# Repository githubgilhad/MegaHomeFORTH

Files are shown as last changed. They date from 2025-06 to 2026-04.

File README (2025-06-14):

Mega Home Computer with FORTH - based on ATmega2560 - step to graphic card for HD6309 - VGA, RCA, PS/2

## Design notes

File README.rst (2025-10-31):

.. vim: set ft=rst noexpandtab fileencoding=utf-8 nomodified   wrap textwidth=0 foldmethod=marker foldmarker={{{,}}} foldcolumn=4 ruler showcmd lcs=tab\:|- list tabstop=8 noexpandtab nosmarttab softtabstop=0 shiftwidth=0 linebreak showbreak=»\

.. |Ohm| raw:: html

	Ω

.. |kOhm| raw:: html

	kΩ

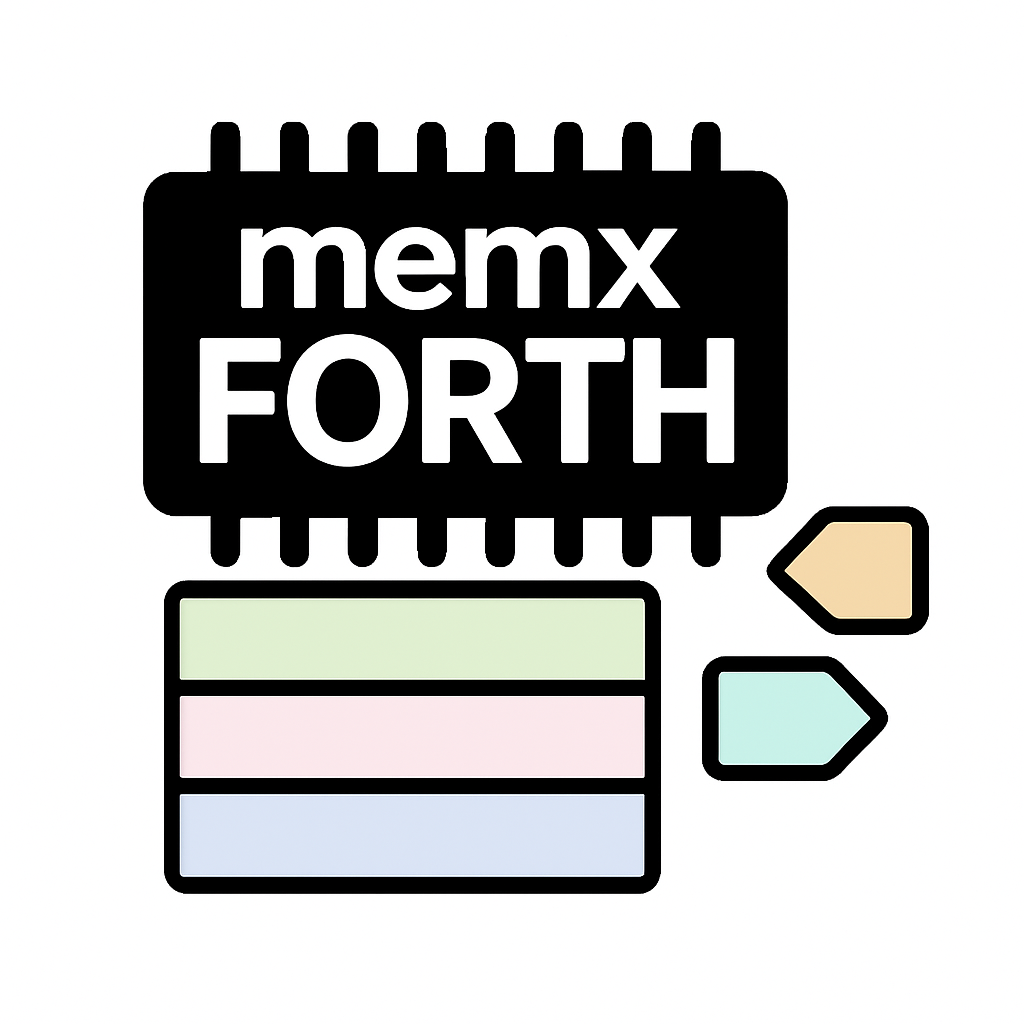
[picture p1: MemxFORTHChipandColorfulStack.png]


Many thanks to `PCBway <https://www.pcbway.com/>`__, which sponsored this project by manufacturing the PCB for free. The code for this PCB is **W828834AS5P3** and I created it as free project  here `<https://www.pcbway.com/project/shareproject/W828834AS5P3_MegaHomeFORTH_MHF_001_cheap_computer_with_VGA_PS_2_SD_card_ba_2abd40e2.html>`__

MHF-002
========

Actual version is `MHF-002 <HW/KiCad/MHF-002/>`__ with over 75 improvements (see `documentation <docs/MHF-002/README.rst>`__)

**MHF-001** results:
====================

The **PCBway** PCB was excelent. Communications with PCBway was easy and straightforward, PCB was made exactly to my specification and it was delivered in good time too. Packaging was standart and the PCB was perfect. It was easy to solder, desolder, resolder parts as the testing went and the PCB was not damaged even with some parts (like USB connector) was resoldered many times.

The PCB was perfect, there is nothing what could be improved on the manufacturing. Bad design decisions are problem on my side, PCBway could not discover or prevent them :)

**I will fully recomend PCBway as PCB manufacturer.**

Also their sponsorship encouraged me to speed progress on this project and to write about it, which is really important part. I thank PCBway for their encouragement.

I did run into lot of problems in this project, many of them was on my part, some not (none on PCBway part)

- I found error in compiler (it is fixed now and was really obscure `<https://gcc.gnu.org/bugzilla/show_bug.cgi?id=119989>`__ )
- CH341G is not fully supported in kernel. There is an unofficial fix, but I may add another option too. And I need way to disable this chip alltogether, to be able use Serial + DTR + line flow over connector (and not fight signalling from chip)
- I underestimated how difficult is to reliably handsolder MCU and memories - I will make better footprints for it, and for USB too
- I had no testing program for the HW
- bad understanding of some technicalities (like that RTS/CTS are crossed between MCU and CH341G in similar way as RX/TX)
- bad planning for port usage 
	- VGA output must be on lower port, which allows **OUT** instruction - **STS** is one tick slower and it matter
	- CTS(in) should be on some Pin Change Interrupt pin
- **74HC165** is level driven so manipulating it "manually" leads to doubled first bit value, I will use **74KC166**, which is edge driven, to prevent this problem
- USB connector is better to be massive (like USB A) and easily repaired (as it is physically manipulated often) - and rather be on small module for repairability
- I need even better testability - more pinheaders, add GND (and maybe +5V) to each connector etc...
- see `<https://github.com/githubgilhad/MegaHomeFORTH/tree/master/docs/MHF-001#errata-and-improvements>`__ for more details

All in all - I will make another PCB. This one is OK, but I have much better design ideas now.

MegaHomeFORTH
=============

Mega Home Computer with FORTH on ATmega2560 - step to graphic card for HD6309 - VGA, RCA, PS/2 - see `Larger Picture`_

This project is more about the HW part of solution (but with enought SW to be fully tested and expanded (will be build on the way)).

Look at `MHF-001 <docs/MHF-001/>`__ for actual progress just now

Index
-----

- `MegaHomeFORTH`_
	- `Project Goals`_
	- `Larger Picture`_
	- `Progress`_

Project Goals
==============

Depending on how much components will be soldered to the PCB, it could offer many things (at cost of using some pins):

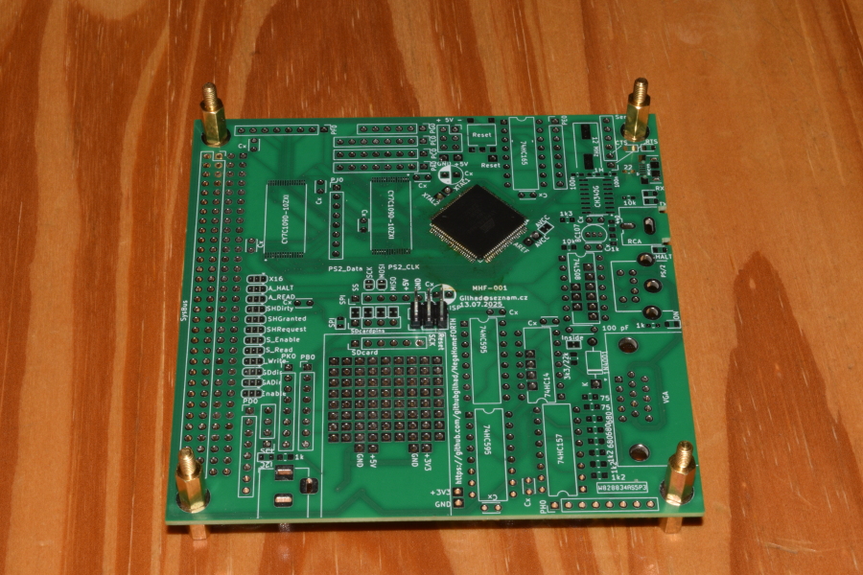
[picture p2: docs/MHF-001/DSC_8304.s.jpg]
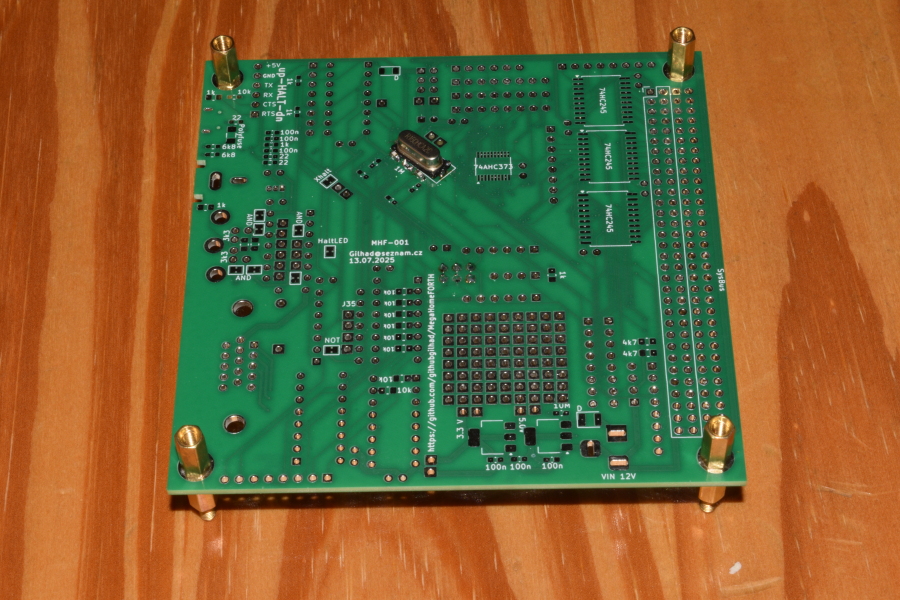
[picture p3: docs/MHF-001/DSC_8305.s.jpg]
- full breakout of ATmega2560 - like Arduino Mega, but **all** pins accessible - simply, plain, 86 I/O pins    `blink_all <https://github.com/githubgilhad/memxFORTH-asm/tree/master/SW/progs/demo/blink_all>`__ 
- USB serial connection - 2 pins
- memory extended to 64 kB RAM - at cost of 16+4 pins
- another 128 kB RAM (somehow) accessible - another 24+3 pins
	- and shared over bus with HD6309/6502/other 8 bit computer - +5pins?
- VGA output (~40x25 characters text screen or 320x200 B/W graphic) - 8+3 pins
	- 4+4 bits forefround+background colors for full text lines (or single graphic lines) - 8 pins
- RCA ("composite") B/W output ( can do this OR VGA, not both at the same time, but may switch it SW way ) - 3 pins
- PS/2 input - 2 or 8+1 pins (much smoother operation)
- SD card reader (may interfere with video interrupts?) - 4pins

In full power it can serve as SBC (Single Board Computer) - or as inteligent Video+Keyboard card for 8 bit computer.

Larger Picture
===============

This project is based on:

- `NanoHomeComputer <https://github.com/githubgilhad/NanoHomeComputer>`__ for HW part
	-  which is based on `Squeezing Water from Stone 3: Arduino Nano + 1(!) Logic IC = Computer with VGA and PS/2 <https://github.com/slu4coder/YouTube>`__ and `Composite video from Arduino UNO <https://www.youtube.com/watch?v=Th18tLP86WQ>`__
- `memxFORTH-core <https://github.com/githubgilhad/memxFORTH-core>`__ for using 24bit pointers on ATmega2560
- `pcFORTH-core <https://github.com/githubgilhad/pcFORTH-core.git>`__ for bigger FORTH implementation
- many different internet sources, discussions and hints

It is another step to retrocomputer based on HD6309 - see `some <http://comp24.gilhad.cz/Comp24-specification.html>`__ `pages <http://comp24.gilhad.cz/documentation/Comp24.html>`__ for basic idea.

Video part was successfully tested on `NanoHomeComputer <https://github.com/githubgilhad/NanoHomeComputer>`__, but ATmega328P with only 2kB RAM and 32kB Flash was too limiting for larger project

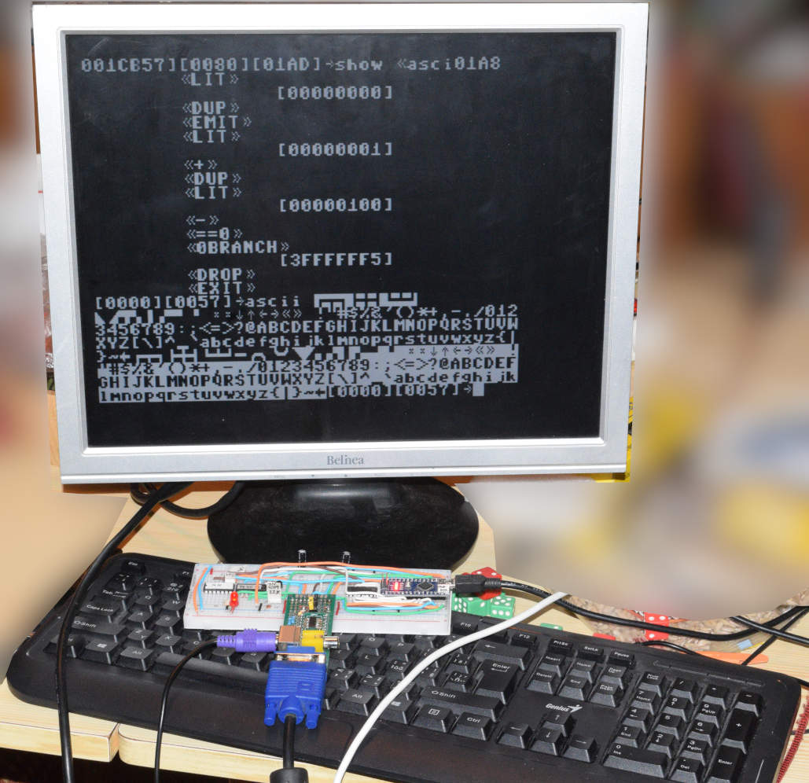
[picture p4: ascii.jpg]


Progress
========

`MHF-001 <docs/MHF-001/>`__

Soldering parts and testing.

Done:

* get Arduino Mega Pro
* get 16MHz to output
* map pins in NanoHomeComputer
* map pins on ATmega2560
* map timers in NanoHomeComputer
* assign VGA/RCA/PS2 pins to ATmega2560
* test VGA output
* test RCA output
* test PS/2 direct input
* test PS/2 8bit input
* assign rest pins on ATmega2560
* draw schema `<HW/KiCad/MHF-001/MHF-001.pdf>`_
* draw PCB
* order PCB
* get PCB manufactured `<HW/KiCad/MHF-001/output.zip>`_

Next steps:

* solder component   ... see `MHF-001 <docs/MHF-001/>`__

* test each goal ... see `MHF-001 <docs/MHF-001/>`__
* physical tests
* programming
* enjoy :)

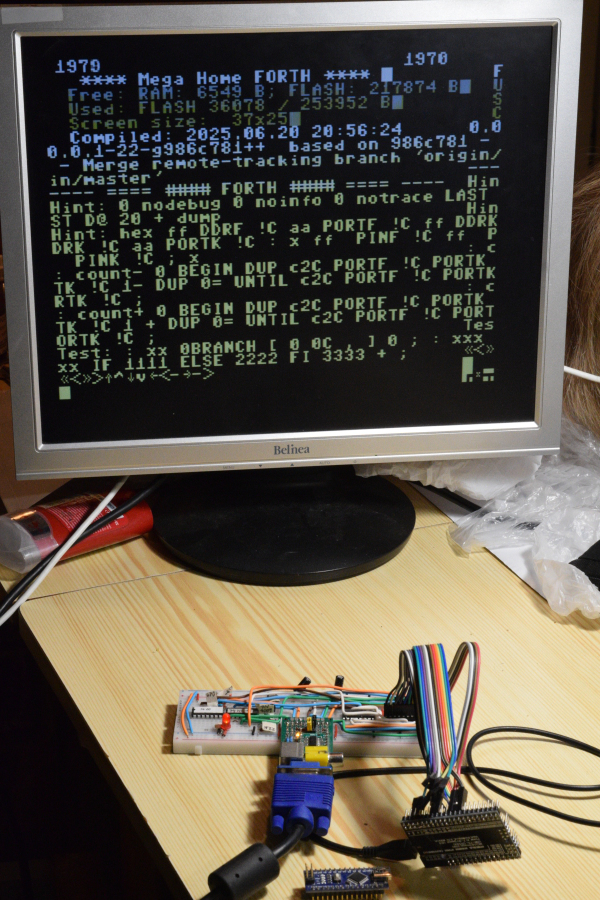
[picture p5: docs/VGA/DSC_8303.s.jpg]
Something works now: 

see `Progress <docs/Progress.rst>`__ and `Journal <docs/Journal.rst>`__

I have some ideas, but it would need lot of work to bring it into life

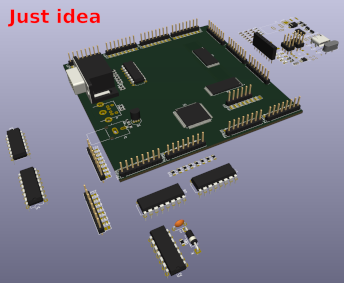
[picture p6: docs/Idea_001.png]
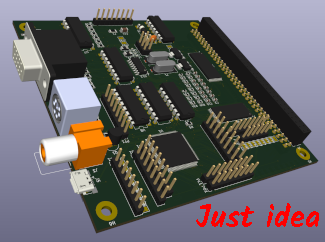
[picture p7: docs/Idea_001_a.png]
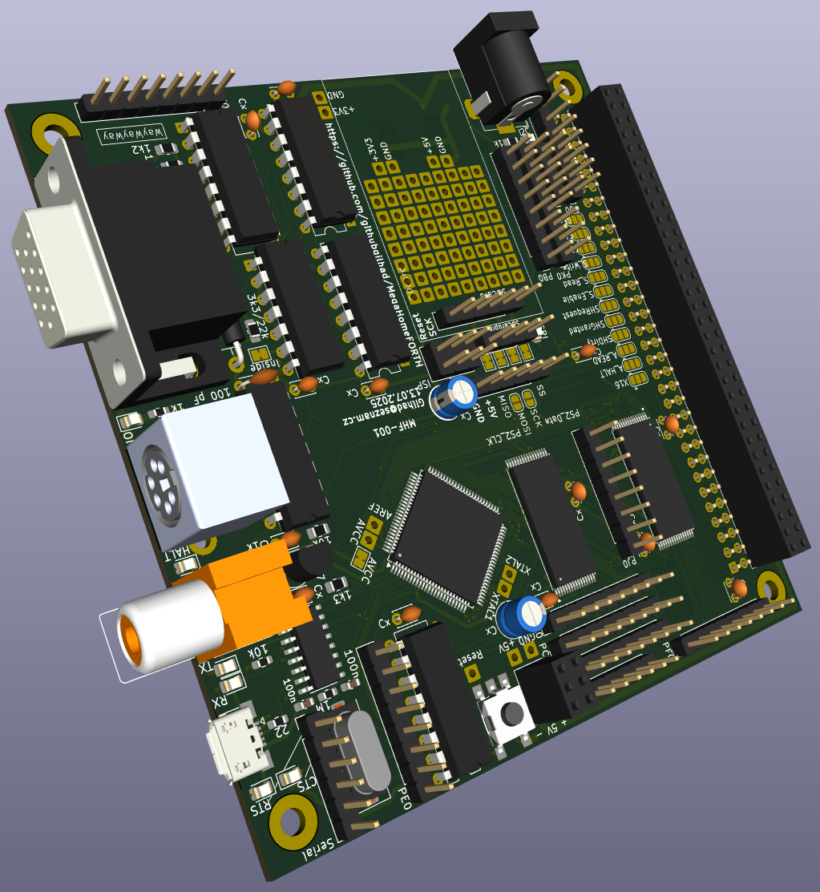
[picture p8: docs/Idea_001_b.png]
  

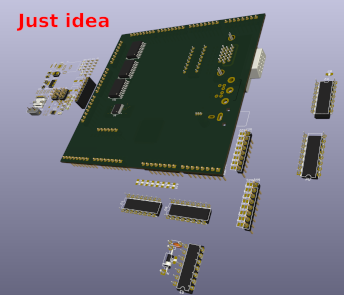
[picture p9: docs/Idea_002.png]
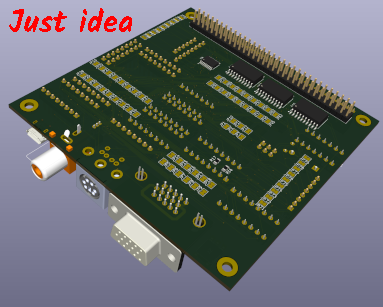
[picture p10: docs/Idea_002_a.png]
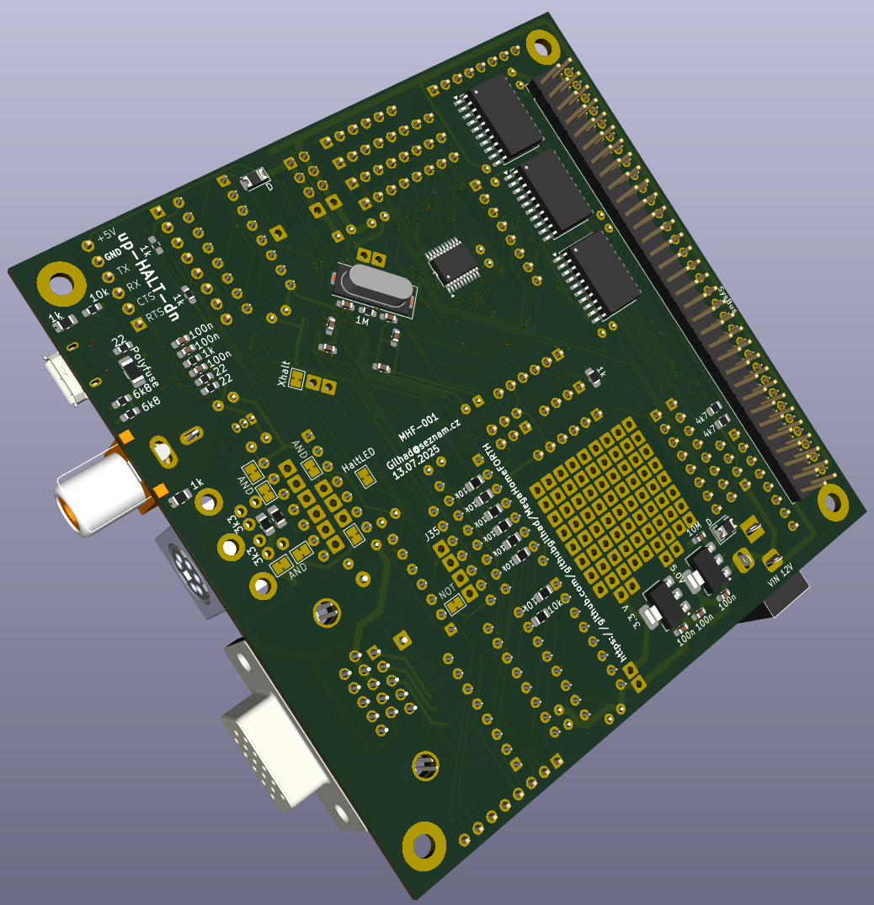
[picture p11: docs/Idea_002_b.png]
  

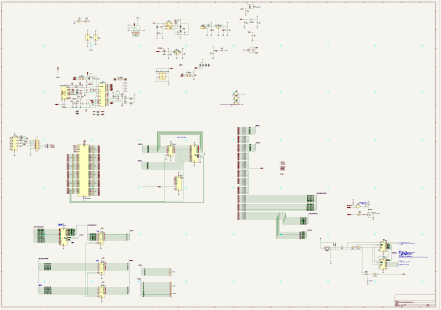
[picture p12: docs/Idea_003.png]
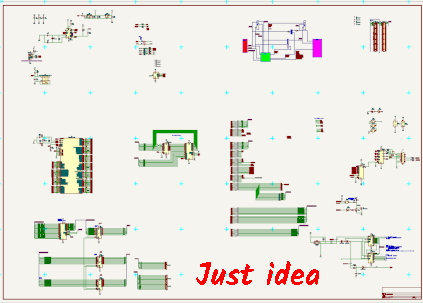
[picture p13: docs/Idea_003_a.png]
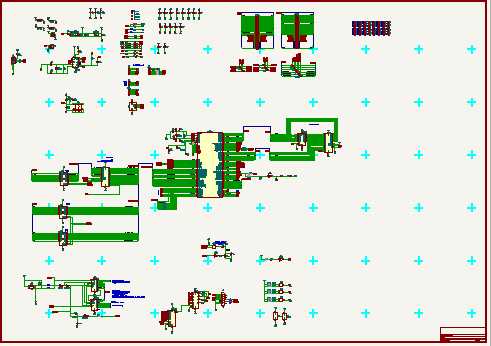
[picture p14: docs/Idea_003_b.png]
  



























License
-------
GPL 2 or GPL 3 - choose the one that suits your needs.

Author
------
Gilhad - 2025

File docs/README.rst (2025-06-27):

See `Progress <Progress.rst>`__ and `Journal <Journal.rst>`__ ( `top <../README.rst>`__ )

I have some ideas, but it would need lot of work to bring it into life

Two sided PCB with VGA, RCA and PS/2 connectors on front edge, system connector on back edge and I/O connectors along sides



I need two sides to fit everything I want to have



The schema is evolving just now



Some documentation:
===================

`<Pins.rst>`__

Some temporary notes:
=====================

* The CPU needs 4 cycles to prepare itself for servicing the interrupt (save the program counter, load the interrupt vector and clear the I bit in SREG). The interrupt vector itself is a jmp instruction that takes 2 cycles. When the ISR is done, it executes the reti instruction (return from interrupt) that takes 4 cycles. 
* `74AHC373 <https://cz.farnell.com/nexperia/74ahc373pw-118/latch-d-type-transp-3-state-tssop/dp/2445110>`__ NEXPERIA  74AHC373PW,118  Latch, AHC Family, 74AHC373, D Type Transparent, Tri State Inverted, 25 mA, TSSOP
* `RAM <https://cz.farnell.com/infineon/cy7c109d-10zxi/sram-asynchronous-1mbit-tsop-i/dp/2115420>`__ INFINEON  CY7C109D-10ZXI  IC, SRAM, 1 Mbit, 128K x 8bit, 10 ns Access Time, Parallel Interface, 4.5 V to 5.5 V supply, TSOP-32

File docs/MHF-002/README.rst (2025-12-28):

.. vim: set ft=rst noexpandtab fileencoding=utf-8 nomodified   wrap textwidth=0 foldmethod=marker foldmarker={{{,}}} foldcolumn=4 ruler showcmd lcs=tab\:|- list tabstop=8 noexpandtab nosmarttab softtabstop=0 shiftwidth=0 linebreak showbreak=»\

.. |Ohm| raw:: html

	Ω

.. |kOhm| raw:: html

	kΩ



MegaHomeFORTH - MHF-001
========================

Mega Home Computer with FORTH on ATmega2560 - step to graphic card for HD6309 - VGA, RCA, PS/2 - see `Larger Picture`_

This project is more about the HW part of solution (but with enought SW to be fully tested and expanded (will be build on the way)).

See `<../../HW/KiCad/MHF-002/>`_

Errata:
================================================================================
* all 10 |kOhm| resistors in PS/2 (8+2) should be rather 1 |kOhm| (otherwise it take too long for reading values, like 10 clock cycles)

Changes from MHF-001
================================================================================

* switched to SMD logical gates for more space avaiable
* switched from 2 to 4 layers (internal are POWER exclusively) for better distribution of power and reducing noise
* added more **Cx** capacitors, but cannont fit them exactly at each power pin for place restrictions - at least they are near and many
* swaped **PORTL -- PORTF** ( VGA Data - Shared Data) for OUT instruction
* moved **SYNC_RCA** to **PE4** (SYNC_VGA) for OC3B
* moved **SUPPRESS** to **PF3** (with VGA Data) just follow suit
* swaped **RTS/CTS -- X16/PS2_OE** (PE2,3 -- PPB4,5) for PCINT4,5
* **74HC165 -> 74HC166** for synchronous load
* added resistors to PS2_Clock and PS2_Data path to prevent conflict
* CP2102 board interface + rewire pins
* isolate USB by solder-jumpers
* SDCard added
* **74AHC373 -> 74AHC573** for better routing
* The transistor is `S8050`, not BC107
* the Inside capacitor is `10 nF`, not 100pF
* the resistor is 20 |kOhm|, no 3k3/22k
* breakout VGA, PS/2 and RCA conectors to pinheader
* LED on `PB7` aka `SYSTEM_LED` for bootloader may be usefull (even when it is `VGA_latch` so it will shine with VGA attached - like 10 |kOhm| green LED?)
* LED on `Reset` may help to debug serial communication (`DTR` pin via capacitor)
* Reset button changed to cheap common Arduino switch
* breakout all USB pins to its own pinheader (and USB A can be attached with just piece of stripboard)
* included CP2102 module
* switched `X16` and `RTS` lines, so `RTS` could use interrupt on low. (RTS can be also ignored, or checked on regular schedule, like 50/sec in SW)
	* `CTS` and `RTS` on atmega and on CH340G should be crossed the same way as RX/TX - **RTS** on **CH340G** is **OUTPUT**
* RX0,TX0 RTS0,CTS0 are **Arduino** pins/points of view, should go to crossed ports on chips Arduino.RX0=CH340G.TX, Arduino.RTS0=CH340G.CTS
* enabled isolation of  **CH340G** via closed solderpads (to freely use Serial headers)
* breakout `DTR` to Serial headers
* for `ISCP` it is needed to set `hfuse` to 0xD9 (run program) instead of 0xD8 (run bootloader) as ICSP destroy bootloader (or what)
* make my own footprints with longer pads for SMD ICs to make soldering easier
* PROBLEM - 74HC165 doubles the first bit (as it is shifted out and latched again before level latch returns inactive) and so ONECHAR have to be 9 clocks long (or lose the last bit) - 74HC166 should be better (as it is edge latched) but now I cannot feed it each 8 clocks, so last bit will be errornerous
	* I should use some port A..F for VGA data **OUT** instead of **STS** too, to fit in 8 clocks
* SD card reader needed little edge filing to not collide with ISCP connector and 3V3 connector - make little more place for it next time and add mounting holes in corner. Sitting just on Koptan tape looks good. (Alternatively unsolder all components and move them on PCB directly. Qualify MISO and MOSI (and maybe clock too) by CS, let CS go inside all the time. Use another pin than ISCP)
* `blink_all <https://github.com/githubgilhad/memxFORTH-asm/tree/master/SW/progs/demo/blink_all>`__  from `memxFORTH-asm <https://github.com/githubgilhad/memxFORTH-asm>`__  may be usefull
* each port connector should have at least `GND`, and ideally `+5V` too - for LEDS and other use (just GND, the +5V are not so needed and there are some free standing around)
* possibly enable to enable SBC use Shared RAM via open solderpads for signals X-A-B interconnected
* the label **"+ 5V -"** was wrong rotated (probabelly some autocorrect on schema -> PCB), fixed and repeatadly checked to be right (no problems found)
* mark areas on SysBus, separate blocks as Data, Address, A, B, Power, MasterReset  with lines
* added MasterReset with diode from Reset to SysBus
* added emitor follower to I2C LED
* added 8 TestPointProbes pads between D-Latch and RAM
* reordered internal pin assignement for RAMs for better routing
* moved PS/2 PsDat to port with IN instructon
* moved RCA Sync and Suppress to share pins with VGA
* switch for using 74HC166 for RCA (marked **40** for old method and **80** for new one after max number of characters per line) - not tested, but Grant Searle uses something similar
* marked PS/2, VGA, RCA, USB areas of PCB on both sides
* better marking of parts and jumpers
* 6 **WS2812B** LEDs for status signalling as "debug diodes" on **X_SHARE_GRANTED** as leds use specific output signal, while X_SHARE_GRANTED is input, which will not pulse on the right frequency. Separated both by 1k resistors.
* **SBC** jumpers for easier (and more consistent) configuration as SBC
* **/VGA_Enabled** active **LOW** enables VGA output. If disabled, VGA gets only black color, regardless of **VGA_Data[0..7]** and **VGA Colors [0..7]** so **PORT F** and **PORT H** may be used for anything else

Some numbers
================================================================================

10x10cm, 4 layers, around 153 parts, 338 vias, 11.4m of tracks, 1174 pads, 378 nets, 4069 segments, 164 solder points, bridges, pinholes, probes and similar copper pieces :)
3x AND, 1x NOT gates was unused and are breaked out for user, 8x9 pinholes as universal expansion area (under SD Card)

Next time changes
================================================================================

* put PS/2 Clock before NOT-NOT, so MCU can also talk to keyboard (Caps,Num, Scrl LEDs)
* mark power +5V 3V3 and both GND from bottom, where it will be readable (universal solder board under SD card)
* pulldowns RTS, CTS for default communication enabled
* Debug LEDS should have pin at end of line to attach even more of them

License
-------
GPL 2 or GPL 3 - choose the one that suits your needs.

Author
------
Gilhad - 2025

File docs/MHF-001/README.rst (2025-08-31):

.. vim: set ft=rst noexpandtab fileencoding=utf-8 nomodified   wrap textwidth=0 foldmethod=marker foldmarker={{{,}}} foldcolumn=4 ruler showcmd lcs=tab\:|- list tabstop=8 noexpandtab nosmarttab softtabstop=0 shiftwidth=0 linebreak showbreak=»\

.. |Ohm| raw:: html

	Ω

.. |kOhm| raw:: html

	kΩ



Many thanks to `PCBway <https://www.pcbway.com/>`__, which sponsored this project by manufacturing the PCB for free. The code for this PCB is **W828834AS5P3** and I will create it as free project after I populate it with all parts and get it to work somehow (= I will write SW for demonstrating at least some functionality).

MegaHomeFORTH - MHF-001
========================

Mega Home Computer with FORTH on ATmega2560 - step to graphic card for HD6309 - VGA, RCA, PS/2 - see `Larger Picture`_

This project is more about the HW part of solution (but with enought SW to be fully tested and expanded (will be build on the way)).

This is first PCB manufactured.

See `<../../HW/KiCad/MHF-001/>`_

Index
-----

- `MegaHomeFORTH`_
	- `Project Goals`_
	- `Also discovered`_
	- `Errata and Improvements`_
	- `Larger Picture`_
	- `Progress`_

Project Goals
==============

Depending on how much components will be soldered to the PCB, it could offer many things (at cost of using some pins):

- full breakout of ATmega2560 - like Arduino Mega, but **all** pins accessible - simply, plain, 86 I/O pins 
	 
	`blink_all <https://github.com/githubgilhad/memxFORTH-asm/tree/master/SW/progs/demo/blink_all>`__ 
- USB serial connection - 2 pins
- memory extended to 64 kB RAM - at cost of 16+4 pins
- another 128 kB RAM (somehow) accessible - another 24+3 pins
	- and shared over bus with HD6309/6502/other 8 bit computer - +5pins?
- VGA output (~40x25 characters text screen or 320x200 B/W graphic) - 8+3 pins
	- 4+4 bits forefround+background colors for full text lines (or single graphic lines) - 8 pins
- RCA ("composite") B/W output ( can do this OR VGA, not both at the same time, but may switch it SW way ) - 3 pins
- PS/2 input - 2 or 8+1 pins (much smoother operation)
- SD card reader (may interfere with video interrupts?) - 4pins

In full power it can serve as SBC (Single Board Computer) - or as inteligent Video+Keyboard card for 8 bit computer.

Also discovered
================

* VGA timing `<../VGA/>`_
* SDA card `<../../HW/Foto/SD_card/>`_
* Arduino Mega Pro - ATmega2560 `<../../HW/KiCad/ATmega2560-MegaPro-001/>`_

Errata and Improvements
========================

* fix for **__memx** pointers usage `<https://gcc.gnu.org/bugzilla/show_bug.cgi?id=119989>`__ (already applied)
* fix for kernel driver **drivers/usb/serial/ch341.c** - `<ch341.patch>`__ (DIY) `<https://bugzilla.kernel.org/show_bug.cgi?id=197109>`__
* the label **"+ 5V -"** is wrong rotated (probabelly some autocorrect on schema -> PCB)
* The transistor is `S8050`, not BC107
* the Inside capacitor is `10 nF`, not 100pF
* the resistor is 20 |kOhm|, no 3k3/22k
* (and maybe it does not matter)
* I destroyed the reset button when unsoldering it, so I improvised and used clasical Arduino pushbutton, bend its legs and solder it there - it works
* I left blink program inside, while soldering all gates chips, which is bad, as there are outputs too. So I hold the reset, until I ISPloaded new program.
* I also destroyed USB connector while desoldering it, so I bought some replacements, should arrive after month or so ... I may improvise normal Serial connection or something else.
	* breakout all USB pins to its own pinheader
	* include USB A male connector for better durability somewhere (or at least module like SD card reader)
* breakout VGA, PS/2 and RCA conectors to pinheader
* possibly enable to enable SBC use Shared RAM via open solderpads for signals X-A-B interconnected
* It would be better to switch `X16` and `RTS` lines, so `RTS` could use interrupt on low. (RTS can be also ignored, or checked on regular schedule, like 50/sec in SW)
	* `CTS` and `RTS` on atmega and on CH340G should be crossed the same way as RX/TX - **RTS** on **CH340G** is **OUTPUT**
	* enable isolate  **CH340G** via closed solderpads (to freely use Serial headers)
	* breakout `DTR` to Serial headers
* LED on `PB7` aka `SYSTEM_LED` for bootloader may be usefull (even when it is `VGA_latch` so it will shine with VGA attached - like 10 |kOhm| green LED?)
* LED on `Reset` may help to debug serial communication (`DTR` pin via capacitor)
* for `ISCP` it is needed to set `hfuse` to 0xD9 (run program) instead of 0xD8 (run bootloader) as ICSP destroy bootloader (or what)
* `blink_all <https://github.com/githubgilhad/memxFORTH-asm/tree/master/SW/progs/demo/blink_all>`__  from `memxFORTH-asm <https://github.com/githubgilhad/memxFORTH-asm>`__  may be usefull
* make my own footprints with longer pads for SMD ICs to make soldering easier
* PROBLEM - 74HC165 doubles the first bit (as it is shifted out and latched again before level latch returns inactive) and so ONECHAR have to be 9 clocks long (or lose the last bit) - 74HC166 should be better (as it is edge latched) but now I cannot feed it each 8 clocks, so last bit will be errornerous
	* I should use some port A..F for VGA data **out** instead of **STS** too, to fit in 8 clocks
* each port connector should have at least `GND`, and ideally `+5V` too - for LEDS and other use
* SD card reader needed little edge filing to not collide with ISCP connector and 3V3 connector - make little more place for it next time and add mounting holes in corner. Sitting just on Koptan tape looks good. (Alternatively unsolder all components and move them on PCB directly. Qualify MISO and MOSI (and maybe clock too) by CS, let CS go inside all the time. Use another pin than ISCP)
* mark areas on SysBus, at least separate blocks as Data, Address, A, B, Other with lines
* WARNING: When manually manipulating external RAM, there MUST be NOP (or other pause) between enabling Read and actually reading the value, like this  **cbi PORTG,2; NOP; in r24,PINA** (it probably is **NOT** problem for automatic use. just be sure to initialise all.)

Larger Picture
===============

This project is based on:

- `NanoHomeComputer <https://github.com/githubgilhad/NanoHomeComputer>`__ for HW part
	-  which is based on `Squeezing Water from Stone 3: Arduino Nano + 1(!) Logic IC = Computer with VGA and PS/2 <https://github.com/slu4coder/YouTube>`__ and `Composite video from Arduino UNO <https://www.youtube.com/watch?v=Th18tLP86WQ>`__
- `memxFORTH-core <https://github.com/githubgilhad/memxFORTH-core>`__ for using 24bit pointers on ATmega2560
- `pcFORTH-core <https://github.com/githubgilhad/pcFORTH-core.git>`__ for bigger FORTH implementation
- many different internet sources, discussions and hints

It is another step to retrocomputer based on HD6309 - see `some <http://comp24.gilhad.cz/Comp24-specification.html>`__ `pages <http://comp24.gilhad.cz/documentation/Comp24.html>`__ for basic idea.

Video part was successfully tested on `NanoHomeComputer <https://github.com/githubgilhad/NanoHomeComputer>`__, but ATmega328P with only 2kB RAM and 32kB Flash was too limiting for larger project



Progress
========

Soldering parts and testing.

Done:

* get Arduino Mega Pro
* get 16MHz to output
* map pins in NanoHomeComputer
* map pins on ATmega2560
* map timers in NanoHomeComputer
* assign VGA/RCA/PS2 pins to ATmega2560
* test VGA output
* test RCA output
* test PS/2 direct input
* test PS/2 8bit input
* assign rest pins on ATmega2560
* draw schema `<HW/KiCad/MHF-001/MHF-001.pdf>`_
* draw PCB
* order PCB
* get PCB manufactured `<HW/KiCad/MHF-001/output.zip>`_

* solder component - first we re-use what we have on Arduino Mega Pro (I will use some spacer screws to keep it from contact with table while testing):
	* Minimal setup - just ISCP conector, ATmega2560, crystal and its capacitors - but it works and we have working breakout of all pins -  
		 
	* add LEDs and resistors, and we can also see something :) -
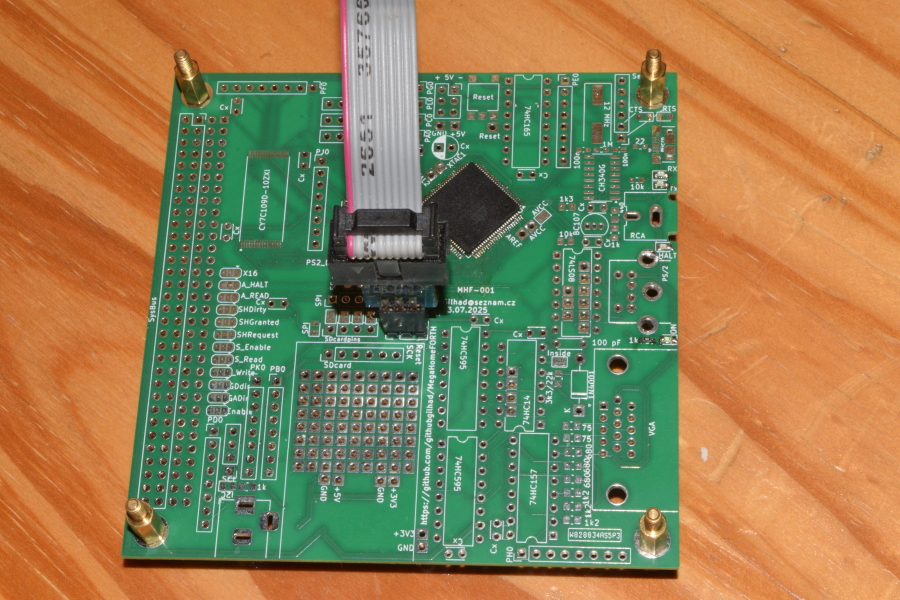
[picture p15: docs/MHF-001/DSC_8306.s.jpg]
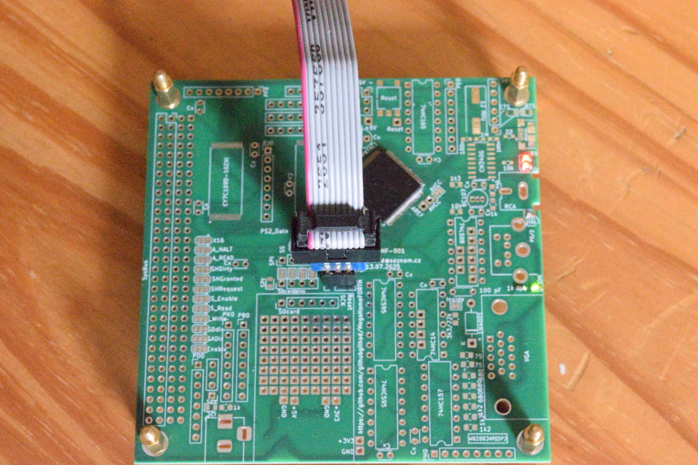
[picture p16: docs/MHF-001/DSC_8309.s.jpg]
		 
	* add USB block - oops, I destroyed the USB connector and Reset button while desoldering, I must find/buy some other -
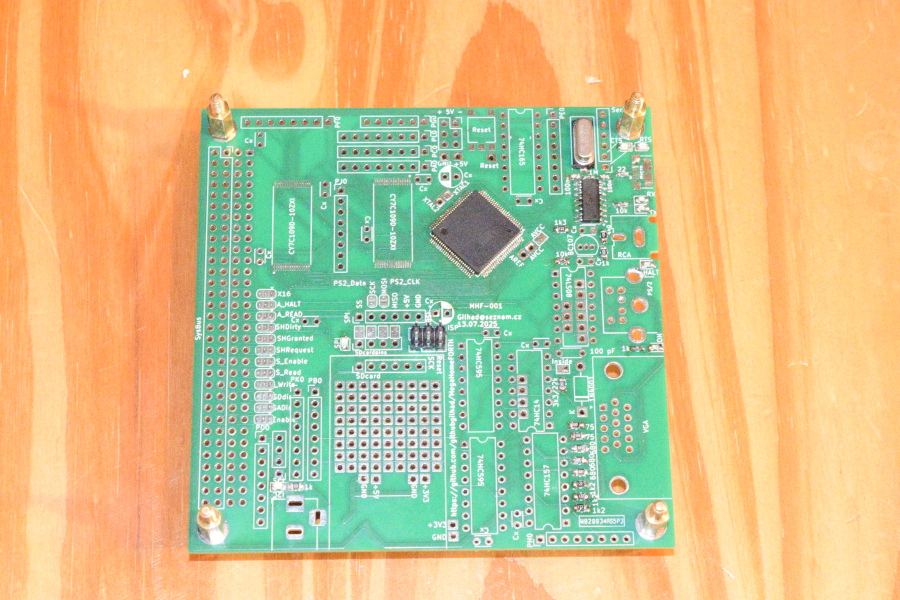
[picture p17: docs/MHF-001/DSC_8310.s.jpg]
		 
	* add voltage stabilisers (and add all other resistors too) - no more parts from Mega Pro left - 
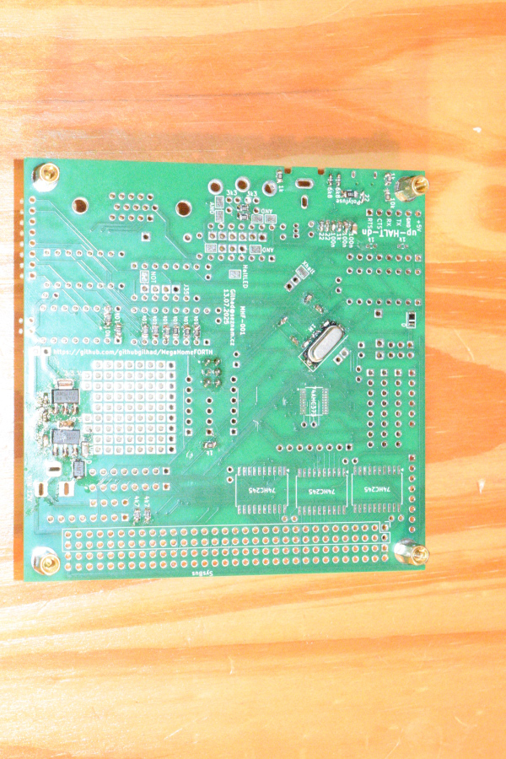
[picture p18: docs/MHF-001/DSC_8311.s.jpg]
		
	* add connectors and ICs for VGA and PS/2 (I am out of 74HC08 for RCA, need to buy it too) - and add some LEDs to unused ports for testing  
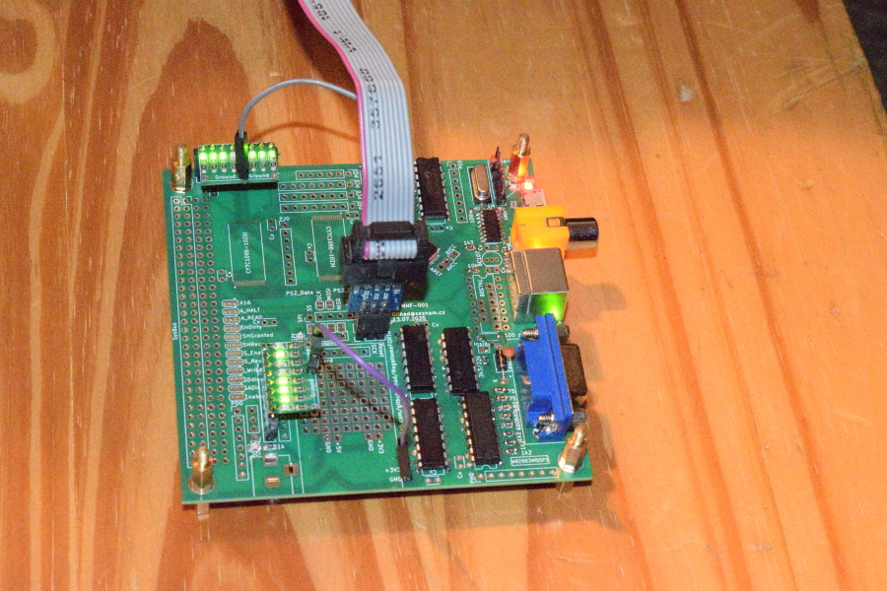
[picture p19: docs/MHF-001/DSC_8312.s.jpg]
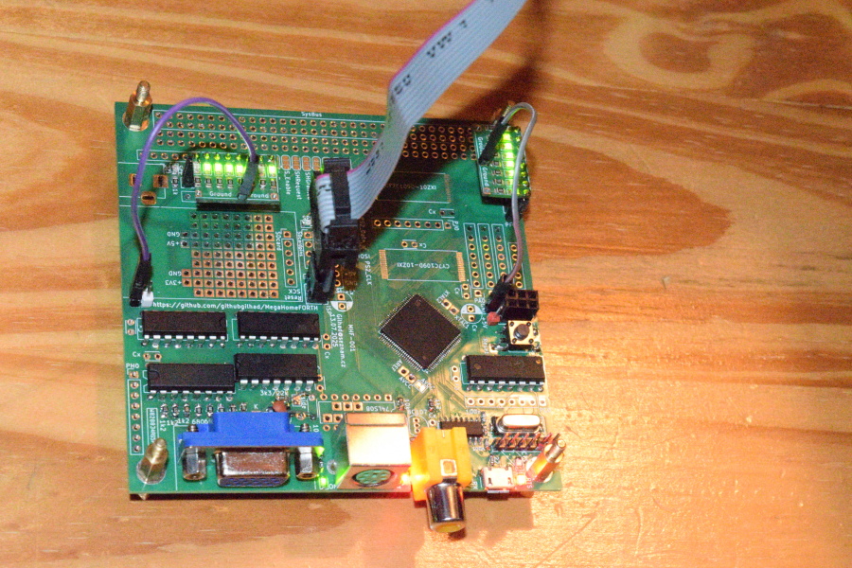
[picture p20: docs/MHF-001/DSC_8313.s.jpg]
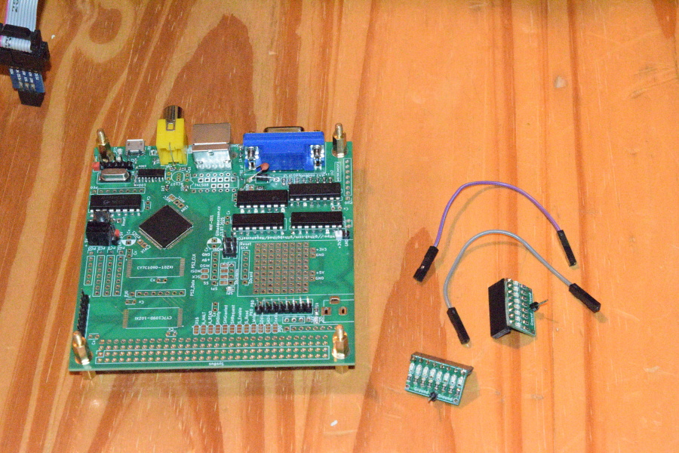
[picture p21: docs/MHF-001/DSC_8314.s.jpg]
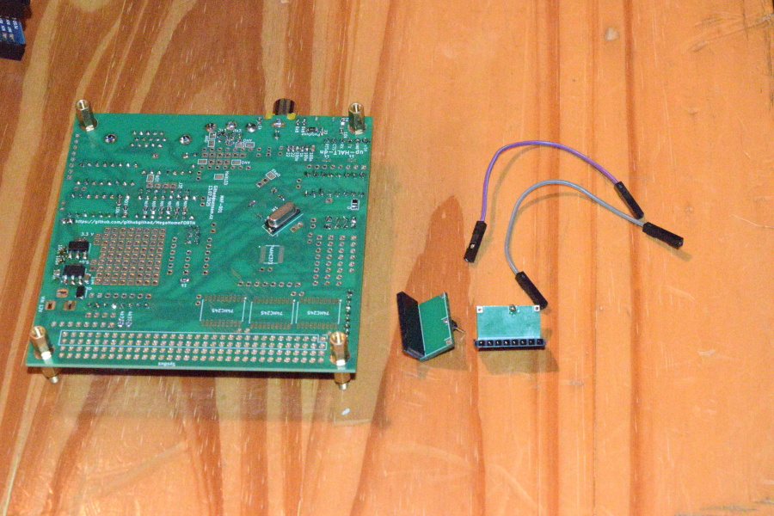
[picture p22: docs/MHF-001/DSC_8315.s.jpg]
		   
		
		* I improvised Reset button - I bend legs of Arduino push button and solder it there - look stable and usable
		* I use lot of LEDs for testing, I made small PCBs usually for 8xLED + 8x 1 |kOhm| resistors, here I used sockets instead of pins, as I want pin headers for this SBC/card
		* VGA, PS/2 - now works
		* I also improved the VGA.S routine, so there are no color artefacts and the size is full 40x25 characters
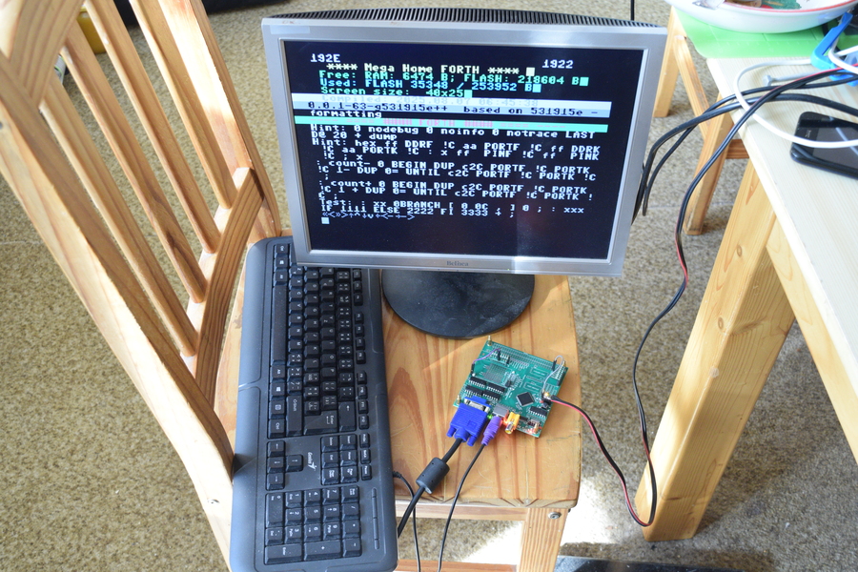
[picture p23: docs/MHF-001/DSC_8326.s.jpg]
			
	* I connected CD card reader and it works (when tested without VGA running), but there are conflict with interrupts and it uses millis() for timeouts (witch do not run without interrupts) - so some SW solution is needed (maybe emulate millis and run SD only in vertical blanks? - TODO)

Next steps:

* Test Reset over DTR
* test each goal -
	* Minimal setup works - I can program it and with some LEDs I can blink them on my will
	* Arduino Mega equivalent - not works yet, some problems with USB Serial - so I desoldered the 22 |Ohm| resistors on M8TXD/M8RXD and will try normal Serial instead (after I find some convertor and write programs for that)
	* RCA - waiting for IC

* physical tests
* programming
* enjoy :)

Something works now: 

see `Progress <../Progress.rst>`__ and `Journal <docs/Journal.rst>`__

I have some ideas, but it would need lot of work to bring it into life

  

  

  













































License
-------
GPL 2 or GPL 3 - choose the one that suits your needs.

Author
------
Gilhad - 2025

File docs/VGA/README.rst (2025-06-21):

VGA theory and pratice
======================

* Timer 1 generates HSYNC via fast PWM, prescaler x1, period 512 ticks - 32 µs per line, should be OK for VGA (cca `31.25 kHz`).
* Timer 1 generates TIMER1_OVF interrupt for VGA.S to draw lines
* Timer 3 generates VSYNC via fast PWM, prescaler x256, period 260 ticks - 16.64ms per screen, 2 line long sync (64 µs)
* Timer 3 generates TIMER3_OVF interrupt for setting vline=0 and frames++

* HSYNC: low 3.8 µs, high ~28.2 µs - total period `~32 µs` (close to VGA standard for 640×480 @60Hz).
* VSYNC: low 64 µs, high 16.4 ms - total period `~16.464 ms` (`~60.8 Hz`), so timing is fine.
* What standard VGA expects:
* Vertical front porch (~10 lines), then VSYNC low for 2 or 3 full HSYNC periods, then vertical back porch (~33 lines), then visible lines.
* It’s normal for VSYNC to go low during HSYNCs and return high aligned to the HSYNC period
* We have VSYNC (set vline to 0), HSYNC (increase vline. If vline/2 - 30 < 200 draw line (every line is drawn twice). Back porch is around 60 lines (not sure exactly as managed from different interrupts), front porch should be around 60 lines (520-460), so it should fit.
* We use 320x200, but each line is doubled, so effectively we send 320x400 pixels signal.
* Problems:
	* interrupt waits for current instruction finish (and it may be 1-3 clocks), so it starts little randomly
		* read prescaler x1 timer count, AND with 3 and use branches to synchronise (VGA.S part with n1-n3 labels - branch not taken is 1 clock, taken is 2 clocks so we can compensate for 0-3 clocks)
		* but it depends on all instructions before, so there is few `nop` in front so the allignment is moved to right phase (bad phase makes some lines misalligned by half of character )
	* sync pulses are generated in HW independently, but pixels cannot go immediately out, so few `nop` are also after this part to move pixel output safely after end of Hsync (starting soon make unstable picture)
	* too long interrupt also make picture unstable, so the number of ouput characters may be 40, or less, if there is also other work to do. (comment out few `ONECHAR` to see, if it is the problem)

* This is my test setting - breadboard from `NanoHomeFORTH <https://github.com/githubgilhad/NanoHomeComputer>`__ and Arduino Mega Pro temporally used as ATmega2560 breakout with some wires everywhere 
	
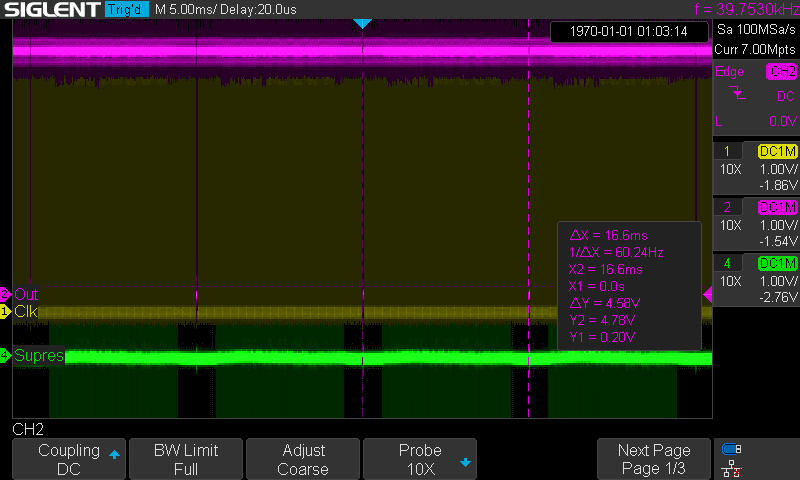
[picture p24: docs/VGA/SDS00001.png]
* Pink VSYNC with 16.4 ms period 
* Width of Vsync pulse is 64 µs 
* Yellow HSYNC have 3.8 µs pulse 
* and Hsync period is 32 µs 
* Green pixels are 60 lines from VSYNC pulse 
* Some lines have lot of data, some not so much 
* 40 characters, 8 pixels each (and 8 clocks each) take 20 µs 
* start about 2.8 µs after end of HSYNC 
* finish about 3 µs before start of HSYNC 





















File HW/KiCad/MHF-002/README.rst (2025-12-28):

.. vim: ft=rst noexpandtab fileencoding=utf-8 nomodified   wrap textwidth=0 foldmethod=marker foldmarker={{{,}}} foldcolumn=4 ruler showcmd lcs=tab\:|- list tabstop=8 noexpandtab nosmarttab softtabstop=0 shiftwidth=0 linebreak showbreak=--»\ 

.. |Ohm| raw:: html

	Ω

.. |kOhm| raw:: html

	kΩ



MegaHomeFORTH MHF-002
=====================

This is next iteration of `MegaHomeFORTH MHF-001 <https://github.com/githubgilhad/MegaHomeFORTH/tree/MHF-001>`__

MHF-001 was sponsored by PCBway.com, which generously manufactured the PCB for it as sponsorship. The PCB was perfectly done and allowed for testings and rewiring problematic parts to reveal hidden problems in the first iteration design.

MHF-002 have more than 75 improvements over MHF-001 and should be even more testable and more convenient for hand soldering, while using more modern parts.

Global Goals
============







MHF was created as an implementation of a graphical and I/O card design for an 8-bit computer based on the HD6309 processor (hereafter referred to as CPU). The actual design is built around the ATmega2560 microcontroller (used, for example, in the Arduino Mega), which I will refer to as the MCU. The MCU is supplemented with RAM and several simple circuits for input and output. Another RAM chip is used for data transfer in both directions, shared alternately between the CPU and MCU. The advantage of this design is high throughput (at the cost of latency) and easy access from both systems.

During the debugging of the preliminary prototypes, it proved to be a significant advantage to have interactive access to the hardware, which led to the implementation of FORTH. It also became clear that, in addition to VGA/RCA, the PS/2 keyboard and SD card could be read concurrently. With enough memory, the graphics card can even function as a standalone single-board computer (SBC), which is a more convenient mode for debugging.

Since access to the shared RAM requires cooperation with the GLUE, the board also includes jumpers for easy configuration of the SBC mode, where some signals intended for the SysBus are redirected directly to the shared memory.

Detailed configuration and usage options will be described on a separate page, but for a quick start, it is sufficient to solder either the left or right side of the A/B jumpers for the graphics card mode. For SBC mode, it is enough to solder the SBC jumpers. These options are mutually exclusive (either graphics card mode or SBC).

Next, there are previews of MHF-002 and links to the schematic and PCB (only the top and bottom layers, as both middle layers are reserved for power), which were generated from KiCad files.

























`Schema <schema.pdf>`__

`PCB <pcb.pdf>`__

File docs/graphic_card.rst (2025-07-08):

.. vim: set ft=rst showbreak=»\  noexpandtab fileencoding=utf-8 nomodified   wrap textwidth=0 foldmethod=marker foldmarker={{{,}}} foldcolumn=4 ruler showcmd lcs=tab\:|- list tabstop=8 noexpandtab nosmarttab softtabstop=0 shiftwidth=0 linebreak  

Základní myšlenka
==================

* HW:
	* retropočítač/CPU - HD6309 4MHz
	* Arduino - atmega2560
	* gates - 74HC245 Octal bus tranceiver 3 state - 2 pro adresu, 1 pro data
	* GLUE - ATF1504 - 64 I/O pinů
		* GLUE obecně je v tom počítači to, co převádí jedny signály na druhé (adresu na OE příslušných obvodů a podobně) - vlastně všechno, co není CPU, RAM nebo Arduino, ale zde je to CPLD, které dělá všechno a gates, které zajišťují oddělení sběrnic. Možná časem přibudou podpůrné obvody, ale spíš ne.
	* paměť - CY7C109D-128kx8-SRAM 
		* jedna pro retropočítač se základním mapováním 0..64kB
			* oblast 8000-BFFF je překrývána podle potřeby
			* oblast C000-C??? je použita pro I/O účely
			* zbytek (C???-FFFF) je považován za ROM (a je otázka, zda do něj půjde normálně zapisovat)
		* druhá pro sdílení s CPU a s Arduinem
			* vždy do ní může v danou chvíli přistupovat maximálně jede z nich
			* gates jsou použity pro oddělení této paměti od sběrnice CPU
			* Arduino si nastaví porty do HiZ podle potřeby

* Retropočítač/CPU vidí paměť jako 32kB RAM, 16kB cosi jako EMS s benefity, několik bytů pro I/O mapování a zbytek do 64kB ROM.
* Arduino vidí 128kB externě dostupné RAM a nějaké signály
* Glue logic dělá registry a (některé) příslušné signály

* Arduino dokáže s tou externí RAM komunikovat asi tak na 1-2 MB/s ( nastavit adresu 2, nastavit OE+R/W 1, vlastní přenost 1B 1, shodit OE 1, zvýšit adresu 2, uložit ten byte 1, zvýšit interní adresu 2 ~ 9 instrukcí?)
* Arduino nedokáže dost rychle komunikovat s CPU přímo
* CPU komunikuje s tou RAM nativní rychlostí 4MHz asi tak až 1.3 MB/s ( TFM 6+3n )

Signály
=======

* A_* komunikace s Arduino (A/B)
	* `A_HALT` pulldown, **LOW**, Arduino ho nastaví nahoru když už nepotřebuje haltovat CPU
	* XXX `A_BUS` nastaví Arduino, když chce přístup na systémový bus - což je vždy při `A_HALT` ... taky se bez toho obejdu
	* `A_READ` používá Arduino pro RAM a Shared RAM (a `A_HALT` určuje, pro kterou to GLUE přeloží)
	* XXX `A_WRITE` používá Arduino pro RAM a Shared RAM - jde natvrdo zakódovat, že `A_WRITE` je negace `A_READ` a díky dobrému časování vše bude fungovat (a odpory to pokryjou při chybě - odpory nejdou vzhledem k RAM výstupu, ale nejspou potřeba, maximálně tam bude chvilku zápis bez hodnot, nasledovany nastavenim hodnot = není problém)
	* XXX `A_SHARE_WANTED` nastaví GLUE  **HIGH** = CPU chce Shared RAM - můžu zrušit, nikdo si nebude nechávat RAM do foroty dlouho a `A_SHARE_DIRTY` mi řekne, zda data ještě platí/jsou nová
	* `A_SHARE_REQUEST` Arduino nastaví na **HIGH** když chce Shared RAM
	* `A_SHARE_GRANTED` GLUE nastaví na **HIGH**, když Shared RAM patří Arduinu ( XXX `A_SHARE_BUSY` nastaví GLUE  **HIGH** = Shared RAM patří CPU je jeho negace)
		* Arduino nastaví `A_SHARE_REQUEST`, GLUE nastaví `A_SHARE_GRANTED`, Arduino může psát pokud jsou oba nahoře. Navíc je zajištěno, že `A_SHARE_GRANTED` nespadne, dokud `A_SHARE_REQUEST` trvá
		* když Arduino dopíše/dočte, shodí `A_SHARE_REQUEST` a nestará se o `A_SHARE_GRANTED`
	* `A_SHARE_DIRTY` nastaví GLUE  **HIGH** = Shared RAM byla naposled modifikována CPU 
* C_* komunikace s CPU
	* `C_HALT` pullup
	* `C_READ` CPU chce číst nebo psát
	* `C_CLOCK` hodiny
	*  `C_A[13..15]` - rámec 8kB, který nepouštím přímo, ale přepočítávám na posuny v XMS (systémová RAM)
* R_* signály pro systémovou RAM
	* `R_READ` read signal - OE, active low
	* `R_WRITE` write signal
	* `R_ENABLE` enable signal
	* `R_D[0..7]` data = `C_D[0..7]`
	* `R_A[0..16]` address = `C_A[0..11]` plus GLUE
* G_* GLUE logic (A/B)
	* `G_A_DIR` address gate dir 
	* `G_D_DIR` a `G_D_OE` data gate dir 
	* `G_ENABLE`, nepotřebuju rozlišovat
* S_* signály pro Shared RAM (A/B) (EMS)
	* `S_READ` read signal - OE, active low
	* `S_WRITE` write signal
	* `S_ENABLE` enable signal
	* `S_A[16]` address (+R_A[0..15])

Boot sekvence
==============

* (Reset má kondenzátor a "vyšší práh citlivosti", spíná jako poslední)
* naběhne napájecí napětí
	* `A_HALT` je pulldownem držený dole
		* GLUE logic tudíž podrží dole `C_HALT`
		* (CPU je v haltu a začne nabíhat jeho reset, všechny signály v HiZ)
		* (Arduino staruje a má všechny piny HiZ)
		* (GLUE po resetu odpojilo brány k Arduinu)
	* `A_BUS`  je pulldownem držený dole 
		* GLUE pro `A_HALT`  **LOW** a `A_BUS`  **LOW** drží brány rozpojené
			* GLUE kopíruje `C_READ` do  `R_READ`
	* Clock se rozbíhá na nějakých 4 MHz
* po delší době nastartuje Arduino (věci v setup a tak)
	* `A_HALT` nastaví na **LOW** a aktivně ho tam drží (žádná změna)
	* Arduino načte z SD karty, nebo FLASH, nebo nějak obsah ROM
* Arduino začne plnit ROM
	* Arduino nastaví `A_BUS`  na **HIGH**
		* GLUE pro  `A_HALT`  **LOW** a `A_BUS`  **HIGH**
			* GLUE nastaví brány pro adresy na Arduino->SYS a otevře je
				* `G_A_DIR` a `G_ENABLE`
			* GLUE kopíruje `A_READ` do směru brány `G_D_DIR` pro data a otevře ji
				* `G_D_DIR` a `G_ENABLE`
			* GLUE kopíruje `A_READ` do  `R_READ` (AND `C_CLOCK` ?)
			* GLUE kopíruje `A_WRITE` do  `R_WRITE` (AND `C_CLOCK` ?)
			* strike - GLUE udržuje  `R_ENABLE` (podle hodin) - /strike `R_ENABLE` je zapojený pořád
			* GLUE nepřekládá adresy, samo je má na HiZ (a data taky) (zápisy do registrů a tak jdou do podložené RAM)
				* `R_D[0..7]` `R_A[0..16]`
	* LOOP:
		* Arduino nastaví adresu (a data, pokud je `A_READ` = true, dochází ke konfliktu = odpory mezi gate a arduino, budeme držet `A_READ` = false)
		* Arduino nastaví `A_READ` = false (zápis do sys), `A_WRITE` = true 
			* GLUE nastaví `R_READ` a `R_WRITE` a otevře brány pro data -> SYS (může dojít ke konfliktu = odpory mezi gate a SYS)
		* strike - Arduino počká dva cykly SYS (takže aspoň jeden kompletní projde s write) - /strike 
		* Arduino udělá samo cyklus, protože RAM není závislá na hodinách
		* Arduino nastaví `R_WRITE` = false (čtení ze SYS) (není konflikt, čte se co se zapisovalo)
		* Arduino vymyslí další data a jede znovu (klidně v nulovém čase)
	* ROM je zapsána, Arduino odpojí svoje piny pro data a adresy a nastaví `A_BUS` =**LOW**
		* GLUE pro `A_HALT`  **LOW** a `A_BUS`  **LOW** drží brány rozpojené a kopíruje `C_READ` do  `R_READ`
* Arduino předá řízení CPU
	* Arduino nastaví `A_HALT`  = **HIGH**
		* GLUE odpojí/ignoruje `A_BUS` 
		* GLUE nastaví `C_HALT` na HiZ (a vnější pullup ho vytáhne nahoru a CPU se rozběhne)
		* GLUE kopíruje `C_READ` do  `R_READ` a  `C_WRITE` do  `R_WRITE` 

.. {{{ Registry

Registry
=========

* GLUE poskytuje tyto registry:
	* Source0/1 R/W
		* Source0/1 W: **zapsání** hodnoty znamená vydání požadavku na namapování daného zdroje
			* Source R je okamžitě nastaven na tuto hodnotu (možná sanitizovanou)
			* Status R je nastaven jako busy
		* Source0/1 R: vrací právě namapovaný zdroj (ať už je, či není dostupný)
	* Status0/1 R
		* 0 OK - znamená vše v pořádku
		* 1 busy - zdroj není dosud k dispozici
		* 2 OK - ale protistrana má zájem
		* 4 - protistrana zapsala data (teda, vlastnila zdroj)
	* Pokud Status AND 0001 není OK nelze pracovat ani se starou ani s novou pamětí (lépe řečeno, není definované, co se stane)
		* Pokud se změní source, CPU nečte status, ale zdroj se připojí, je možné ho používat (= čtení Status není povinné, ale připojování může trvat libovolně dlouho, i celé sekundy třeba)
	* Je možno požadovat namapování zdroje (ať stejného či jiného) ještě před dokončením mapování předchozího.
	* Source0 / Source1 jsou pro dolních / horních 8kB mapovatelné oblasti, nezávislé
	* zdroje: rozdělení podle horních a dolních bitů
		* 00xx je systémová paměť
		* 01xx je Arduino 1 paměť
		* 10xx je Arduino 2 paměť
		* zbytek není zatím definován
		* dolní půlka bytu říká, který 8kB blok je namapován (0..15)
		* xx..xxxx bity 4..5 zatím nevyužity, zapisujte 0
	* CPU "vlastní" paměť, pokud ji má namapovanou aspoň v jednom slotu
	* CPU se "vzdá" paměti, jakmile ji namapovanou nemá
	* změna namapování paměti v rámci Arduina není zřeknutí se
	* systémovou paměť CPU vlastní pořád
	* "divná namapování" jako připojení oblasti RAM/ROM, nebo namapování stejného kusu paměti do obou slotů se chovají tak, jak to GLUE logice vyjde. Čili to nejspíš funguje správně a je jedno, kam se zapisuje a odkud čte, ROM není chráněná

`A_` něco, SYS_něco a Arduino_něco jsou signály mezi CPLD a příslušnými častmi počítače, kterým odpovídají stejně nazvané spoje. Jde o žádosti o něco, připojení někam.
Grafické nákresy dodělám časem.
Source-zdroj je to, co se namapuje do 8kB okna - blok paměti z některého z RAM chipů
v registrech je to také pojmenování registru v CPLD
Při novém zápisu CPLD přeruší (a zapomene) předchozí sekvenci a pokusí se namapovat požadovaný zdroj. 
Synchronizaci si musí zařídit CPU, opakovaným čtením Statusu (přičemž může mezitím dělat i cokoli jiného). Mapování musí čekat, dokud požadovanou RAM neuvolní Arduino, což v případě zápisu na SD kartu, nebo jiných operacích může trvat velmi dlouho. Situace je obdobná jako u sériové komunikace, kdy protistrana nevysílá a čekání na další znak může trvat, dokud se obsluha nevrátí z oběda.

.. }}}

.. {{{ Vložka s umělákem

Vložka s umělákem
===================

Potrebuju vymyslet (a popsat) rozhrani mezi 8bitovym pocitacem (CPU) a dvema Arduiny (A a B), ktere bude delat CPLD nazvane GLUE (jako lepidlo, ktere spojuje jednotlive casti).
Ze strany CPU pujde o dve dvojice registru - (status_L, addr_L) a (status_H, addr_H) 
A dvojici registru pro chipy - status_A a status_B
Ze strany Arduin půjde o signály privadene na jejich I/O piny

Z pohledu CPU jsou v jeho pameti dve okna o velikosti 8kB (dolni (Low) na adrese 0x8000 a horni(High) na adrese 0xA000) do kterych je neco namapovane

Jsou tri chipy RAM, kazdy ma 128kB (RAM_A sdilena s Arduinem A, RAM_B sdilena s Arduinem B, RAM_C pouze pro CPU)

Kdyz chce CPU pouzit v nejakem okne nejakou pamet, zapise do prislusneho registru (napr. addr_L) pozadovanou adresu jako byte ve tvaru aa00bbbb, kde bity aa udavaji o ktery chip jde (00 RAM_C, 01 RAM_A, 10 RAM_B) a bity bbbb udavaji o kterych 8kB v ramci chipu pujde (4 horni bity adresy). 

Nasledne CPU cte v cyklu odpovidajici stavovy registr (status_L), dokud tento neukaze, ze je mozno dotycne okno pouzivat. Stavovy registr ma nasledujici bity 000wm0b
bit B je busy - 1 znamena pamet neni jeste pridelena, 0 pamet pridelena je
M znamena modified, 1 znamena ze od minuleho prideleni byla pamet modifikovana Arduinem
W je Wanted - 1 znamena, ze Arduino by do te pameti chtelo psat (treba mezitim dosla nejaka nova data zvenku)

CPU take kdykoli muze cist stavovy registr chipu (status_A/status_B), s nasledujicimi bity 00dwmac
bit A je vlastneno Arduinem - 1 znamena ano
bit C je vlastneno CPU - 1 znamena ano
M znamena modified, 1 znamena ze od minuleho prideleni byla pamet modifikovana Arduinem
W je Wanted - 1 znamena, ze Arduino by do te pameti chtelo psat (treba mezitim dosla nejaka nova data zvenku)
D je dirty - CPU tam zapsalo, ale Arduino to jeste necetlo

Pokud CPU namapuje nejakou RAM (jakozto chip), pak mu patri az do chvile, kdy bude v obou oknech namapovano neco jineho (cimz se CPU toho chipu zase vzda)

Obdobne to bude fungovat pro Arduina, Arduino si nemuze pripojit RAM, pokud ji vlastni CPU. Pokud si Arduino pripoji nejakou RAM, tak ji vlastni (a CPU si ji nemuze namapovat), dokud se ji nevzda. Kdyz si Arduino pripoji RAM, tak se predpoklada, ze ji precetlo a zapsalo. Arduino potrebuje vedet, jestli CPU do te pameti zapsalo a jestli ji CPU chce.

A potrebuju pro kazde Arduino vymyslet signaly, aby to mohlo takhle fungovat (potrebuje vedet, jestli je jeho RAM volna, jestli ji CPU chce, jestli ji CPU zapsalo)

A cele to nejak rozumne popsat.

🔸 1. Adresace RAM z pohledu CPU

CPU má dvě 8kB okna:
Název okna	Adresa v paměti CPU	Řídicí registry
Low	0x8000–0x9FFF	addr_L, status_L
High	0xA000–0xBFFF	addr_H, status_H

CPU zapisuje do addr_L / addr_H 1 byte ve tvaru:

aa00bbbb
││   └── bbbb = 4 horní bity adresy v rámci RAM (který 8kB blok z 128kB)
└┴────── aa = výběr RAM čipu:
           00 = RAM_C (pouze pro CPU)
           01 = RAM_A (sdílí s Arduino A)
           10 = RAM_B (sdílí s Arduino B)

GLUE na základě tohoto bajtu:

    Přiřadí do okna odpovídající RAM blok

    Vyhodnotí přístupové právo (jestli CPU smí, nebo ne)

    Připraví status v status_L / status_H

Struktura stavových registrů status_L / status_H:

Bit:    7 6 5 4 3 2 1 0
        0 0 0 W M 0 0 B
                    │ │
                    │ └── B (Busy): 1 = RAM není připravená pro CPU
                    └──── M (Modified): 1 = Arduino ji změnilo od posledního použití
             W (Wanted): 1 = Arduino ji chce pro zápis

🔸 2. Stavové registry Arduin: status_A, status_B

Slouží k tomu, aby CPU mohl sledovat stav každého čipu RAM sdíleného s Arduiny.

Bit:    7 6 5 4 3 2 1 0
        0 0 D W M A 0 C
          │ │ │ │ │   └ CPU own (1 = CPU má RAM)
          │ │ │ │ └── Arduino own (1 = Arduino má RAM)
          │ │ │ └──── M = modified Arduino (od posledního CPU přístupu)
          │ │ └────── W = Arduino chce RAM
          │ └──────── D = Dirty (CPU zapsalo, Arduino ještě nečetlo)

🔸 3. Signály mezi Arduiny a GLUE

Každé Arduino potřebuje rozhraní k GLUE, které mu umožní:

    Požádat o RAM

    Být informováno, jestli je RAM volná

    Být informováno, že CPU zapsalo (Dirty)

    Informovat GLUE, že RAM modifikovalo

    Informovat, že chce RAM

📟 Navržené signály pro každé Arduino (A i B):
Název signálu	Směr	Význam
REQ_RAM	Arduino → GLUE	Požadavek na přístup k RAM (Arduino si ji chce připojit)
RAM_GRANTED	GLUE → Arduino	Arduino dostalo přístup k RAM
CPU_WANTS_RAM	GLUE → Arduino	CPU by rádo mělo RAM (bit W)
CPU_DIRTY	GLUE → Arduino	CPU zapsalo (bit D), Arduino by mělo číst
ARDUINO_MODIFIED	Arduino → GLUE	Arduino zapsalo (bit M)
ARDUINO_RELEASE	Arduino → GLUE	Arduino RAM opouští (vzdává se jí)

Volitelně:

    RAM_SELECT[3:0]: 4 bity určující, který 8kB blok Arduino žádá

    CHIP_SELECT[1:0]: 2 bity pro výběr RAM_A / RAM_B

🔸 4. Pravidla vlastnictví RAM

CPU může používat RAM blok, pokud:

    Není vlastněn Arduinem (bit A = 0)

    GLUE ho připojila a nastavila status_L/H s B = 0

Arduino může používat RAM blok, pokud:

    CPU ho nemá připojený (C = 0)

    Požádá pomocí REQ_RAM, GLUE vrátí RAM_GRANTED

Vlastnictví CPU zaniká, pokud:

    Není RAM připojená ani v Low ani v High okně

Vlastnictví Arduino zaniká, pokud:

    Pošle ARDUINO_RELEASE

🔸 5. Diagram komunikace

Zjednodušeně:

      CPU                           GLUE                        Arduino A / B
       │                              │                                │
       │-- addr_L = 01_00_1010 ------>│                                │
       │                              │                                │
       │<-- status_L = ...0... ------ │ (přiděleno)                   │
       │                              │                                │
       │==> Přístup k RAM_A: blok 0xA000–0xBFFF                        │

      Arduino požaduje RAM_A:
       │                              │<----- REQ_RAM ----------------│
       │                              │----- CPU_WANTS_RAM ------>    │
       │                              │----- CPU_DIRTY --------->     │
       │                              │<---- RAM_GRANTED -----------  │
       │                              │----- A=1, C=0 ----------------│

      Arduino hotovo s RAM_A:
       │                              │<--- ARDUINO_RELEASE ----------│
       │                              │----- A=0 -------------------->│

🔸 Shrnutí komponent rozhraní
🧠 CPU:

    Řídicí registry: addr_L, status_L, addr_H, status_H, status_A, status_B

    Paměťová mapování: 8kB okna na 0x8000 a 0xA000

    Sleduje statusy, reaguje na signály M/W/D

🧱 GLUE (CPLD):

    Koordinuje přidělení RAM

    Sleduje přístupová práva a stavy (M/W/D/A/C)

    Generuje signály pro Arduina

🔧 Arduino A/B:

    I/O signály:

        REQ_RAM, ARDUINO_MODIFIED, ARDUINO_RELEASE

        vstupní: RAM_GRANTED, CPU_WANTS_RAM, CPU_DIRTY

    Sleduje status čipu přes signály, případně může číst stav přes vlastní I/O

.. }}}

Normální stav
=============

* `A_HALT` = **HIGH**
* CPU komunikuje s GLUE přez registry, uvidíme jak. Podstatné stavy:
	* CPU má namapovanou systémovou RAM, GLUE převádí `C_READ` a `C_CLOCK` na `R_READ` `R_WRITE` `R_ENABLE` a `R_A[12..16]`
	* CPU chce Shared RAM (a ta je zrovna obsazená)
		* `A_SHARE_WANTED` nastaví GLUE  **HIGH** = CPU chce Shared RAM
	* CPU chce Shared RAM (a ta je zrovna volná)
		* `A_SHARE_BUSY` nastaví GLUE  **HIGH**
		* `A_SHARE_WANTED` nastaví GLUE  **LOW** 
		* `G_A_DIR` CPU -> Arduino
		* `G_D_DIR` podle `C_READ`
		* `G_ENABLE` true
		* `S_READ` read signal - OE, active low
		* `S_WRITE` write signal
		* `S_ENABLE` enable signal
		* `S_A[12..16]` address 
	* Arduino chce Shared RAM
		* `A_SHARE_REQUEST` Arduino nastavi na **HIGH** když chce Shared RAM
	* CPU se vzda Shared RAM
		* `A_SHARE_BUSY` nastaví GLUE  **LOW**
		* `A_SHARE_DIRTY` nastaví GLUE  **HIGH** = Shared RAM byla naposled modifikována CPU 
		* a odpojí co se zapojilo (gates ...)
	* Arduino dostane Shared RAM
		* `A_SHARE_GRANTED` GLUE nastaví na **HIGH**, když Shared RAM patří Arduinu
		* `S_ENABLE` = true
		* `S_READ` `S_WRITE` podle `A_READ` `A_WRITE`
	* Arduino vrací Shared RAM
		* `A_SHARE_REQUEST` Arduino nastavi na **LOW** když vrací Shared RAM
		* GLUE `A_SHARE_GRANTED` low
		* GLUE uvolní zdroje

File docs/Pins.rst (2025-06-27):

.. vim: set ft=rst showbreak=»\  noexpandtab fileencoding=utf-8 nomodified   wrap textwidth=0 foldmethod=marker foldmarker={{{,}}} foldcolumn=4 ruler showcmd lcs=tab\:|- list tabstop=8 noexpandtab nosmarttab softtabstop=0 shiftwidth=0 linebreak  

Pin assingments:
==================

By group:
==========

External Memory
---------------

External memory is hardcoded in ATmega2560 this way:

* PA[0..7] is AD0-7 and A0-7 for external memory
* PC[0..7] is A8-15 for external memory
* PG0 is WR (write active low)
* PG1 is RD (read active low)
* PG2 is ALE (address latch enabled)

This enables aditional 54kB of RAM, but each access to this RAM takes one cycle longer than the same access for normal RAM.

Also 6kB from 64kB is hidden by the normal RAM and so unused. While it could be also utilised by more advanced mapping, it would need more ICs and more complicated memory mapping. I decided to NOOT support this.

The RAM chip contains 128kB of RAM, so we can select which half we will use - I did choose PG3 as it is the next pin to WR/RD/ALE (and the PG port is already broken). Maybe add pulldown here too, so if the pin is not output, then the default half is used. (Floating values would mean, that reads and writes may go to different parts and whole memory would be unusable.)

* PG3 is A16 (memory bank select)

Input / output
--------------

I/O (Serial/UART, I2C, SPI, ISCP, ...) - I would like to have the basic interfaces available even in the fully populated variant - so let's preliminarily allocate them for now:

* PB[0..3] ISCP, SPI
* PD[0..1] I2C/TWI
* PE[0..1] RX/TX USART0
* PE[2..3] CTS/RTS for flow control (so copy-paste of text is reliable)

VGA
------

VGA system uses Timer 1 for Hsync signal and interrupt and for jitter, Timer 3 for Vsync signal and interrupt, data output needs full port. For colors is also used full port to enable foreground/background colors (selectable possibly for each horizontal line).

Ports F and J looks like free ports, let's use them for data and colors. PB7 looks like free pin in already used port, let's use it for Latch.

* PE[7] 16MHz ( **fixed** in HW)
* PB[6] Timer 1 B for Hsync (SW+HW)
* PE[4] Timer 3 B for Vsync (SW+HW)
* PB[7] Latch
* PF[0..7] for data out
* PJ[0..7] for colors out
* Timer 1 jitter (prescale x1, SW only part)

RCA
------

RCA needs timer with one pin for both Hsync and Vsync, USART for data out and one more pin for suppressing data, when there is no output at all. 

While there is not enough computing power to run VGA and RCA at the same time, it may be possible to have at least synchronisation pulses running, so VGA would just show black screen instead of losing sync (and then take 3 seconds to sync again). So let's use different Timer and pins.

* PD[2..3] USART1 RX/TX (even when RX is not needed, it is HW used while USART uses TX)
* PH[4] Timer 4 B for both Hsync and Vsync 

PS/2
------
* ?? PB[4..5] PS/2 pins
* ?? PE[3] PS/2 Envelope

* free so far:
	* PB[4..7] TC1
		* ? PB [4..5,7] --
		* ?? ---
	* PD[2..7] USART1
		* ? PD [4..7] --
	* PE[2..6] TC3
		* ?? PE[2-3,5-6]
	* PF full (JTAG, ADC)
		* ?? ---
	* PG[3..5] TC0
	* PH full USART2 TC2,4
	* PJ full USART3 PCINT
		* ?? --
	* PK full ADC, PCINT
	* PL full TC4,5
By port:
=========

* PA[0..7] is AD0-7 and A0-7 for external memory
* PB[0..3] ISCP, SPI
* PC[0..7] is A8-15 for external memory
* PD[0..1] I2C/TWI
* PE[0..1] RX/TX USART0
* PE[2..3] CTS/RTS for flow control (so copy-paste of text is reliable)

* PG0 is WR (write active low)
* PG1 is RD (read active low)
* PG2 is ALE (address latch enabled)
* PG3 is A16 (memory bank select)

		* I/O (Serial/UART, I2C, SPI, ISCP, ...) - I would like to have the basic interfaces available even in the fully populated variant - so let's preliminarily allocate them for now:
			* PB[0..3] ISCP, SPI
			* PE[0..1] RX/TX USART0
			* PD[0..1] I2C/TWI
		* VGA
			* (PE5)PE[7] 16MHz ( **fixed** in HW)
			* ? PB[6] Timer 1 B for Hsync
			* ?? PE[4] Timer 3 B for Vsync
			* ?? PF[0..7] for data out
			* ?? PJ[0..7] for colors out
			* ?? PB[7] Latch
			* ?? PB[4..5] PS/2 pins
			* ?? PE[3] PS/2 Envelope
			* ?? Timer 4 jitter
		* RCA
			* ? PD[2..3] USART1 RX/TX
		* free so far:
			* PB[4..7] TC1
				* ? PB [4..5,7] --
				* ?? ---
			* PD[2..7] USART1
				* ? PD [4..7] --
			* PE[2..6] TC3
				* ?? PE[2-3,5-6]
			* PF full (JTAG, ADC)
				* ?? ---
			* PG[3..5] TC0
			* PH full USART2 TC2,4
			* PJ full USART3 PCINT
				* ?? --
			* PK full ADC, PCINT
			* PL full TC4,5

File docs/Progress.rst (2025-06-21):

.. vim: set ft=rst showbreak=»\  noexpandtab fileencoding=utf-8 nomodified   wrap textwidth=0 foldmethod=marker foldmarker={{{,}}} foldcolumn=4 ruler showcmd lcs=tab\:|- list tabstop=8 noexpandtab nosmarttab softtabstop=0 shiftwidth=0 linebreak  

See also `Journal <Journal.rst>`__ and `index <README.rst>`__ ( `top <../README.rst>`__ )

Progress
========

Done:

* get Arduino Mega PRO with ATmega2560 for testing
	* ordered some from AliExpress
	* it will also serve as component source for the PCB
* get 16MHz output
	* there is no connection for this on Arduino boards
	* I connected it to some other pin for tests (NEVER use PE5, PE6 in testing)!!!
* map pins in NanoHomeComputer
	* I need to know (and have written to see it), what is used and for what functions
	* I also need to write all used timers and their connections, as conversion need reassing both pins and timers
* map pins on ATmega2560
	* I need to write down what I already used, what are HW limits and to be able to plan optimal use of the rest
* assign VGA/RCA/PS2 pins to ATmega2560
* test VGA output

Next steps:

* test RCA output
* test PS/2 direct input
* test PS/2 8bit input
* assign rest pins on ATmega2560
* draw schema
* draw PCB
* order PCB
* get PCB manufactured
* solder component
* test each goal
* physical tests
* programming
* enjoy :)

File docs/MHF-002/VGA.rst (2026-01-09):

.. vim: ft=rst showbreak=--»\  noexpandtab fileencoding=utf-8 nomodified   wrap textwidth=0 foldmethod=marker foldmarker={{{,}}} foldcolumn=4 ruler showcmd lcs=tab\:|- list tabstop=8 noexpandtab nosmarttab softtabstop=0 shiftwidth=0 linebreak  

:date: 2025.12.09 05:00:06
:_modified: 1970.01.01 00:00:00
:tags: HW,MHF-002
:authors: Gilhad
:summary: VGA
:title: VGA
:nice_title: |logo| %title% |logo|

%HEADER%

VGA
--------------------------------------------------------------------------------

VGA need Vertical Sync (at start of each screen), Horizontal Sync (at start of each line) and Signal (inside the line, it is the pixels).

Vertical Sync is generated by timer on pin PE4 (every 16.64 mS ~ 60 Hz)

Horizontal Sync is generated by timer on pin PB6 (every 32 uS)

VGA signal is generated in interrupt on timer overflow (every 32 uS = each 512  clock ticks)

It needs pin PE7, where 16MHz (system clock) can be configured. As Arduino Mega does not have this pin connected, this was the main reason for making this PCB.

Here are some osciloscope snaps, the magenta line is VSync, yellow line is HSync and green is Signal (sorry for wrong naming in picture)



(4 screens at 60Hz)



(1 line with pixels, 32uS)

The main idea came from Squeezing Water from Stone 3: Arduino Nano + 1(!) Logic IC = Computer with VGA and PS/2 from slu4coder - short macro in assembler take character from videoram, take its definition from Flash, puts it as byte to port (PF here) and let 74HC166 to clock it out as 8 pixels. The macro take 8 clock ticks and is repeated 40x to output full line.
Each line is shown 2x so the visible area is 320x400 pixels, but is managed as 320x200 points (25 text lines) for readability and data size (character set takes 256 chars x 8 lines per character = 2kB of Flash.)

The numbers are: 32uS x 16MHz = 512 ticks. 40 characters x 8 ticks = 320 ticks, 512 - 320 = 192 ticks for everything else. When interrupt happens and interrupts are allowed (SEI) the MCU will finish instruction first, then serve the interrupt. This waiting for instruction end may take 1-3 ticks itself, so the interrupt may happen not really regularry and is necesery to adjust for that (macro check in my code). Also it needs to save registers, compute all adresses and offsets and manage possible PS/2 during the line. That may take approx 150 ticks together, leaving like 42 ticks between lines for user code to run in (means 8% speed only).

Then there are the black borders above and below the displayed image (only lines 60 .. 460 are visible), where the user program is mainly executed (which give like 20% of MCU power). It is not much, but a lot of work can be done anyway.

I set not only the Vertical Sync, but also the Horizontal sync to timers, so it does not depend on code exuting, which solved problem where VGA monitor sometimes went blank for few seconds (because some other interrupt or CLI..SEI section moved HSync pulse out of place and monitor get "confused and blank"). Now long uniterruptable section just make small glitch on screen, where pixels are horizontally moved for a frame (1/60 sec).

I also added 74HC157 IC to select foreground/background colors according to 74HC166 output, so now it is possible set foreground/background color for each line separately (I set it for all 16 lines of character the same now). The colors are set on port PH now at the start of visible line.

I also added VGA_ENABLE signal to cut off all pixels output in blank areas, so the ports (PF and PH) can be used for something else (I use PF for PS/2 input, leaving PH for user programs).

I also plan to make hooks on end of each visual line for "mini interrupts" and on end of last visible line (for "run at frame pause" synchronisation of larger blocks, like SD card) to run in interrupt context.

On user level the change of variable frames can be used for synchronisation of larger blocks or for timing events.

Here is schema and placement of the chips on PCB:







Also note, that PB7 (VGA_Latch) is SYSTEM_LED on Arduino, so I placed LED between RCA and PS/2 connector near HALT LED and conected it here. When using VGA the LED will shine with approx 1/8 intensity.











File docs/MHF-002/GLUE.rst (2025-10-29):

GLUE
================================================================================

This is about using MHF(-002) as Graphic Card for 8 bit computer.
Glue are generally those parts, that are not CPU, memory, clock or devices, but orchestrates the Read/Write/Select/Clock signals. Here it is CPLD **ATF1504AS** with 64 macrocells, 64 I/O for use.

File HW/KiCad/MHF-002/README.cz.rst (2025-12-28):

..  vim: ft=rst noexpandtab fileencoding=utf-8 nomodified wrap foldmethod=marker foldmarker={{{,}}} foldcolumn=4 ruler showcmd lcs=tab\:|- list tabstop=8 nosmarttab textwidth=270 linebreak showbreak=--»\ 

.. |Ohm| raw:: html

	Ω

.. |kOhm| raw:: html

	kΩ



MegaHomeFORTH MHF-002
=====================

This is next iteration of `MegaHomeFORTH MHF-001 <https://github.com/githubgilhad/MegaHomeFORTH/tree/MHF-001>`__

MHF-001 was sponsored by PCBway.com, which generously manufactured the PCB for it as sponsorship. The PCB was perfectly done and allowed for testings and rewiring problematic parts to reveal hidden problems in the first iteration design.

MHF-002 have more than 75 improvements over MHF-001 and should be even more testable and more convenient for hand soldering, while using more modern parts.

Global Goals
============







MHF vzniknul jako realizace návrhu grafické a I/O karty pro 8-bitový počítač založený na procesoru HD6309 (dále značený CPU). Vlastní provedení je postaveno na mikrokontroleru ATmega2560 (použitém například v Arduino Mega Pro, dále ho budu označovat MCU) doplněném pamětí RAM a několika jednoduchými obvody pro vstup a výstup. Další chip RAM slouží pro přenášení dat oběma směry, střídavě ho sdílí CPU a MCU. Výhodou je velká propustnost (za cenu latence) a snadný přístup z obou systémů.

V průběhu ladění předběžných verzí se ukázalo jako velká výhoda mít interaktivní přístup k HW, proto byl implementován FORTH. Také se ukázalo, že kromě VGA/RCA se dá souběžně i číst PS/2 klávesnice a manipulovat s SD kartou, takže s dostatečnou pamětí je ta grafická karat schopna fungovat i jako samostatný jednodeskový počítač (SBC - Single Board Computer), což je pro ladění výhodnější režim.

Protože pro přístup ke sdílené RAM je nutná spolupráce GLUE, obsahuje deska i jumpery pro snadné nastavení SBC režimu, kde některé signály určené pro SysBus jsou přesměrovány přímo na sdílenou paměť.

Podrobná konfigurace a možnosti použití boudou rozepsány na samostatné stránce, pro rychlý start stačí v režimu grafické karty propájet buď levou, nebo pravou stranu jumperů A/B, zatímco pro režim SBC stačí propájet jumpery SBC - tyto volby se navzájem vylučují (buď grafická karta, nebo SBC).

Dále následují náhledy na MHF-002 a odkazy na schéma a PCB (jen horní a dolní vrstva, obě prostřední jsou vyhrazeny pro napájení), které byly vygenerovány ze souborů pro KiCad.

























`Schema <schema.pdf>`__

`PCB <pcb.pdf>`__

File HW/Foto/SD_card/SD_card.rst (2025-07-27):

.. vim: set ft=rst showbreak=»\  noexpandtab fileencoding=utf-8 nomodified   wrap textwidth=0 foldmethod=marker foldmarker={{{,}}} foldcolumn=4 ruler showcmd lcs=tab\:|- list tabstop=8 noexpandtab nosmarttab softtabstop=0 shiftwidth=0 linebreak  

SD_card
========

The same as in `Expanduino <http://8bit.gilhad.cz/6809/Expanduino/Expanduino_I.html#sd-karta>`_

I bought some cheap cards from china, with 74HC125 level convertor. basically it is `this type <https://www.hwkitchen.cz/modul-ctecka-micro-sd-sdhc-karet/>`_. 

This cards are known to have problem with `SPI`:

* It does not 3state `MISO` when not selected and so it conflicts with other projects on `SPI`. 
* May also ignore `CS` for `Data In`
* Also it require to have `CS` set to 0 when card is to be insert, and on powerup to set the card to `SPI` compatible mode.
* The solution is to modify this card as in `SOLVED. Nrf24 (Mirf lib) + Micro SD-card works OK together <https://forum.arduino.cc/t/solved-nrf24-mirf-lib-micro-sd-card-works-ok-together/347787/3>`_
* My card cannot be just cut as in the article, because the ground goes there also from the chip - see photos - so I will disconnect it at both places and connect it to `CS` - also it can be done by lifting that leg and soldering wire on it.
* Also it may be done from outside, with some other gates, as in  `Expanduino <http://8bit.gilhad.cz/6809/Expanduino/Expanduino_I.html#sd-karta>`_ Expanduino_I_fix_001_schema.png
* and on next iteration I may just strip the parts and incorporate it into PCB with all `enable` pins (except the for `CS`) connected to `CS` on the PCB









* SD_card.bottom.webp
	

* SD_card.top.connects.webp
	

* SD_card.top.layers.webp
	

* SD_card.top.webp


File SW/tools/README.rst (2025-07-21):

.. vim:   noexpandtab fileencoding=utf-8 nomodified   wrap textwidth=0 foldmethod=marker foldmarker={{{,}}} foldcolumn=4 ruler showcmd lcs=tab\:|- list tabstop=8 noexpandtab nosmarttab softtabstop=0 shiftwidth=0 linebreak showbreak=»\  ft=rst

How to use 24 bits addresses
===============================

* there are `lo8(symbol)`, `hi8(symbol)` and `hlo8(symbol)` for splitting address
* also `pm(symbol)` and `gs(symbol)` which should divide by 2 to get address in FLASH words
* see `<https://sourceware.org/binutils/docs/as/AVR_002dModifiers.html>`__

9.5.2.3 Relocatable Expression Modifiers
----------------------------------------

The assembler supports several modifiers when using relocatable addresses in AVR instruction operands. The general syntax is the following:

modifier(relocatable-expression)

lo8

	This modifier allows you to use bits 0 through 7 of an address expression as an 8 bit relocatable expression.
hi8

	This modifier allows you to use bits 7 through 15 of an address expression as an 8 bit relocatable expression. This is useful with, for example, the AVR ‘ldi’ instruction and ‘lo8’ modifier.

	For example

.. code::

	ldi r26, lo8(sym+10)
	ldi r27, hi8(sym+10)

hh8

	This modifier allows you to use bits 16 through 23 of an address expression as an 8 bit relocatable expression. Also, can be useful for loading 32 bit constants.
hlo8

	Synonym of ‘hh8’.
hhi8

	This modifier allows you to use bits 24 through 31 of an expression as an 8 bit expression. This is useful with, for example, the AVR ‘ldi’ instruction and ‘lo8’, ‘hi8’, ‘hlo8’, ‘hhi8’, modifier.

	For example

.. code::

	ldi r26, lo8(285774925)
	ldi r27, hi8(285774925)
	ldi r28, hlo8(285774925)
	ldi r29, hhi8(285774925)
	; r29,r28,r27,r26 = 285774925

pm_lo8

	This modifier allows you to use bits 0 through 7 of an address expression as an 8 bit relocatable expression. This modifier is useful for addressing data or code from Flash/Program memory by two-byte words. The use of ‘pm_lo8’ is similar to ‘lo8’.
pm_hi8

	This modifier allows you to use bits 8 through 15 of an address expression as an 8 bit relocatable expression. This modifier is useful for addressing data or code from Flash/Program memory by two-byte words.

	For example, when setting the AVR ‘Z’ register with the ‘ldi’ instruction for subsequent use by the ‘ijmp’ instruction:

.. code::

	ldi r30, pm_lo8(sym)
	ldi r31, pm_hi8(sym)
	ijmp

pm_hh8

	This modifier allows you to use bits 15 through 23 of an address expression as an 8 bit relocatable expression. This modifier is useful for addressing data or code from Flash/Program memory by two-byte words.

old
-----

I did not found simple way in **avr-gcc** or **avr-as** 

* `.long symbol` make 32 bit address, not shorter
* `low(symbol)`, `high(symbol)` or similar are not defined
* `symbol & 0xFF`, `symbol >>8` and similar fails, as symbol is not know in compile time and linker does not expressions
* `.byte 0x12, 0x034, 0x056` works, but any change in program/data probably change also the addresses

so I opted for complicated way: 

* scan compiled file `*.elf` for symbols
* generate definitions of all symbols as macros
	* #define address_of_<symbol> .byte 0x12, 0x34, 0x56
* use such macros as addresses in code
* put placeholder values, if macro not found (if possible)
* compile again
* check, if new definitions are the same as old, if no, repeat

.. code::

	$ git diff
	diff --git a/SW/src/Makefile b/SW/src/Makefile
	index 3615eab..a201fe8 100644
	--- a/SW/src/Makefile
	+++ b/SW/src/Makefile
	@@ -19,9 +19,18 @@ ASFLAGS += $(DEFINES)
	 include ../Makefile
	 # include $(ARDMK_DIR)/Arduino.mk
	 
	+.PHONY: 24bit
	 
	 $(TARGET_ELF): $(VERSION_HEADER)
	 
	+$(TARGET_ELF): 24bit
	+
	+
	+24bit:
	+	../tools/elf2def.py $(TARGET_ELF) $(OBJDIR)/24bit.def
	+	if ! cmp -s $(OBJDIR)/24bit.def 24bit.def ; then cp $(OBJDIR)/24bit.def 24bit.def; echo -e "##### REMAKE ####"; fi
	+
	+
	 asm.S: words.inc
	 # words.inc: words.4th
	 #	./forth2inc.py
	diff --git a/SW/src/asm.S b/SW/src/asm.S
	index b8443f7..5736e5d 100644
	--- a/SW/src/asm.S
	+++ b/SW/src/asm.S
	@@ -589,6 +589,27 @@ val_of_f_docol:
	 #	.EQU	top_head,1b-3
		.EQU	top_head,1b-4
	 
	+#include "24bit.def"
	+
	+#define PTR24(symbol) address_of_##symbol
	+#define xPTR24(symbol) .byte 0,0,0 
	+
	+// .macro PTR24 symbol
	+// 	address_of_\symbol
	+// .endm
	+
	+
	+.ascii "@@@>"
	+PTR24(f_docol)
	+PTR24(f_docol)
	+PTR24(f_docol)
	+PTR24(w_lastbuildinword_data)
	+PTR24(w_lastbuildinword_data)
	+PTR24(w_lastbuildinword_data)
	+// xPTR24(qwerrewq)
	+// xPTR24(qwerrewq)
	+// xPTR24(qwerrewq)
	+	.ascii "<@@@"
	 .balign 2
		.ascii "###>"
		.global end

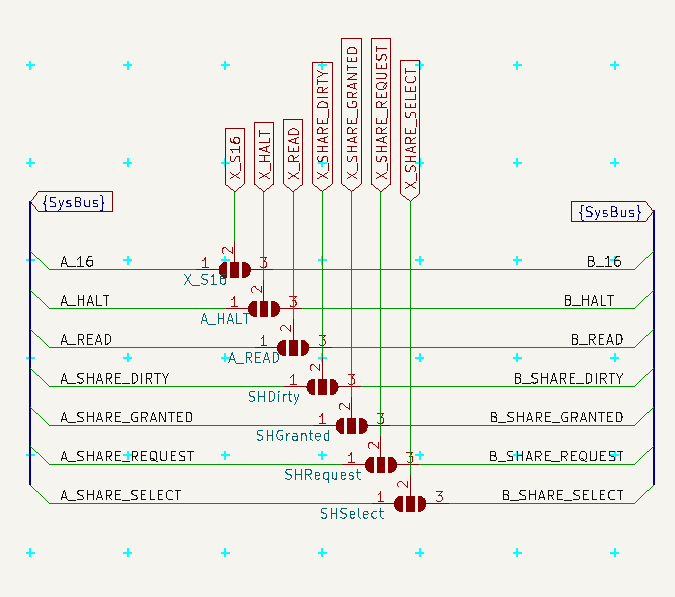
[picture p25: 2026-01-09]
docs/MHF-002/config_GLUE.png

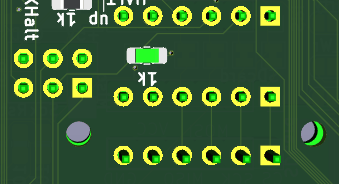
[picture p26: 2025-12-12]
docs/MHF-002/SD_bottom.png

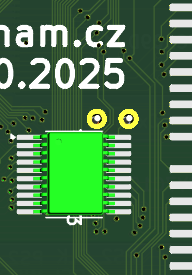
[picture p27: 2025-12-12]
docs/MHF-002/External_RAM_bottom.png

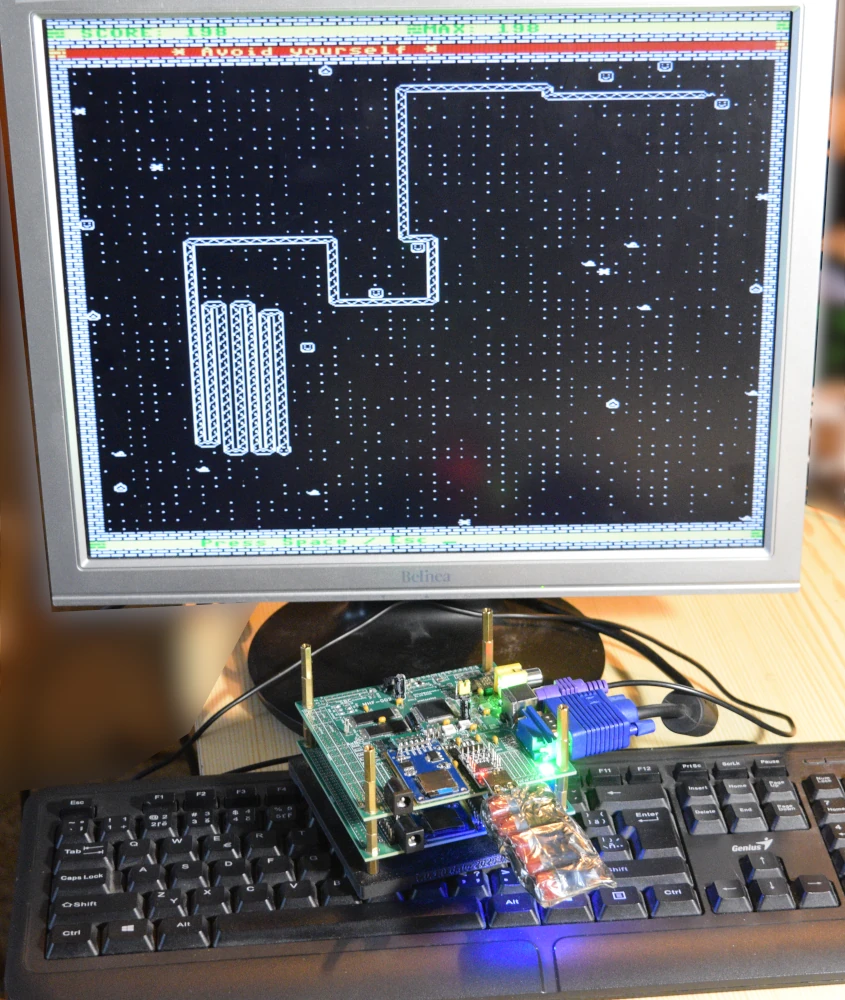
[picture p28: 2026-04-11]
photos/MHF-002.d.s.webp

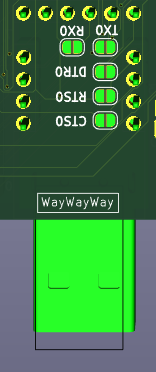
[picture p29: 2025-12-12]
docs/MHF-002/USB-Serial_CP2102_bottom.png

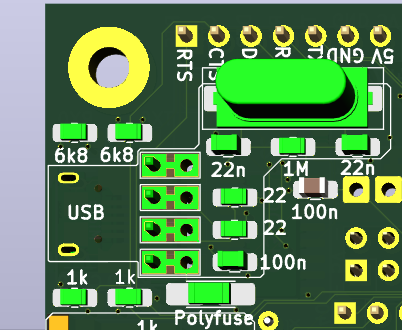
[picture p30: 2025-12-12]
docs/MHF-002/USB-Serial_CH340G_bottom.png

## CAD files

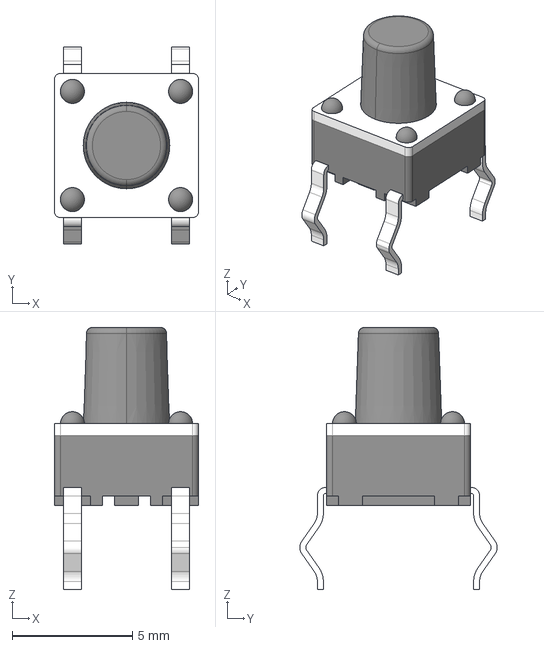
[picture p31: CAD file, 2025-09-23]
HW/KiCad/MHF-002/3dmodels/G_Arduino_switch.step
6.00 x 8.21 x 10.9 mm

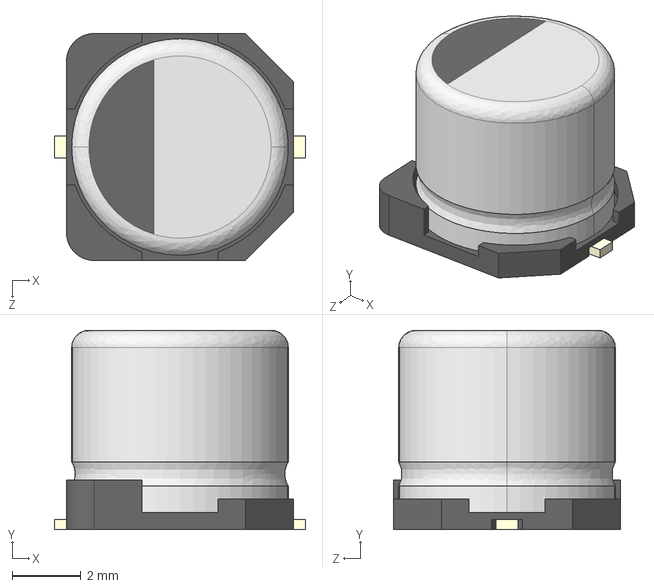
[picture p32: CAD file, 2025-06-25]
HW/KiCad/MHF-002/STEP Files/EEHZA1E470P.step
7.30 x 5.80 x 6.60 mm

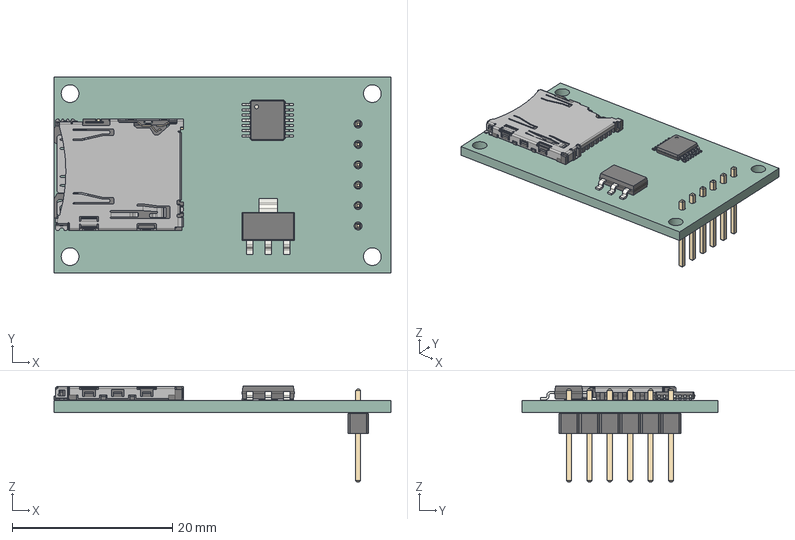
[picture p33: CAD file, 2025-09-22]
HW/KiCad/MHF-002/3dmodels/SDCard.step
42.0 x 24.5 x 11.9 mm
SOT-223
TSSOP-14_4.4x5mm_P0.65mm
microSD_HC_Hirose_DM3AT-SF-PEJM5
PinHeader_1x06_P2.54mm_Vertical
SDCard_PCB

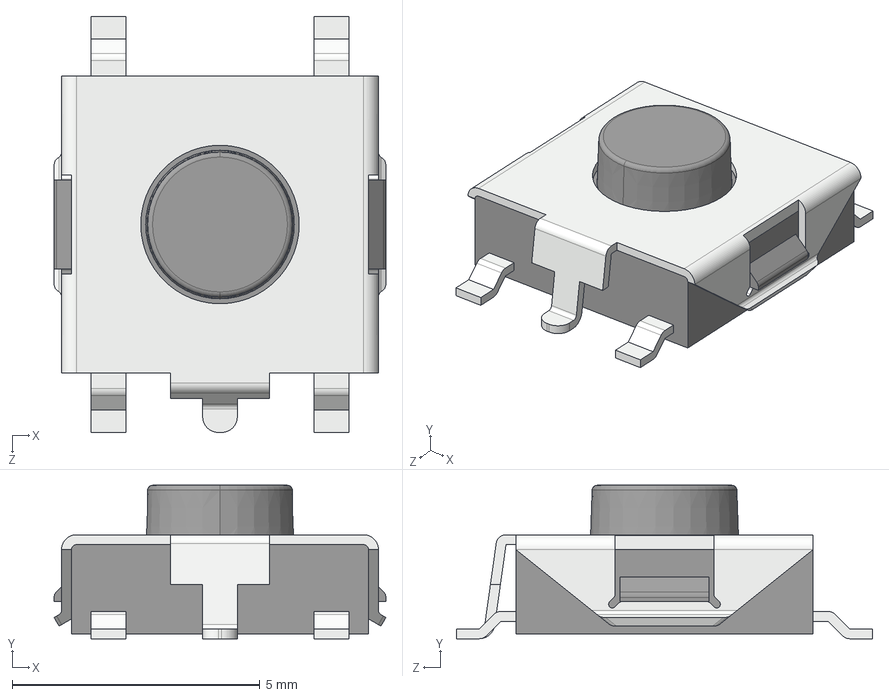
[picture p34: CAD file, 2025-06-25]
HW/KiCad/MHF-002/STEP Files/CUI_DEVICES_TS06-667-30-BK-100-G-SMT-TR.step
6.70 x 3.10 x 8.40 mm

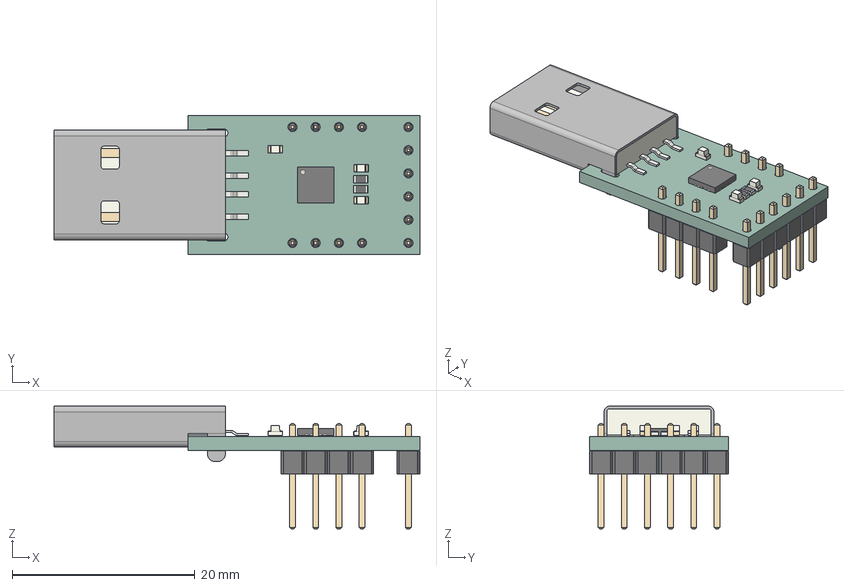
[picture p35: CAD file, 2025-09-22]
HW/KiCad/MHF-002/3dmodels/cp2102.step
40.1 x 15.2 x 13.5 mm
QFN-20-1EP_4x4mm_P0.5mm_EP2.5x2.5mm
R_0603_1608Metric x 2
LED_0603_1608Metric x 3
USB_A_CNCTech_1001-011-01101_Horizontal
PinHeader_1x01_P2.54mm_Vertical x 14
cp2102_PCB

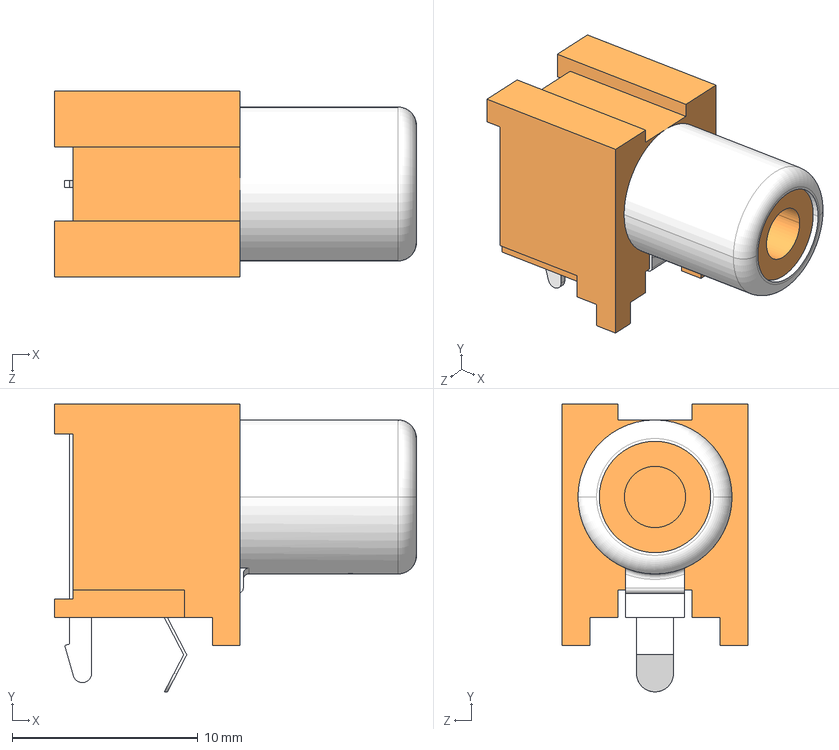
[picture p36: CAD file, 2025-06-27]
HW/KiCad/MHF-002/3dmodels/RCJ-047.step
19.5 x 15.5 x 10.0 mm

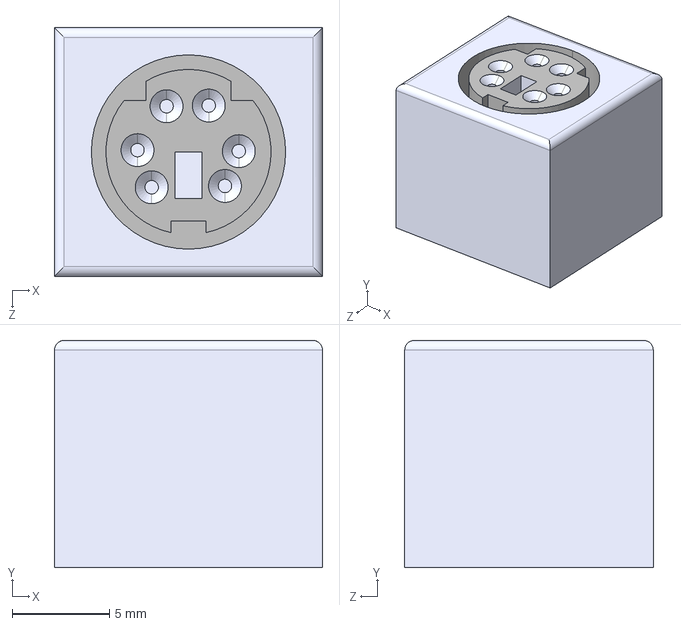
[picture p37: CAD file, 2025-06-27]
HW/KiCad/MHF-002/3dmodels/J_Mini-DIN-6.step
13.8 x 11.7 x 12.8 mm

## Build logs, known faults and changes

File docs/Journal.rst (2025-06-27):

See also `Progress <Progress.rst>`__ and `index <README.rst>`__ ( `top <../README.rst>`__ )

Journal
=======

* 2025.06.21
	* Practical test ATmega2560 with VGA with new timers - it works!
	* Colors are bad, which is expected as I had no access to some pins, so some part of colors was floating+noise. But there is visible, that there are differently colored lines, so it works.
	* I had some problems with timing, so I reworked the timers and collected some knowledge of VGA and also some osciloscope printscreens for next time - see `<VGA/README.rst>`__
	* So having tested the more problematick part with newly assigned pins I can now continue to work on the PCB (and documentation)
	* 
* 2025.06.19-21
	* some learning and reading, 24bit ideas, assigning pins and timers for VGA
* 2025.06.18
	* ATmega2560 sources:
		* Timer0 8bit PWM (pg.115)
		* Timer1,3,4,5 16bit (pg.133)
		* Timer2 8bit PWM+Async mode (pg.169)
		* Timers and pins:
			+--------+--------+--------+---------+
			| Timer  | Cmp    | pin    | Arduino |
			+========+========+========+=========+
			| Timer 0| OC0A   | PB7    | D13     |
			|        +--------+--------+---------+
			|        | OC0B   | PG5    | D4      |
			+--------+--------+--------+---------+
			| Timer 1| OC1A   | PB5    | D11     |
			|        +--------+--------+---------+
			|        | OC1B   | PB6    | D12     |
			|        +--------+--------+---------+
			|        | OC1C   | PB7    | D13     |
			+--------+--------+--------+---------+
			| Timer 2| OC2A   | PB4    | D10     |
			|        +--------+--------+---------+
			|        | OC2B   | PH6    | D9      |
			+--------+--------+--------+---------+
			| Timer 3| OC3A   | PE3    | D5      |
			|        +--------+--------+---------+
			|        | OC3B   | PE4    | D2      |
			|        +--------+--------+---------+
			|        | OC3C   | PE5    | D3      |
			+--------+--------+--------+---------+
			| Timer 4| OC4A   | PH3    | D6      |
			|        +--------+--------+---------+
			|        | OC4B   | PH4    | D7      |
			|        +--------+--------+---------+
			|        | OC4C   | PH5    | D8      |
			+--------+--------+--------+---------+
			| Timer 5| OC5A   | PL3    | D46     |
			|        +--------+--------+---------+
			|        | OC5B   | PL4    | D45     |
			|        +--------+--------+---------+
			|        | OC5C   | PL5    | D44     |
			+--------+--------+--------+---------+

* 2025.06.17
	* check, what NanoHomeComputer SW uses:
		* ATmega328P Timer1 16bits; Timer0 and Timer2 8bits
		* TIMER0_OVF - millis() in Arduino (prescaler x1024), VGA (prescaler x8)
		* TIMER0_COMPA - VGA main asm procedure/line loop
		* TCNT2 - VGA jitter - need prescaler x1 (no prescaling)
		* TIMER1_OVF - frames VGA, lines RCA
		* TIMER1_COMPB - RCAout
		* UCSR0x - RCA USART
* 2025.06.16
	* The next step is to decide, which ports and pins will be used for needed functions
		* external memory (the pins are **fixed** in HW)
			* PA[0..7] is AD0-7 and A0-7 for external memory
			* PC[0..7] is A8-15 for external memory
			* PG0 is WR (write active low)
			* PG1 is RD (read active low)
			* PG2 is ALE (address latch enabled)
		* I/O (Serial/UART, I2C, SPI, ISCP, ...) - I would like to have the basic interfaces available even in the fully populated variant - so let's preliminarily allocate them for now:
			* PB[0..3] ISCP, SPI
			* PE[0..1] RX/TX USART0
			* PD[0..1] I2C/TWI
		* VGA
			* (PE5)PE[7] 16MHz ( **fixed** in HW)
			* ? PB[6] Timer 1 B for Hsync
			* ?? PE[4] Timer 3 B for Vsync
			* ?? PF[0..7] for data out
			* ?? PJ[0..7] for colors out
			* ?? PB[7] Latch
			* ?? PB[4..5] PS/2 pins
			* ?? PE[3] PS/2 Envelope
			* ?? Timer 4 jitter
		* RCA
			* ? PD[2..3] USART1 RX/TX
		* free so far:
			* PB[4..7] TC1
				* ? PB [4..5,7] --
				* ?? ---
			* PD[2..7] USART1
				* ? PD [4..7] --
			* PE[2..6] TC3
				* ?? PE[2-3,5-6]
			* PF full (JTAG, ADC)
				* ?? ---
			* PG[3..5] TC0
			* PH full USART2 TC2,4
			* PJ full USART3 PCINT
				* ?? --
			* PK full ADC, PCINT
			* PL full TC4,5
	* in `NanoHomeComputer <https://github.com/githubgilhad/NanoHomeComputer>`__ were pins and timers allocated as this:
		* VGA part:
			* PC[2..5] (A2-5) VGA colors = i/O
			* PD[0..7] (D0-7) data out = i/O - 8bits = 1 byte!
			* PB[0] (D8) PL i/O 16MHz - HW
			* PB[2] (D10) Vsync i/O - HW
			* PB[3] (D11) CP    i/O latch data
			* PB[4] (D12) Hsync i/O - SW
		* RCA part
			* PB[1] (D9) Sync - HW
			* PD[0..1] (D0-1) USART (both blocked by HW, used only TX PD1)
			* PD[2] (D2) data Enable (prevents floating pin PD1) - SW
		* PS/2 part
			* PC[0..1] (A0-1) PS/2 = I/o Input
			* PB[5] (D13) PS/2 envelope (change?) - Input

* 2025.06.15
	* I had already installed `memxFORTH-core <https://github.com/githubgilhad/memxFORTH-core>`__ there, so I could test it by setting different pins to output and read what is on the port:
	
	.. code:: FORTH
	
		: x DUP 0 PORTE C! DDRE C! PORTE C! PINE C@ FC AND . ; \ ( clear output on PE,
		\ open another pin for output and set it, read the port, ignore bits 0 and 1 (RX TX) )
		: p? PINE C@ 0FC AND . ; ( what is on Port E? )
		: p! PORTE C! p? ; ( set port E to value on Top Of Stack (TOS) )
		: pp ff PINE C! p? ; ( change all output pins on port E to other values )
		bit3 x ( set PE3 - nice, nothing extra happened )
		0 p! ( just normal function )
		bit7 x ( try the hack )
		p? ( WOW we read 1 on PE5 and PE6 and PE7, also Arduino D3 is ON )
		0 p! ( and now it is OFF again - nice ! )
	
	* well, it was more complicated, but having FORTH there already the testing went smooth - it is really nice to be able interactively send signals on any pin, set it for output/input or let it go ON-OF-ON to see on osciloscope, what happened anywhere
	* and with working connection out, I could set the PE7 to output 16MHz on Arduino D3:

	.. code:: bash
	
		# what fuses are there anyway?
		/usr/bin/avrdude -U hfuse:r:-:h -U lfuse:r:-:h -U efuse:r:-:h -v -V -p atmega2560 -D -c usbasp
		# hfuse: 0xd8 lfuse: 0xff efuse: 0xfd
		# fuse 0x40 enables the clock
		/usr/bin/avrdude -U lfuse:w:0xBF:m -v -V -p atmega2560 -D -c usbasp
		# what fuses are there now?
		/usr/bin/avrdude -U hfuse:r:-:h -U lfuse:r:-:h -U efuse:r:-:h -v -V -p atmega2560 -D -c usbasp
		# hfuse: 0xd8 lfuse: 0xBf efuse: 0xfd
	
	* and osciloscope now see nice 16MHz on D3 :)

* 2025.06.15
	On ATmega2560 the system clock can be ouput on Port E pin 7 (PE7) - which is not connected to any pin on Arduino Mega, nor on Arduino Mega PRO.
	But I/O pins on ATmega2560 are by default in read state, which mean high input rezistance, no output signal.
	Therefore I can connect PE7 to PE5 (which is ~D3 on Arduino), **NEVER** use PE5 for output (or special functions)
	and "use it just for reading input signal from outside = PE7 = 16MHz" which does not bring any new information, but is easy way how have the 16MHz on Arduino D3 and so usable.

	* Here is the trace from Arduino D3 to ATmega2560 PE5 and marked PE7 pin
	
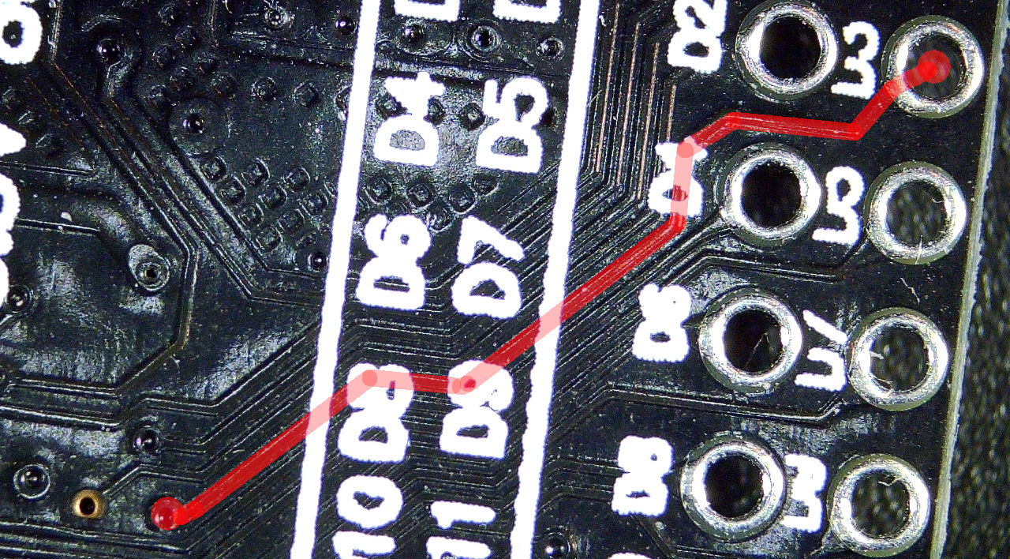
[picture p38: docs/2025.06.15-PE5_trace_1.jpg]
		
		
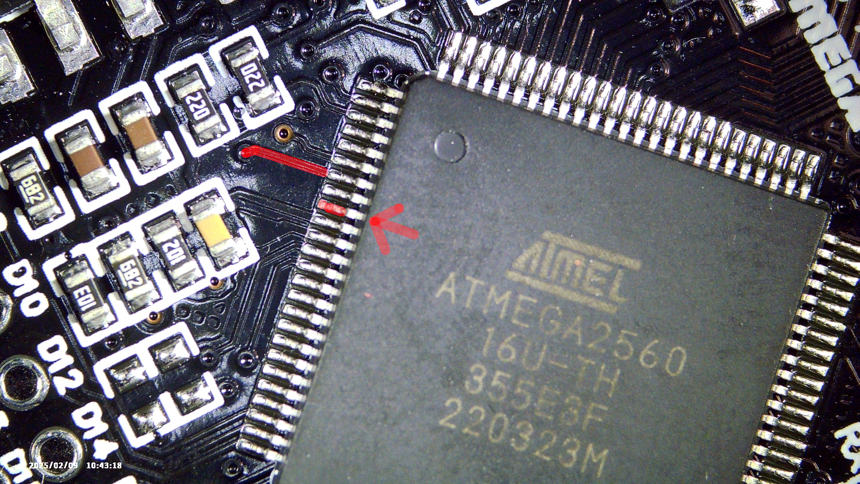
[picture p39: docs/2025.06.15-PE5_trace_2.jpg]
		
	
	* Here is, how it my microskope shows it on close
	
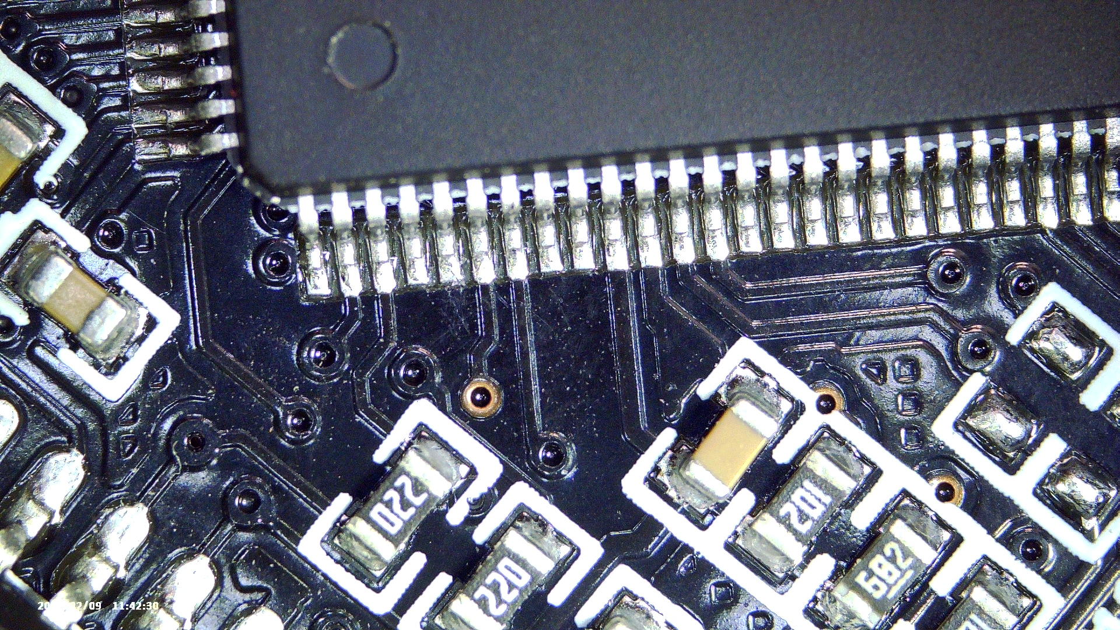
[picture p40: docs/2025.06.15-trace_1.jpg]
		

	* And I took 0.2mm enameled wire
	
		
	
	* And soldered it there (took me like half a hour)
	
		
	
	* and tested it with FORTH and it behave wrong way
	* Ops, I connected wrong pins.
	* When fixing it, I shortcuted PE7 and PE6 and instead of fixing it (which was too dificult) I just "sacrificed" the PE6 too and made bridge to PE5 (later I will desolder the chip and clean it and sorder it on the new PCB - so it is just temporary)
	
		

* 2025.06.14
	I just started this site, now I need to set usable structure, take photo of Arduino Mega Pro and decide on how take out 16MHz for testing purposes without making whole PCB
	
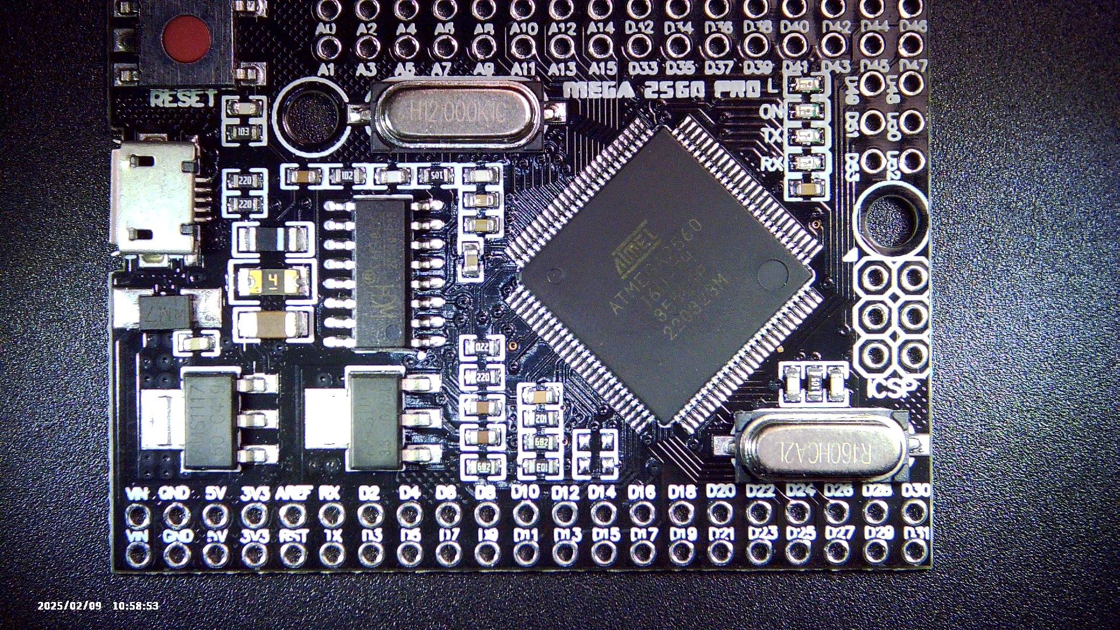
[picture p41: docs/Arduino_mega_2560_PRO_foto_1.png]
	



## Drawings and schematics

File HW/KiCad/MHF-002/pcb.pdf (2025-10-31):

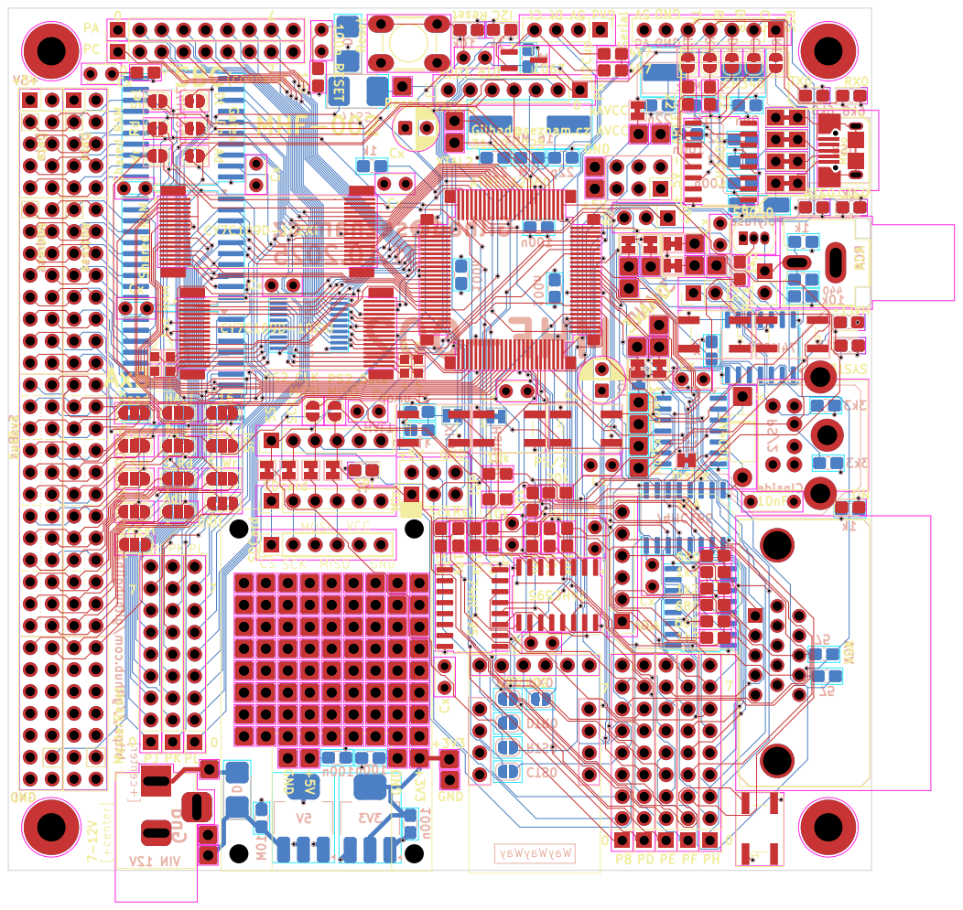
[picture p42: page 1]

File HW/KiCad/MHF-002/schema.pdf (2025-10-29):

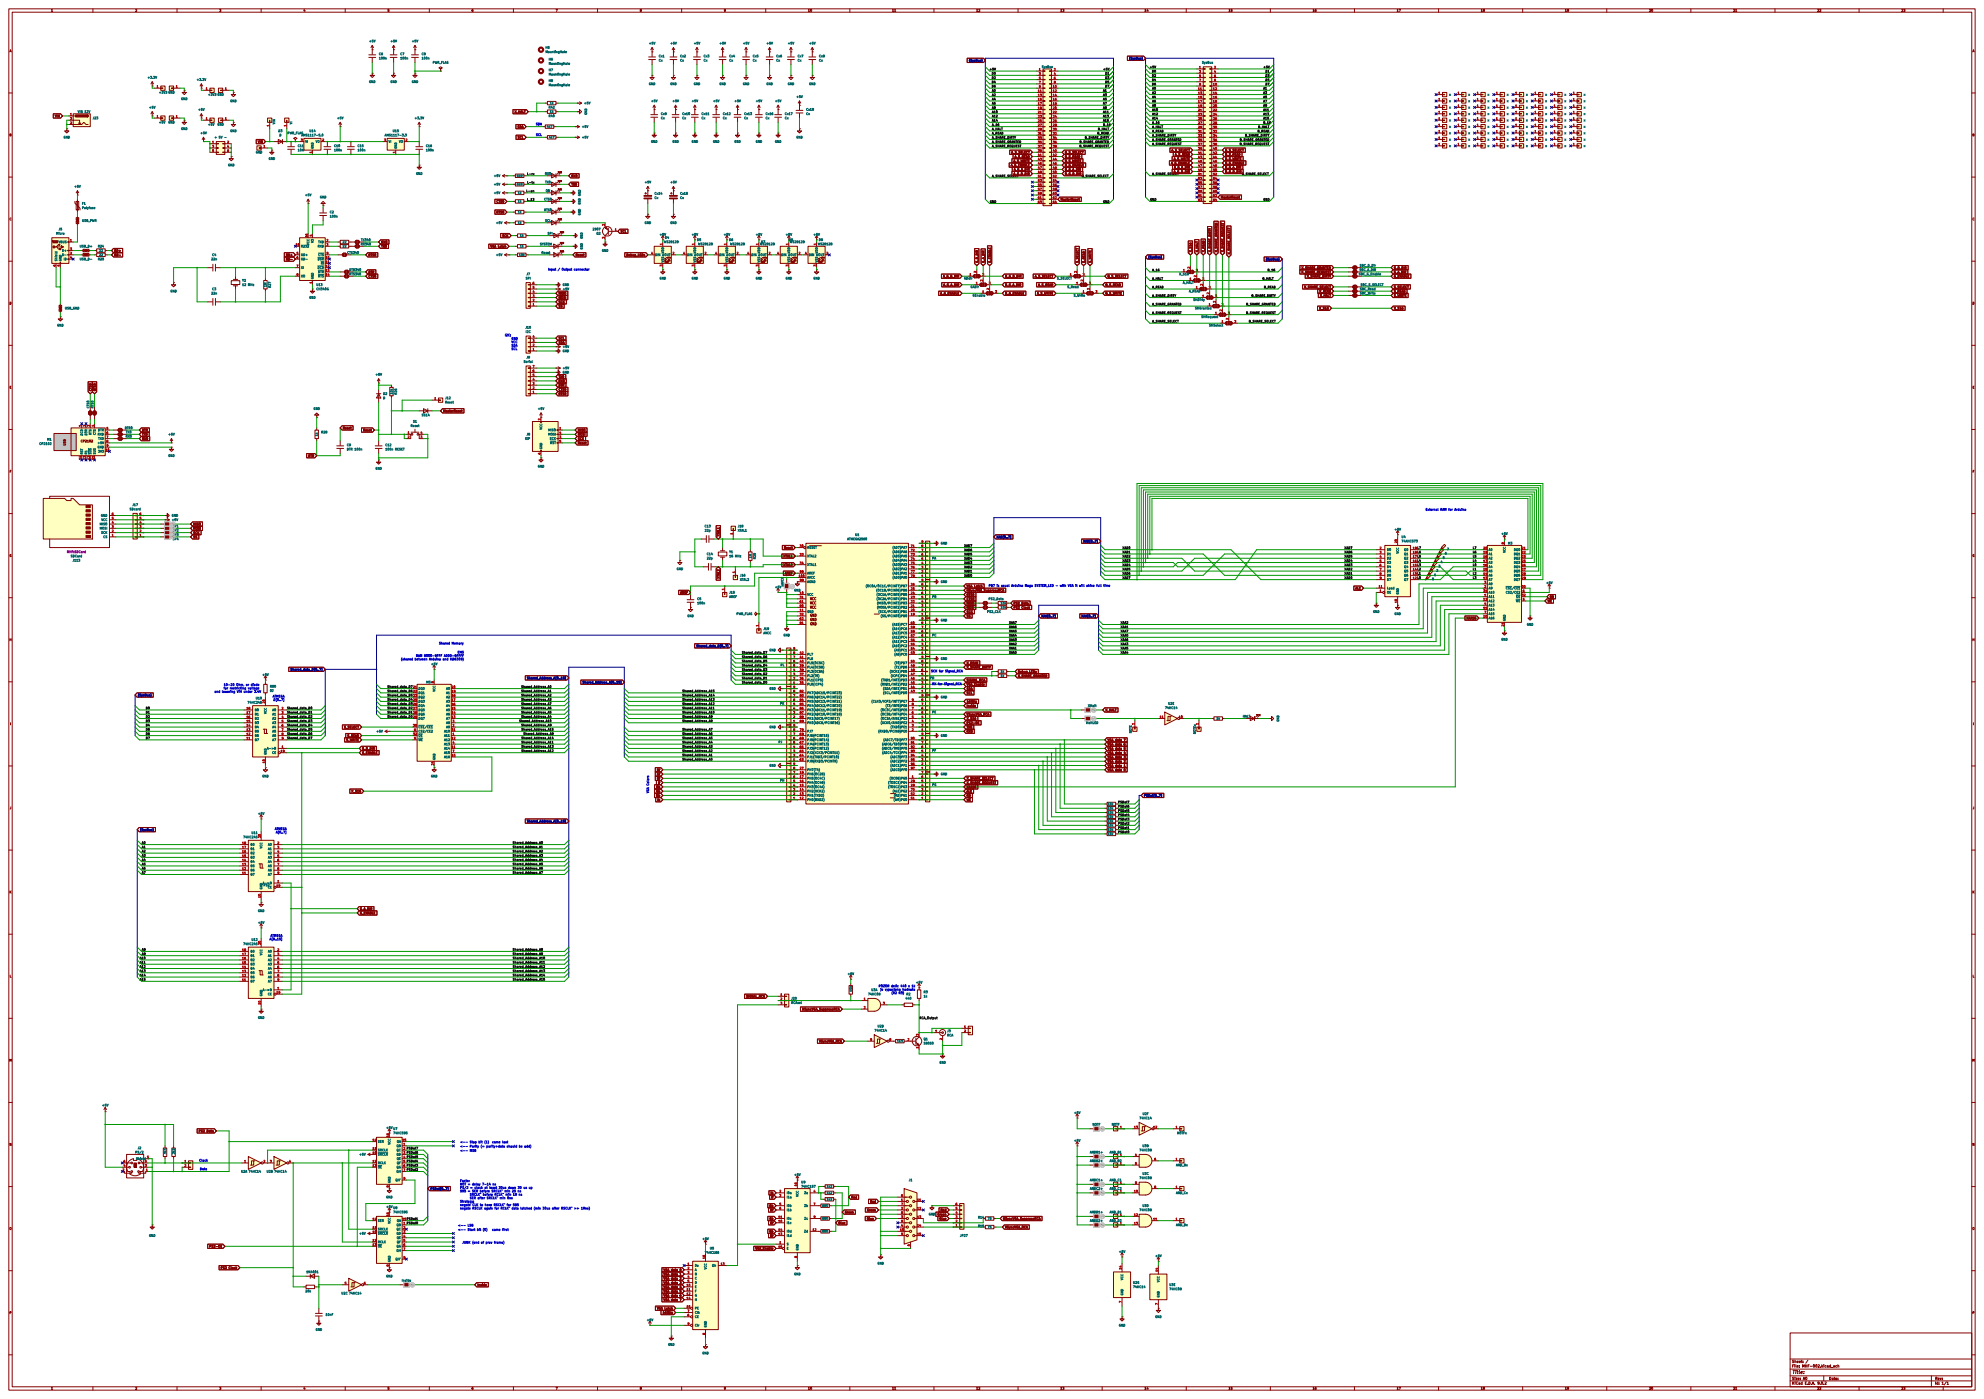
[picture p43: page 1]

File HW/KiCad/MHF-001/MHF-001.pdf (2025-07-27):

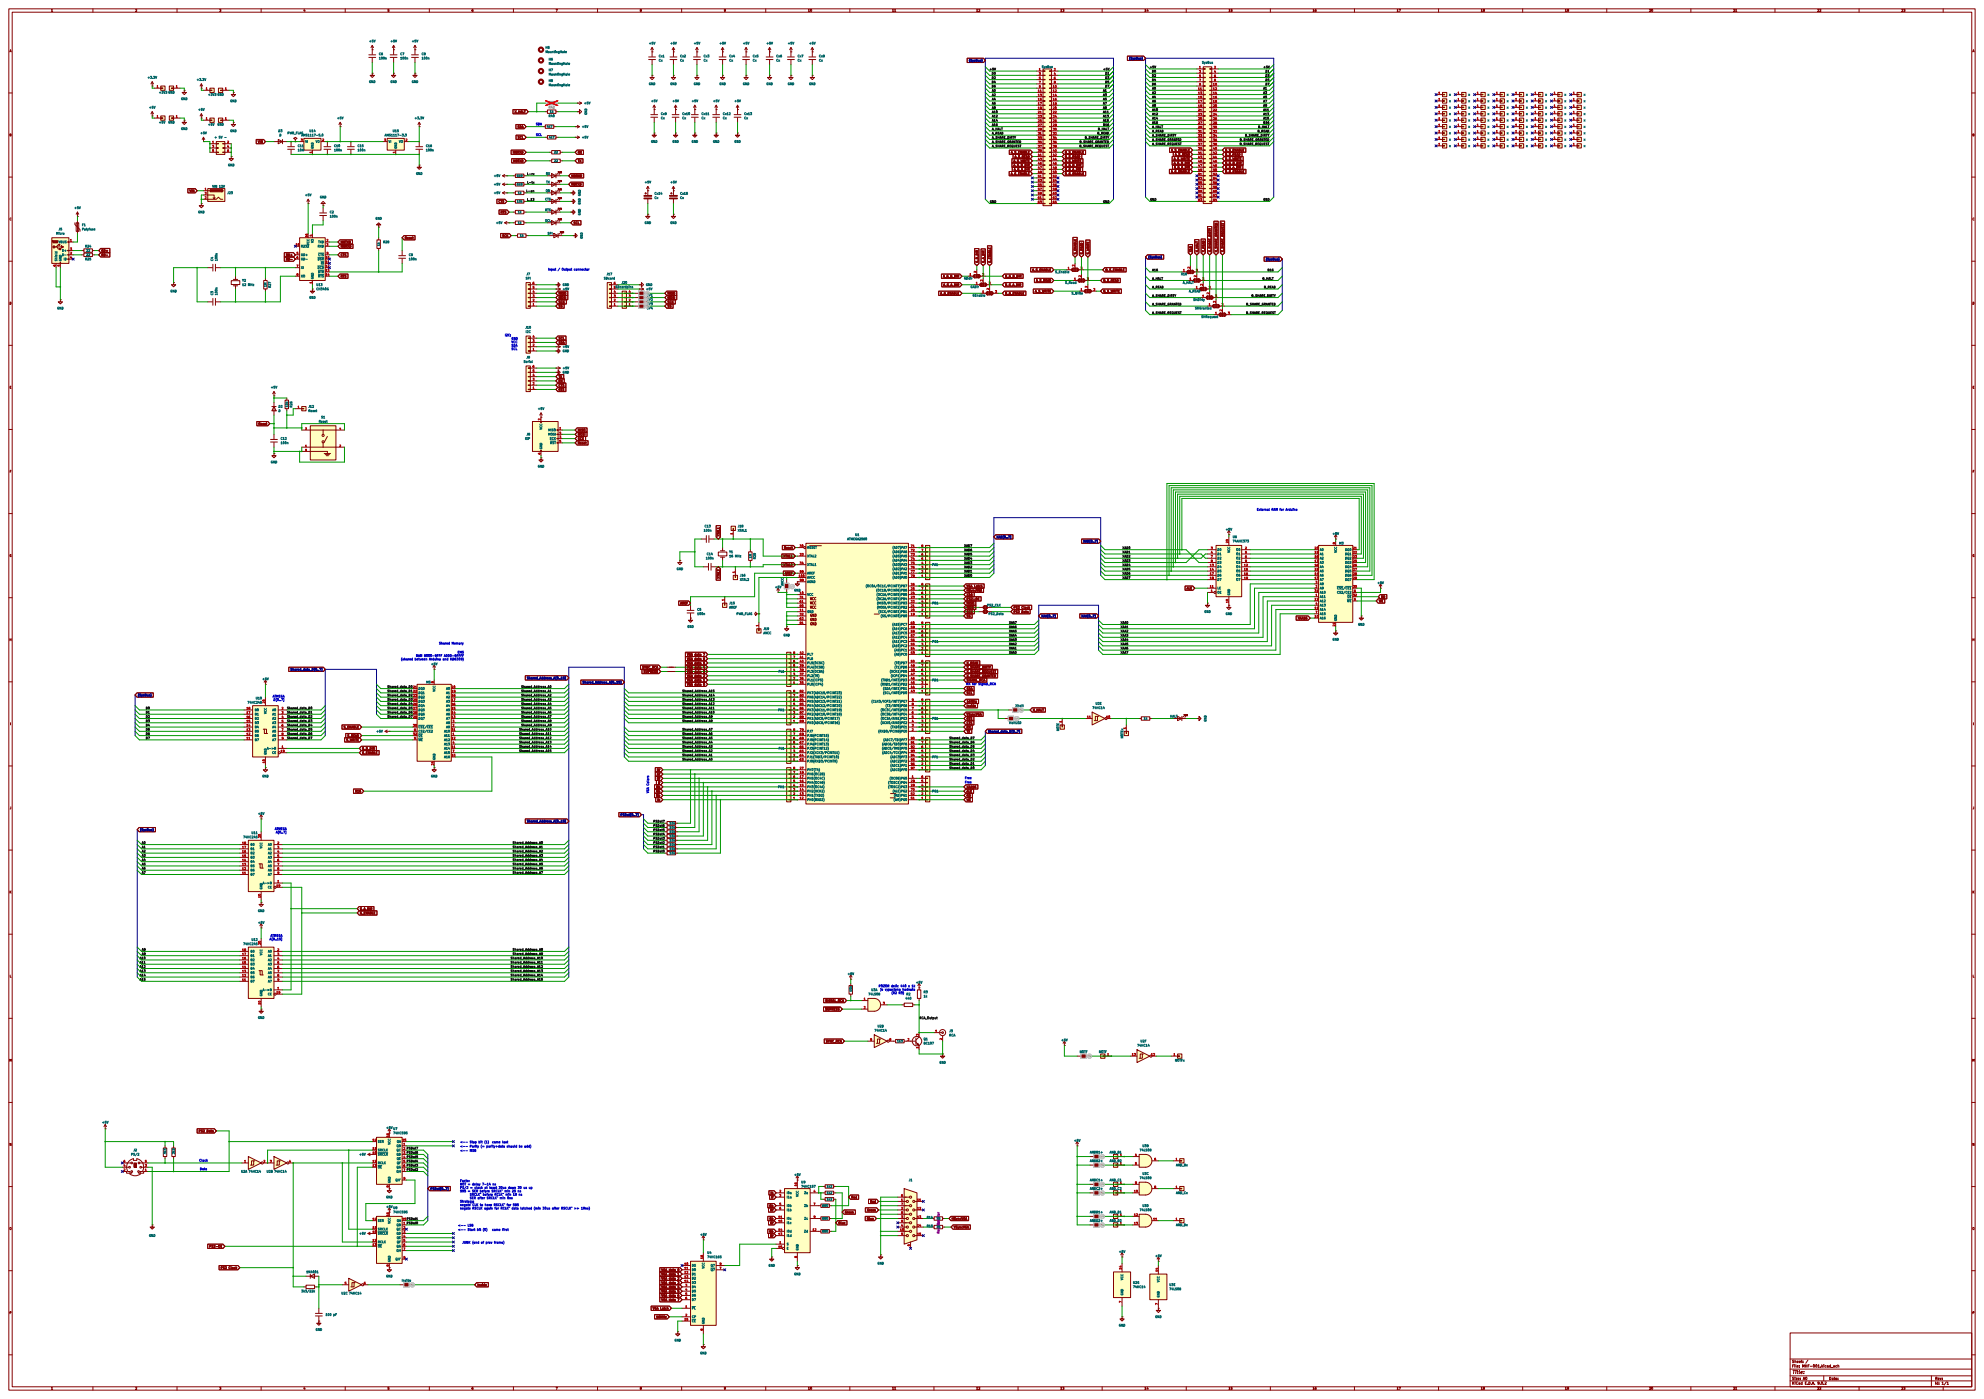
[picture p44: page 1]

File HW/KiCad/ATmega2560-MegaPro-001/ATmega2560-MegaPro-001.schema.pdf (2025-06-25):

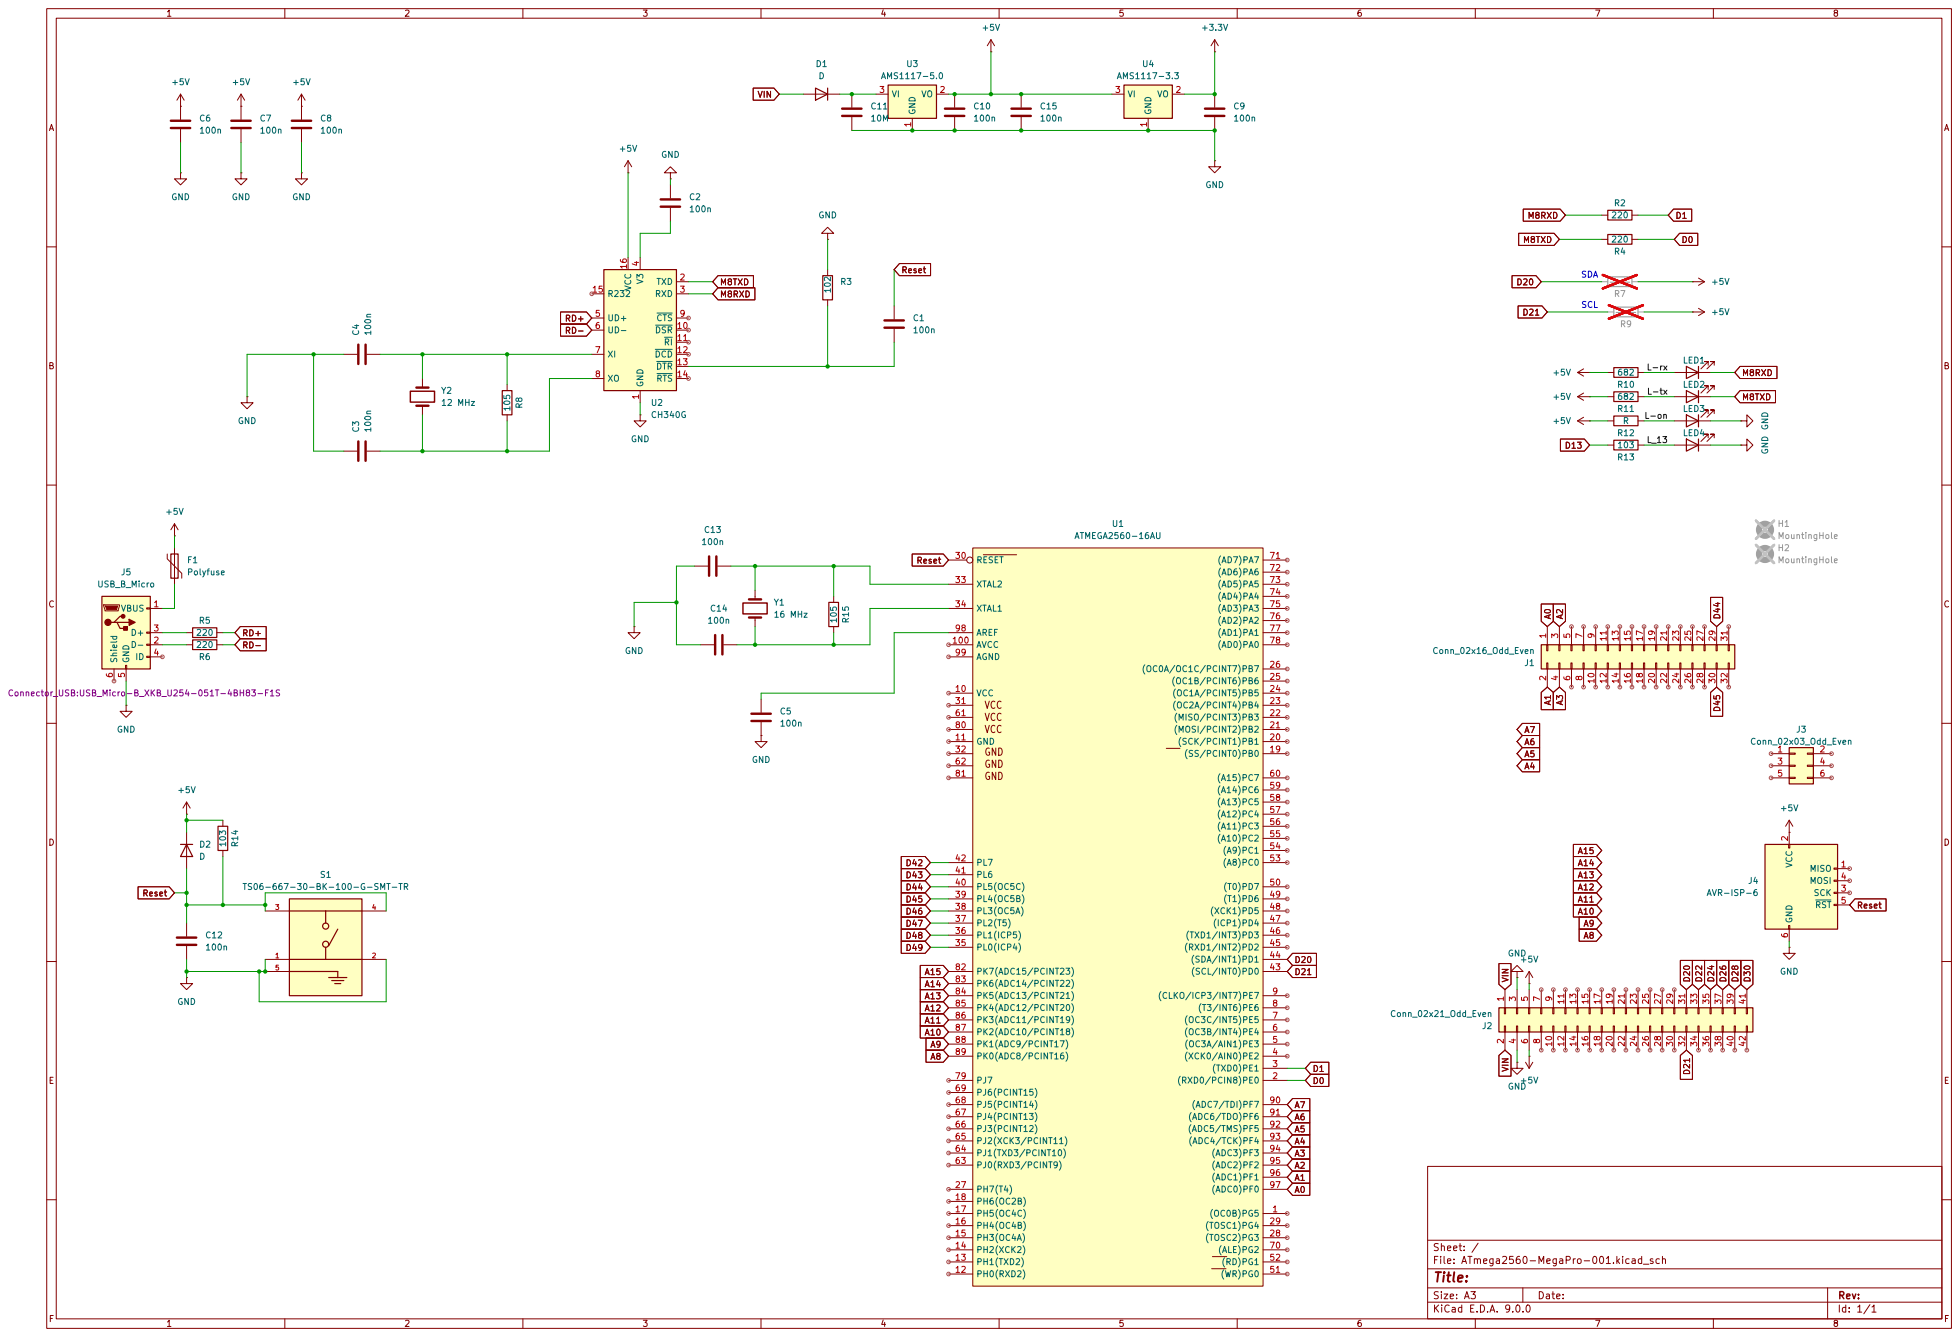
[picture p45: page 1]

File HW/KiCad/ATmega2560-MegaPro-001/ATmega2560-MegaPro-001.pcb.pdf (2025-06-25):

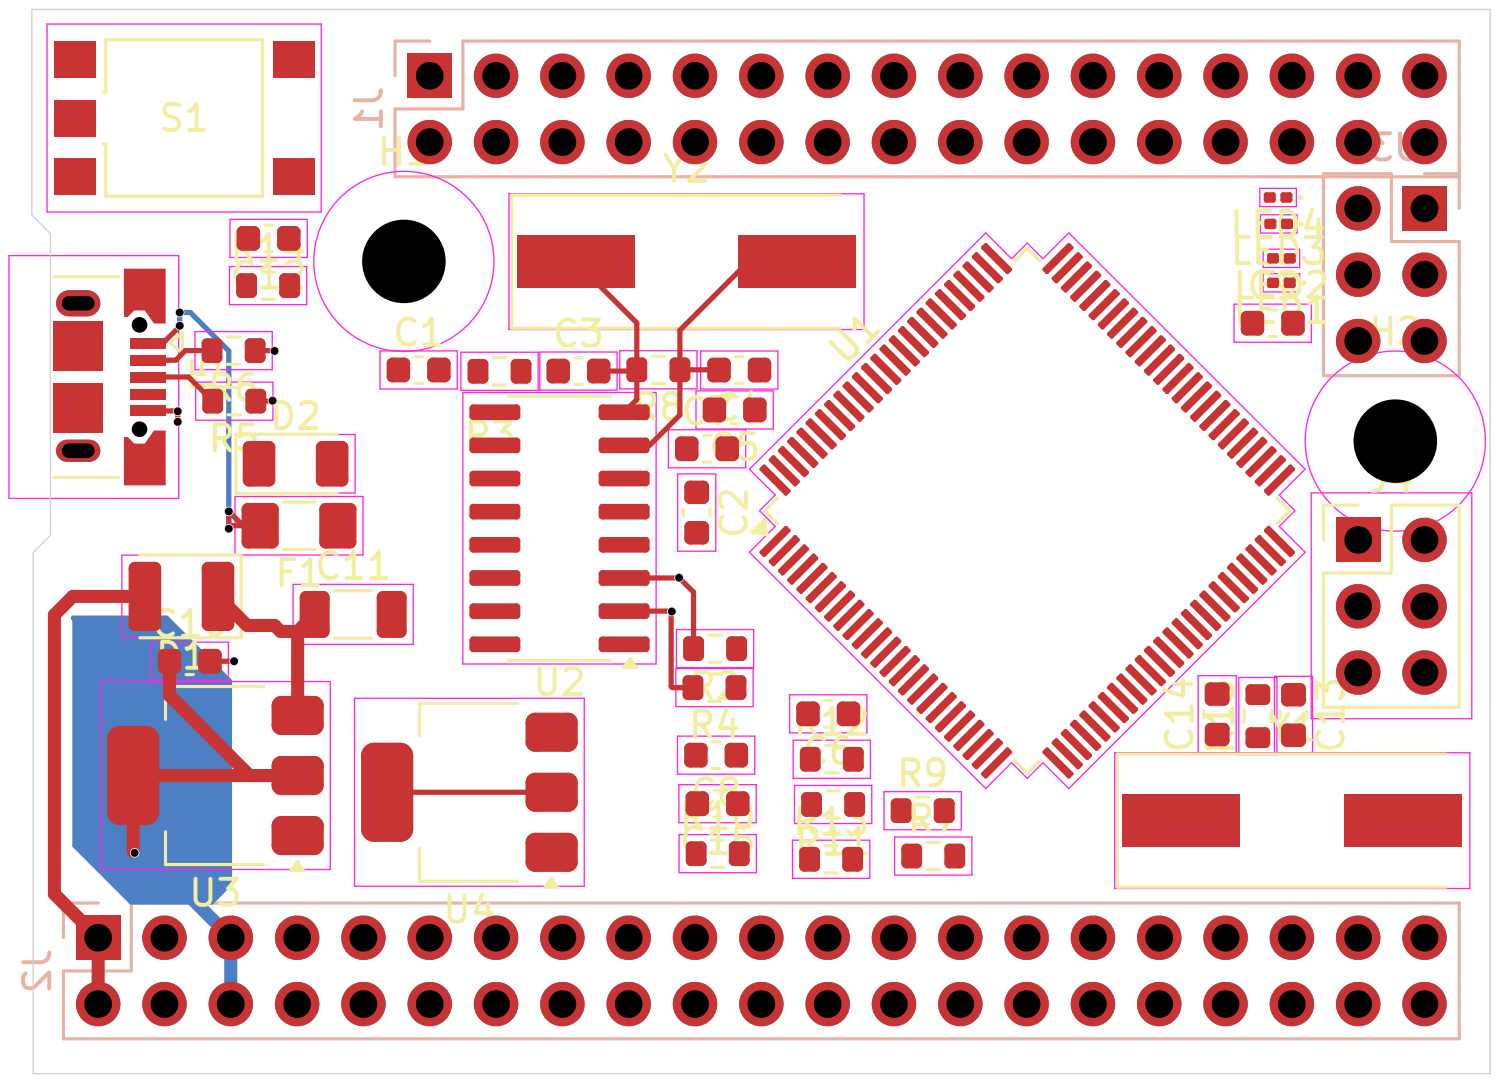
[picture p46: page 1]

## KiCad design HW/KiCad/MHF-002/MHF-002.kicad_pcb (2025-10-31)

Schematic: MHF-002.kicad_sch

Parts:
C1: 10nF; C_Disc_D4.3mm_W1.9mm_P5.00mm
C2, C5, C6, C7, C8, C10, C15, C16: 100n; C_0805_2012Metric_HandSolder
C3, C4: 22n; C_0805_2012Metric_HandSolder
C9: DTR 100n; C_Disc_D3.0mm_W2.0mm_P2.50mm
C11: 10M; C_0805_2012Metric_HandSolder
C12: 100n RESET; C_Disc_D3.0mm_W2.0mm_P2.50mm
C13, C14: 22p; C_0805_2012Metric_HandSolder
Cx1, Cx2, Cx3, Cx4, Cx5, Cx6, Cx7, Cx8, Cx9, Cx10, Cx11, Cx12, Cx13, Cx16, Cx17, Cx18: Cx; C_Disc_D3.0mm_W2.0mm_P2.50mm
Cx14, Cx15: Cx; CP_Radial_D5.0mm_P2.50mm
D1: 1N4001; D_DO-41_SOD81_P9.4mm_Horizontal
D2, D3: D; D_1210_3225Metric_HandSolder
D4, D5, D6, D7, D8, D9: WS2812B; LED_WS2812B_PLCC4_5.0x5.0mm_P3.2mm_HandSolder
D10: SS14; D_1812_4532Metric_Pad1.30x3.40mm_HandSolder
F1: Polyfuse; Fuse_1206_3216Metric_Pad1.42x1.75mm_HandSolder
H5, H6, H7, H8: MountingHole; MountingHole_3.2mm_M3_Pad
J1: VGA; DSUB-15-HD_Socket_Horizontal_P2.29x2.54mm_EdgePinOffset8.35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
J2: PS/2; J_Mini-DIN-6
J3: RCA; CUI_RCJ-047_Yellow
J4: SysBus; PinSocket_2x32_P2.54mm_Vertical
J5: Micro; USB_Micro-B_XKB_U254-051T-4BH83-F1S
J6: SysBus; PinHeader_2x32_P2.54mm_Vertical_down
J7: SPI; PinHeader_1x06_P2.54mm_Vertical
J8: ISP; PinHeader_2x03_P2.54mm_Vertical
J9: Serial; PinHeader_1x07_P2.54mm_Vertical
J10: I2C; PinHeader_1x04_P2.54mm_Vertical
J11: + 5V -; PinSocket_2x03_P2.54mm_Vertical
J12: Reset; PinHole_1x01_2.54xrectangle
J13, J110: +5V; PinHole_1x01_2.54xrectangle
J14, J108, J111, J112, J116: GND; PinHole_1x01_2.54xrectangle
J15: AREF; PinHole_1x01_2.54xrectangle
J16: XTAL2; PinHole_1x01_2.54xrectangle
J17: SDcard; PinHeader_1x06_P2.54mm_Vertical
J18: XTAL1; PinHole_1x01_2.54xrectangle
J19: AVCC; PinHole_1x01_2.54xrectangle
J20: RCAsel; PinHeader_1x03_P2.54mm_Vertical
J21, J22, J37, J38, J39, J40, J41, J42, J43, J44, J45, J46, J47, J48, J49, J50, J51, J52, J53, J54, J55, J56, J57, J58, J59, J60, J61, J62, J63, J64, J65, J66, J67, J68, J69, J70, J71, J72, J73, J74, J75, J76, J77, J78, J79, J80, J81, J82, J83, J84, J85, J86, J87, J88, J89, J90, J91, J92, J93, J94, J95, J96, J97, J98, J99, J100, J101, J102, J103, J104, J105, J106: x; PinHole_1x01_2.54xrectangle
J23: VIN 12V; BarrelJack_Horizontal
J24: AND_B1; PinHole_1x01_2.54xrectangle
J25: AND_B2; PinHole_1x01_2.54xrectangle
J26: AND_C1; PinHole_1x01_2.54xrectangle
J27: AND_C2; PinHole_1x01_2.54xrectangle
J28: AND_D1; PinHole_1x01_2.54xrectangle
J29: AND_D2; PinHole_1x01_2.54xrectangle
J30: AND_Dx; PinHole_1x01_2.54xrectangle
J31: AND_Cx; PinHole_1x01_2.54xrectangle
J32: AND_Bx; PinHole_1x01_2.54xrectangle
J33: NOTF; PinHole_1x01_2.54xrectangle
J34: NOTE; PinHole_1x01_2.54xrectangle
J35: NOTEx; PinHole_1x01_2.54xrectangle
J36: NOTFx; PinHole_1x01_2.54xrectangle
J107, J109: +3V3; PinHole_1x01_2.54xrectangle
J113: SDCard
J114: VIN; PinHole_1x01_2.54xrectangle
J115: VI; PinHole_1x01_2.54xrectangle
JP1: MISO; SolderJumper-2_P1.3mm_Bridged_Pad1.0x1.5mm
JP2: MOSI; SolderJumper-2_P1.3mm_Bridged_Pad1.0x1.5mm
JP3: SCK; SolderJumper-2_P1.3mm_Bridged_Pad1.0x1.5mm
JP4: SS; SolderJumper-2_P1.3mm_Bridged_Pad1.0x1.5mm
JP5: ANDB1+; SolderJumper-2_P1.3mm_Bridged_Pad1.0x1.5mm
JP6: ANDB2+; SolderJumper-2_P1.3mm_Bridged_Pad1.0x1.5mm
JP7: ANDC1+; SolderJumper-2_P1.3mm_Bridged_Pad1.0x1.5mm
JP8: ANDC2+; SolderJumper-2_P1.3mm_Bridged_Pad1.0x1.5mm
JP9: ANDD1+; SolderJumper-2_P1.3mm_Bridged_Pad1.0x1.5mm
JP10: ANDD2+; SolderJumper-2_P1.3mm_Bridged_Pad1.0x1.5mm
JP11: NOTF; SolderJumper-2_P1.3mm_Bridged_Pad1.0x1.5mm
JP12: HaltLED; SolderJumper-2_P1.3mm_Bridged_Pad1.0x1.5mm
JP13: XHalt; SolderJumper-2_P1.3mm_Bridged_Pad1.0x1.5mm
JP14: xAVCC; SolderJumper-2_P1.3mm_Bridged_Pad1.0x1.5mm
JP15: TX340; SolderJumper-2_P1.3mm_Open_RoundedPad1.0x1.5mm
JP16: RX340; SolderJumper-2_P1.3mm_Open_RoundedPad1.0x1.5mm
JP17: CTS340; SolderJumper-2_P1.3mm_Open_RoundedPad1.0x1.5mm
JP18: DTR340; SolderJumper-2_P1.3mm_Open_RoundedPad1.0x1.5mm
JP19: RTS340; SolderJumper-2_P1.3mm_Open_RoundedPad1.0x1.5mm
JP20: USB_GND; G_Rework_Jumper_Bridged_2.54mm
JP21: RX0; SolderJumper-2_P1.3mm_Open_RoundedPad1.0x1.5mm
JP22: TX0; SolderJumper-2_P1.3mm_Open_RoundedPad1.0x1.5mm
JP23: RTS0; SolderJumper-2_P1.3mm_Open_RoundedPad1.0x1.5mm
JP24: DTR0; SolderJumper-2_P1.3mm_Open_RoundedPad1.0x1.5mm
JP25: CTS0; SolderJumper-2_P1.3mm_Open_RoundedPad1.0x1.5mm
JP26: PS2; PinHeader_1x02_P2.54mm_Vertical
JP27: VGA; PinHeader_1x06_P2.54mm_Vertical
JP28: RCA; PinHeader_1x02_P2.54mm_Vertical
JP29: SBC_D_Dir; SolderJumper-2_P1.3mm_Open_RoundedPad1.0x1.5mm
JP30: USB_PWR; G_Rework_Jumper_Bridged_2.54mm
JP31: USB_D+; G_Rework_Jumper_Bridged_2.54mm
JP32: USB_D-; G_Rework_Jumper_Bridged_2.54mm
JP33: SBC_A_DIR; SolderJumper-2_P1.3mm_Open_RoundedPad1.0x1.5mm
JP34: SBC_G_Enable; SolderJumper-2_P1.3mm_Open_RoundedPad1.0x1.5mm
JP35: SBC_S_SELECT; SolderJumper-2_P1.3mm_Open_RoundedPad1.0x1.5mm
JP36: SBC_Read; SolderJumper-2_P1.3mm_Open_RoundedPad1.0x1.5mm
JP37: SBC_Write; SolderJumper-2_P1.3mm_Open_RoundedPad1.0x1.5mm
JP38: SHSelect; SolderJumper-3_P1.3mm_Open_RoundedPad1.0x1.5mm
JP55: PS2_Data; SolderJumper-2_P1.3mm_Open_RoundedPad1.0x1.5mm
JP56: PS2_CLK; SolderJumper-2_P1.3mm_Open_RoundedPad1.0x1.5mm
JP91: Inside; SolderJumper-2_P1.3mm_Bridged_Pad1.0x1.5mm
JP92: X_S16; SolderJumper-3_P1.3mm_Open_RoundedPad1.0x1.5mm
JP94: A_HALT; SolderJumper-3_P1.3mm_Open_RoundedPad1.0x1.5mm
JP95: A_READ; SolderJumper-3_P1.3mm_Open_RoundedPad1.0x1.5mm
JP98: SHDirty; SolderJumper-3_P1.3mm_Open_RoundedPad1.0x1.5mm
JP99: SHGranted; SolderJumper-3_P1.3mm_Open_RoundedPad1.0x1.5mm
JP100: SHRequest; SolderJumper-3_P1.3mm_Open_RoundedPad1.0x1.5mm
JP102: S_SELECT; SolderJumper-3_P1.3mm_Open_RoundedPad1.0x1.5mm
JP103: S_Read; SolderJumper-3_P1.3mm_Open_RoundedPad1.0x1.5mm
JP104: S_Write; SolderJumper-3_P1.3mm_Open_RoundedPad1.0x1.5mm
JP105: GDdir; SolderJumper-3_P1.3mm_Open_RoundedPad1.0x1.5mm
JP106: GEnable; SolderJumper-3_P1.3mm_Open_RoundedPad1.0x1.5mm
JP107: GADir; SolderJumper-3_P1.3mm_Open_RoundedPad1.0x1.5mm
LED1: RX0; LED_0805_2012Metric
LED2: TX0; LED_0805_2012Metric
LED3: ON; LED_0805_2012Metric
LED4: CTS0; LED_0805_2012Metric
LED5: RTS0; LED_0805_2012Metric
LED6: SCL; LED_0805_2012Metric
LED7: SPI; LED_0805_2012Metric
LED8: HALT; LED_0805_2012Metric
LED9: SYSTEM; LED_0805_2012Metric
LED10: Reset; LED_0805_2012Metric
M1: CP2102; G_CP2102
M3, M5: CY7C109D-10ZXI; G_TSOP-I-32_18.4x8mm_HandSolder
PA1: PA; PinHeader_1x09_P2.54mm_Vertical
PB1: PB; PinHeader_1x09_P2.54mm_Vertical
PC1: PC; PinHeader_1x09_P2.54mm_Vertical
PD1: PD; PinHeader_1x09_P2.54mm_Vertical
PE1: PE; PinHeader_1x09_P2.54mm_Vertical
PF1: PF; PinHeader_1x09_P2.54mm_Vertical
PG1: PG; PinHeader_1x07_P2.54mm_Vertical
PH1: PH; PinHeader_1x09_P2.54mm_Vertical
PJ1: PJ; PinHeader_1x09_P2.54mm_Vertical
PK1: PK; PinHeader_1x09_P2.54mm_Vertical
PL1: PL; PinHeader_1x09_P2.54mm_Vertical
Q1: S8050; TO-92_Inline
Q2: 2907; TSOT-23_HandSoldering
R1: 20k; R_0805_2012Metric_Pad1.20x1.40mm_HandSolder
R2: 440; R_0805_2012Metric_Pad1.20x1.40mm_HandSolder
R3, R28, R36, R37, R38, R39, R40, R41, R42, R43, R46, R48, R49: 1k; R_0805_2012Metric_Pad1.20x1.40mm_HandSolder
R4: 1k3; R_0805_2012Metric_Pad1.20x1.40mm_HandSolder
R5, R16, R17, R18, R19, R20, R21, R22, R23, R26, R44, R45, R47: 10k; R_0805_2012Metric_Pad1.20x1.40mm_HandSolder
R6, R7, R8: 1k2; R_0805_2012Metric_Pad1.20x1.40mm_HandSolder
R9, R10, R11: 680; R_0805_2012Metric_Pad1.20x1.40mm_HandSolder
R12, R13: 3k3; R_0805_2012Metric_Pad1.20x1.40mm_HandSolder
R14, R15: 75; R_0805_2012Metric_Pad1.20x1.40mm_HandSolder
R24, R25, R30, R31: 22; R_0805_2012Metric_Pad1.20x1.40mm_HandSolder
R27, R29: 1M; R_0805_2012Metric_Pad1.20x1.40mm_HandSolder
R32, R33: 4k7; R_0805_2012Metric_Pad1.20x1.40mm_HandSolder
R34, R35: 6k8; R_0805_2012Metric_Pad1.20x1.40mm_HandSolder
R50: 0?; R_0805_2012Metric_Pad1.20x1.40mm_HandSolder
S1: Reset; G_Arduino_switch; PARTREV 1.0
TP1: 7; TestPoint_Pad_1.0x1.0mm
TP2: 0; TestPoint_Pad_1.0x1.0mm
TP3: 1; TestPoint_Pad_1.0x1.0mm
TP4: 2; TestPoint_Pad_1.0x1.0mm
TP5: 3; TestPoint_Pad_1.0x1.0mm
TP6: 4; TestPoint_Pad_1.0x1.0mm
TP7: 5; TestPoint_Pad_1.0x1.0mm
TP8: 6; TestPoint_Pad_1.0x1.0mm
U1: ATMEGA2560; G_TQFP-100_14x14mm_HandSolder
U2: 74HC14; SOIC-14_3.9x8.7mm_P1.27mm
U3: 74HC08; SOIC-14_3.9x8.7mm_P1.27mm
U4: 74AHC573; TSSOP-20_4.4x6.5mm_P0.65mm_HandSolder
U5: 74HC166; SOIC-16_3.9x9.9mm_P1.27mm
U7, U8: 74HC595; SOIC-16_3.9x9.9mm_P1.27mm
U9: 74HC157; SOIC-16_3.9x9.9mm_P1.27mm
U10, U11, U12: 74HC245; G_SOIC-20W_7.5x12.8mm_P1.27mm_HandSolder
U13: CH340G; SOIC-16_3.9x9.9mm_P1.27mm
U14: AMS1117-5.0; SOT-223-3_TabPin2_HandSolder
U15: AMS1117-3.3; SOT-223-3_TabPin2_HandSolder
Y1: 16 MHz; Crystal_SMD_HC49-SD
Y2: 12 MHz; Crystal_SMD_HC49-SD

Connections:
16MHz: PE1.8, U1.9 ((CLKO/ICP3/INT7)PE7), U5.7 (Clk)
+3.3V: C16.1, J107.1, J109.1, U15.2 (VO)
+5V: C6.1, C7.1, C8.1, C10.1, C15.1, Cx1.1, Cx2.1, Cx3.1, Cx4.1, Cx5.1, Cx6.1, Cx7.1, Cx8.1, Cx9.1, Cx10.1, Cx11.1, Cx12.1, Cx13.1, Cx14.1, Cx15.1, Cx16.1, Cx17.1, Cx18.1, D2.1 (K), D4.1 (VDD), D5.1 (VDD), D6.1 (VDD), D7.1 (VDD), D8.1 (VDD), D9.1 (VDD), F1.1, J2.4, J4.1, J4.2, J6.1, J6.2, J7.5, J8.2 (VCC), J9.7, J10.2, J11.1, J11.3, J11.5, J13.1, J17.5, J110.1, J113.5 (VCC), JP5.1 (A), JP6.1 (A), JP7.1 (A), JP8.1 (A), JP9.1 (A), JP10.1 (A), JP11.1 (A), JP14.1 (A), M1.8 (+5V), M3.6 (CS2/CE2), M3.8 (VCC), M5.6 (CS2/CE2), M5.8 (VCC), R3.2, R5.2, R12.2, R13.2, R26.1, R32.1, R33.1, R34.2, R35.2, R36.2, R39.2, R42.1, R47.2, R50.1, U1.10 (VCC), U1.31 (VCC1), U1.61 (VCC2), U1.80 (VCC3), U2.14 (VCC), U3.14 (VCC), U4.20 (VCC), U5.9 (Clr), U5.16 (VCC), U7.10 (~SRCLR), U7.16 (VCC), U8.10 (~SRCLR), U8.16 (VCC), U9.16 (VCC), U11.20 (VCC), U12.20 (VCC), U13.16 (VCC), U14.2 (VO), U15.3 (VI)
/A_16: J4.27, J6.27, JP92.1 (A)
/B_16: J4.28, J6.28, JP92.3 (B)
/L0: M3.16 (A4), TP2.1, U4.12 (Q7)
/L1: M3.15 (A5), TP3.1, U4.13 (Q6)
/L2: M3.14 (A6), TP4.1, U4.14 (Q5)
/L3: M3.13 (A7), TP5.1, U4.15 (Q4)
/L4: M3.17 (A3), TP6.1, U4.16 (Q3)
/L5: M3.18 (A2), TP7.1, U4.17 (Q2)
/L6: M3.19 (A1), TP8.1, U4.18 (Q1)
/L7: M3.20 (A0), TP1.1, U4.19 (Q0)
/L-on: LED3.2 (A), R36.1
/L-rx: LED1.2 (A), R34.1
/L-tx: LED2.2 (A), R35.1
/L_13: LED4.2 (A), R37.1
/RCA_Output: J3.1 (In), JP28.1, Q1.3 (C), R2.2, R3.1
A0: J4.11, J6.11, U11.18 (B0)
A1: J4.12, J6.12, U11.17 (B1)
A2: J4.13, J6.13, U11.16 (B2)
A3: J4.14, J6.14, U11.15 (B3)
A4: J4.15, J6.15, U11.14 (B4)
A5: J4.16, J6.16, U11.13 (B5)
A6: J4.17, J6.17, U11.12 (B6)
A7: J4.18, J6.18, U11.11 (B7)
A8: J4.19, J6.19, U12.18 (B0)
A9: J4.20, J6.20, U12.17 (B1)
A10: J4.21, J6.21, U12.16 (B2)
A11: J4.22, J6.22, U12.15 (B3)
A12: J4.23, J6.23, U12.14 (B4)
A13: J4.24, J6.24, U12.13 (B5)
A14: J4.25, J6.25, U12.12 (B6)
A15: J4.26, J6.26, U12.11 (B7)
ALE: PG1.3, U1.70 ((ALE)PG2), U4.11 (Load)
AREF: C5.1, J15.1, U1.98 (AREF)
A_G_A_DIR: J4.47, J6.47, JP107.1 (A)
A_G_D_DIR: J4.49, J6.49, JP105.1 (A)
A_G_ENABLE: J4.45, J6.45, JP106.1 (A)
A_HALT: J4.29, J6.29, JP94.1 (A)
A_READ: J4.31, J6.31, JP95.1 (A)
A_SHARE_DIRTY: J4.33, J6.33, JP98.1 (A)
A_SHARE_GRANTED: J4.35, J6.35, JP99.1 (A)
A_SHARE_REQUEST: J4.37, J6.37, JP100.1 (A)
A_SHARE_SELECT: J4.51, J6.51, JP38.1 (A)
A_S_READ: J4.41, J6.41, JP103.1 (A)
A_S_SELECT: J4.39, J6.39, JP102.1 (A)
A_S_WRITE: J4.43, J6.43, JP104.1 (A)
B_G_A_DIR: J4.48, J6.48, JP107.3 (B)
B_G_D_DIR: J4.50, J6.50, JP105.3 (B)
B_G_ENABLE: J4.46, J6.46, JP106.3 (B)
B_HALT: J4.30, J6.30, JP94.3 (B)
B_READ: J4.32, J6.32, JP95.3 (B)
B_SHARE_DIRTY: J4.34, J6.34, JP98.3 (B)
B_SHARE_GRANTED: J4.36, J6.36, JP99.3 (B)
B_SHARE_REQUEST: J4.38, J6.38, JP100.3 (B)
B_SHARE_SELECT: J4.52, J6.52, JP38.3 (B)
B_S_READ: J4.42, J6.42, JP103.3 (B)
B_S_SELECT: J4.40, J6.40, JP102.3 (B)
B_S_WRITE: J4.44, J6.44, JP104.3 (B)
Bb: PH1.2, U1.13 (PH1(TXD2)), U9.14 (I0d)
Bf: PH1.6, U1.17 (PH5(OC4C)), U9.13 (I1d)
Blue: J1.3, JP27.3, R8.2, R11.2
CTS0: J9.2, JP19.2 (B), JP25.2 (B), PB1.5, R37.2, U1.23 ((OC2A/PCINT4)PB4)
D0: J4.3, J6.3, U10.18 (B0)
D1: J4.4, J6.4, U10.17 (B1)
D2: J4.5, J6.5, U10.16 (B2)
D3: J4.6, J6.6, U10.15 (B3)
D4: J4.7, J6.7, U10.14 (B4)
D5: J4.8, J6.8, U10.13 (B5)
D6: J4.9, J6.9, U10.12 (B6)
D7: J4.10, J6.10, U10.11 (B7)
DTR: C9.2, J9.3, JP18.2 (B), JP24.2 (B), R28.2
Debug_LEDs: D4.4 (DIN), R49.2
GND: C1.2, C2.1, C3.1, C4.1, C5.2, C6.2, C7.2, C8.2, C10.2, C11.2, C12.2, C13.1, C14.1, C15.2, C16.2, Cx1.2, Cx2.2, Cx3.2, Cx4.2, Cx5.2, Cx6.2, Cx7.2, Cx8.2, Cx9.2, Cx10.2, Cx11.2, Cx12.2, Cx13.2, Cx14.2, Cx15.2, Cx16.2, Cx17.2, Cx18.2, D4.3 (VSS), D5.3 (VSS), D6.3 (VSS), D7.3 (VSS), D8.3 (VSS), D9.3 (VSS), J1.0, J1.5, J1.6, J1.7, J1.8, J1.10, J2.3, J2.S (Shield), J3.2 (Ext), J4.63, J4.64, J6.63, J6.64, J7.6, J8.6 (GND), J9.6, J10.1, J11.2, J11.4, J11.6, J14.1, J17.6, J23.2, J23.3, J108.1, J111.1, J112.1, J113.6 (GND), J116.1, JP20.2 (B), JP27.6, JP28.2, LED3.1 (K), LED4.1 (K), LED5.1 (K), LED7.1 (K), LED8.1 (K), LED9.1 (K), M1.9 (GND), M3.24 (GND), M3.30 (~CS1/~CE1), M5.24 (GND), PA1.9, PB1.9, PC1.9, PD1.9, PE1.9, PF1.9, PG1.7, PH1.9, PJ1.9, PK1.9, PL1.9, Q1.1 (E), Q2.3 (C), R28.1, R40.1, S1.3 (K), S1.4 (A), U1.11 (GND), U1.32 (GND1), U1.62 (GND2), U1.81 (GND3), U1.99 (AGND), U2.7 (GND), U3.7 (GND), U4.1 (OE), U4.10 (GND), U5.6 (CE), U5.8 (GND), U7.8 (GND), U8.8 (GND), U9.8 (GND), U10.10 (GND), U11.10 (GND), U12.10 (GND), U13.1 (GND), U14.1 (GND), U15.1 (GND)
G_A_DIR: JP33.2 (B), JP107.2 (C), U11.1 (A->B), U12.1 (A->B)
G_D_DIR: JP29.2 (B), JP105.2 (C), U10.1 (A->B)
G_ENABLE: JP34.2 (B), JP106.2 (C), U10.19 (CE), U11.19 (CE), U12.19 (CE)
Gb: PH1.3, U1.14 (PH2(XCK2)), U9.11 (I0c)
Gf: PH1.7, U1.18 (PH6(OC2B)), U9.10 (I1c)
Green: J1.2, JP27.4, R7.2, R10.2
HSyncVGA_SuppressRCA: PB1.7, R14.2, U1.25 ((OC1B/PCINT6)PB6), U3.2
Ib: PH1.1, U1.12 (PH0(RXD2)), U9.2 (I0a)
If: PH1.5, U1.16 (PH4(OC4B)), U9.3 (I1a)
Inside: JP91.2 (B), PE1.7, U1.8 ((T3/INT6)PE6)
MISO: J7.4, J8.1 (MISO), JP1.2 (B), JP55.1 (A), PB1.4, U1.22 ((MISO/PCINT3)PB3)
MOSI: J7.3, J8.4 (MOSI), JP2.2 (B), JP56.1 (A), PB1.3, U1.21 ((MOSI/PCINT2)PB2)
MasterReset: D10.1 (K), J4.62, J6.62
unnamed: C1.1, D1.2 (A), R1.1, U2.5
unnamed: C11.1, D3.1 (K), J115.1, U14.3 (VI)
unnamed: D4.2 (DOUT), D5.4 (DIN)
unnamed: D5.2 (DOUT), D6.4 (DIN)
unnamed: D6.2 (DOUT), D7.4 (DIN)
unnamed: D7.2 (DOUT), D8.4 (DIN)
unnamed: D8.2 (DOUT), D9.4 (DIN)
unnamed: J5.3 (D+), JP31.1 (A)
unnamed: J5.2 (D-), JP32.1 (A)
unnamed: J5.5 (GND), J5.6 (Shield), JP20.1 (A)
unnamed: J5.1 (VBUS), JP30.1 (A)
unnamed: J19.1, JP14.2 (B), U1.100 (AVCC)
unnamed: J20.2, R5.1, U3.1
unnamed: J20.3, U5.13 (Qh), U9.1 (S)
unnamed: J24.1, JP5.2 (B), U3.4
unnamed: J25.1, JP6.2 (B), U3.5
unnamed: J26.1, JP7.2 (B), U3.9
unnamed: J27.1, JP8.2 (B), U3.10
unnamed: J28.1, JP9.2 (B), U3.12
unnamed: J29.1, JP10.2 (B), U3.13
unnamed: J30.1, U3.11
unnamed: J31.1, U3.8
unnamed: J32.1, U3.6
unnamed: J33.1, JP11.2 (B), U2.13
unnamed: J34.1, JP12.2 (B), U2.11
unnamed: J35.1, R43.2, U2.10
unnamed: J36.1, U2.12
unnamed: J17.1, J113.1 (CS), JP4.1 (A)
unnamed: J17.4, J113.4 (MISO), JP1.1 (A)
unnamed: J17.3, J113.3 (MOSI), JP2.1 (A)
unnamed: J17.2, J113.2 (SCK), JP3.1 (A)
unnamed: JP12.1 (A), JP13.1 (A), PE1.6, U1.7 ((OC3C/INT5)PE5)
unnamed: JP15.1 (A), R30.1
unnamed: JP16.1 (A), R31.1
unnamed: JP17.1 (A), U13.9 (~CTS)
unnamed: JP18.1 (A), U13.13 (~DTR)
unnamed: JP19.1 (A), U13.14 (~RTS)
unnamed: JP21.1 (A), M1.7 (TXD)
unnamed: JP22.1 (A), M1.6 (RXD)
unnamed: JP23.1 (A), M1.4 (CTS)
unnamed: JP24.1 (A), M1.5 (DTR)
unnamed: JP25.1 (A), M1.3 (RTS)
unnamed: J2.5, JP26.1, R13.1, U2.1
unnamed: J1.14, JP27.1, R15.1
unnamed: J1.13, JP27.2, R14.1
unnamed: F1.2, JP30.2 (B)
unnamed: JP31.2 (B), R24.2
unnamed: JP32.2 (B), R25.2
unnamed: JP55.2 (B), R45.1
unnamed: JP56.2 (B), R44.1
unnamed: JP91.1 (A), U2.6
unnamed: LED5.2 (A), R38.1
unnamed: LED6.2 (A), R39.1
unnamed: LED6.1 (K), Q2.2 (E)
unnamed: LED7.2 (A), R41.1
unnamed: LED8.2 (A), R43.1
unnamed: LED9.2 (A), R46.1
unnamed: LED10.2 (A), R47.1
unnamed: PD1.5, R48.1, R49.1, U1.47 ((ICP1)PD4)
unnamed: PD1.6, U1.48 ((XCK1)PD5)
unnamed: Q1.2 (B), R4.2
unnamed: R2.1, U3.3
unnamed: R4.1, U2.8
unnamed: U7.9 (QH'), U8.14 (SER)
unnamed: U2.2, U2.3, U7.11 (SRCLK), U8.11 (SRCLK)
unnamed: R6.1, R7.1, R8.1, U9.4 (Za)
unnamed: R9.1, U9.7 (Zb)
unnamed: R10.1, U9.9 (Zc)
unnamed: R11.1, U9.12 (Zd)
unnamed: R50.2, U10.20 (VCC)
unnamed: R31.2, U13.3 (RXD)
unnamed: R30.2, U13.2 (TXD)
unnamed: C2.2, U13.4 (V3)
unnamed: C4.2, R27.1, U13.7 (XI), Y2.2
unnamed: C3.2, R27.2, U13.8 (XO), Y2.1
PS2 Clock: D1.1 (K), R1.2, R44.2, U2.4, U7.12 (RCLK), U8.12 (RCLK)
PS2 Data: J2.1, JP26.2, R12.1, R45.2, U7.14 (SER)
PS2-OE: PE1.3, U1.4 ((XCK0/AIN0)PE2), U7.13 (~OE), U8.13 (~OE)
PSDat0: R16.1, U8.1 (QB)
PSDat1: R17.1, U8.15 (QA)
PSDat2: R18.1, U7.7 (QH)
PSDat3: R19.1, U7.6 (QG)
PSDat4: R20.1, U7.5 (QF)
PSDat5: R21.1, U7.4 (QE)
PSDat6: R22.1, U7.3 (QD)
PSDat7: R23.1, U7.2 (QC)
RD: M3.32 (~OE), PG1.2, U1.52 ((RD)PG1)
RD+: R24.1, U13.5 (UD+)
RD-: R25.1, U13.6 (UD-)
RTS0: J9.1, JP17.2 (B), JP23.2 (B), PB1.6, R38.2, U1.24 ((OC1A/PCINT5)PB5)
RX0: J9.4, JP15.2 (B), JP21.2 (B), LED1.1 (K), PE1.1, U1.2 ((RXD0/PCIN8)PE0)
Rb: PH1.4, U1.15 (PH3(OC4A)), U9.5 (I0b)
Red: J1.1, JP27.5, R6.2, R9.2
Reset: C9.1, C12.1, D2.2 (A), D10.2 (A), J8.5 (~RST), J12.1, LED10.1 (K), R26.2, S1.1, S1.2, U1.30 (RESET)
Rf: PH1.8, U1.27 (PH7(T4)), U9.6 (I1b)
SCK: J7.2, J8.3 (SCK), JP3.2 (B), PB1.2, R41.2, U1.20 ((SCK/PCINT1)PB1)
SCL: J10.4, PD1.1, Q2.1 (B), R33.2, U1.43 ((SCL/INT0)PD0)
SDA: J10.3, PD1.2, R32.2, U1.44 ((SDA/INT1)PD1)
SIGNAL_RCA: J20.1, PD1.4, U1.46 ((TXD1/INT3)PD3)
SS: J7.1, JP4.2 (B), PB1.1, U1.19 ((SS/PCINT0)PB0)
S_READ: JP36.2 (B), JP103.2 (C), M5.32 (~OE)
S_SELECT: JP35.2 (B), JP102.2 (C), M5.30 (~CS1/~CE1)
S_WRITE: JP37.2 (B), JP104.2 (C), M5.5 (~WE)
Shared_Address_A0: M5.20 (A0), PJ1.1, U1.63 (PJ0(RXD3/PCINT9)), U11.2 (A0)
Shared_Address_A1: M5.19 (A1), PJ1.2, U1.64 (PJ1(TXD3/PCINT10)), U11.3 (A1)
Shared_Address_A2: M5.18 (A2), PJ1.3, U1.65 (PJ2(XCK3/PCINT11)), U11.4 (A2)
Shared_Address_A3: M5.17 (A3), PJ1.4, U1.66 (PJ3(PCINT12)), U11.5 (A3)
Shared_Address_A4: M5.13 (A7), PJ1.5, U1.67 (PJ4(PCINT13)), U11.6 (A4)
Shared_Address_A5: M5.14 (A6), PJ1.6, U1.68 (PJ5(PCINT14)), U11.7 (A5)
Shared_Address_A6: M5.15 (A5), PJ1.7, U1.69 (PJ6(PCINT15)), U11.8 (A6)
Shared_Address_A7: M5.16 (A4), PJ1.8, U1.79 (PJ7), U11.9 (A7)
Shared_Address_A8: M5.1 (A11), PK1.1, U1.89 (PK0(ADC8/PCINT16)), U12.2 (A0)
Shared_Address_A9: M5.2 (A9), PK1.2, U1.88 (PK1(ADC9/PCINT17)), U12.3 (A1)
Shared_Address_A10: M5.3 (A8), PK1.3, U1.87 (PK2(ADC10/PCINT18)), U12.4 (A2)
Shared_Address_A11: M5.4 (A13), PK1.4, U1.86 (PK3(ADC11/PCINT19)), U12.5 (A3)
Shared_Address_A12: M5.7 (A15), PK1.5, U1.85 (PK4(ADC12/PCINT20)), U12.6 (A4)
Shared_Address_A13: M5.11 (A14), PK1.6, U1.84 (PK5(ADC13/PCINT21)), U12.7 (A5)
Shared_Address_A14: M5.12 (A12), PK1.7, U1.83 (PK6(ADC14/PCINT22)), U12.8 (A6)
Shared_Address_A15: M5.31 (A10), PK1.8, U1.82 (PK7(ADC15/PCINT23)), U12.9 (A7)
Shared_data_D0: M5.29 (DQ7), PL1.1, U1.35 (PL0(ICP4)), U10.2 (A0)
Shared_data_D1: M5.28 (DQ6), PL1.2, U1.36 (PL1(ICP5)), U10.3 (A1)
Shared_data_D2: M5.27 (DQ5), PL1.3, U1.37 (PL2(T5)), U10.4 (A2)
Shared_data_D3: M5.26 (DQ4), PL1.4, U1.38 (PL3(OC5A)), U10.5 (A3)
Shared_data_D4: M5.25 (DQ3), PL1.5, U1.39 (PL4(OC5B)), U10.6 (A4)
Shared_data_D5: M5.23 (DQ2), PL1.6, U1.40 (PL5(OC5C)), U10.7 (A5)
Shared_data_D6: M5.22 (DQ1), PL1.7, U1.41 (PL6), U10.8 (A6)
Shared_data_D7: M5.21 (DQ0), PL1.8, U1.42 (PL7), U10.9 (A7)
TX0: J9.5, JP16.2 (B), JP22.2 (B), LED2.1 (K), PE1.2, U1.3 ((TXD0)PE1)
VGA Latch: PB1.8, R46.2, U1.26 ((OC0A/OC1C/PCINT7)PB7), U5.15 (PE)
VGA data 0: PF1.1, R16.2, U1.97 ((ADC0)PF0), U5.2 (A)
VGA data 1: PF1.2, R17.2, U1.96 ((ADC1)PF1), U5.3 (B)
VGA data 2: PF1.3, R18.2, U1.95 ((ADC2)PF2), U5.4 (C)
VGA data 3: PF1.4, R19.2, U1.94 ((ADC3)PF3), U5.5 (D)
VGA data 4: PF1.5, R20.2, U1.93 ((ADC4/TCK)PF4), U5.10 (E)
VGA data 5: PF1.6, R21.2, U1.92 ((ADC5/TMS)PF5), U5.11 (F)
VGA data 6: PF1.7, R22.2, U1.91 ((ADC6/TDO)PF6), U5.12 (G)
VGA data 7: PF1.8, R23.2, U1.90 ((ADC7/TDI)PF7), U5.14 (H)
VIN: D3.2 (A), J23.1, J114.1
VSyncVGA_RCA: PE1.5, R15.2, U1.6 ((OC3B/INT4)PE4), U2.9
WE: M3.5 (~WE), PG1.1, U1.51 ((WR)PG0)
XAA0: M3.1 (A11), PC1.1, U1.53 ((A8)PC0)
XAA1: M3.2 (A9), PC1.2, U1.54 ((A9)PC1)
XAA2: M3.3 (A8), PC1.3, U1.55 ((A10)PC2)
XAA3: M3.4 (A13), PC1.4, U1.56 ((A11)PC3)
XAA4: M3.7 (A15), PC1.5, U1.57 ((A12)PC4)
XAA5: M3.11 (A14), PC1.6, U1.58 ((A13)PC5)
XAA6: M3.12 (A12), PC1.7, U1.59 ((A14)PC6)
XAA7: M3.31 (A10), PC1.8, U1.60 ((A15)PC7)
XAA16: M3.10 (A16), PG1.4, U1.28 ((TOSC2)PG3)
XAD0: M3.21 (DQ0), PA1.1, U1.78 ((AD0)PA0), U4.9 (D7)
XAD1: M3.22 (DQ1), PA1.2, U1.77 ((AD1)PA1), U4.8 (D6)
XAD2: M3.23 (DQ2), PA1.3, U1.76 ((AD2)PA2), U4.7 (D5)
XAD3: M3.25 (DQ3), PA1.4, U1.75 ((AD3)PA3), U4.6 (D4)
XAD4: M3.26 (DQ4), PA1.5, U1.74 ((AD4)PA4), U4.5 (D3)
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

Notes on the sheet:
<-- Stop bit (1)
ATMEGA D[0..7]
Facts: NOT = delay 7-14 ns PS/2 = clock at least 30us down 30 us up 595 = SER before SRCLK^ min 25 ns SRCLK^ before RCLK^ min 19 ns SER after SRCLK^ min 0ns Strategy: negate CLK to have RSCLK^ for 595 negate RSCLK again for RCLK^ data latched (min 30us after RSCLK^ >> 19ns)
Data
SDA
<-- LSB
RX for Signal_RCA
Input / Output connector
EMS RAM 8000-9FFF A000-BFFFF (shared between Arduino and HD6309)
<-- Start bit (0)
JUNK (end of prev frame)
ATMEGA A[8..15]
I2C: GND VCC SDA SCL
PB7 is usual Arduino Mega SYSTEM_LED - with VGA it will shine full time
VGA Colors
Clock
External RAM for Arduino
SCL
ATMEGA A[0..7]
POZOR delic 440 x 1k je vypoctena hodnota (R2 R3)
SCK for Signal_RCA
came first
came last
10-20 Ohm, or diode for restricting voltage and lowering ViH under 3.4V
<-- Parity (= parity+data should be odd)
<-- MSB
Shared Memory

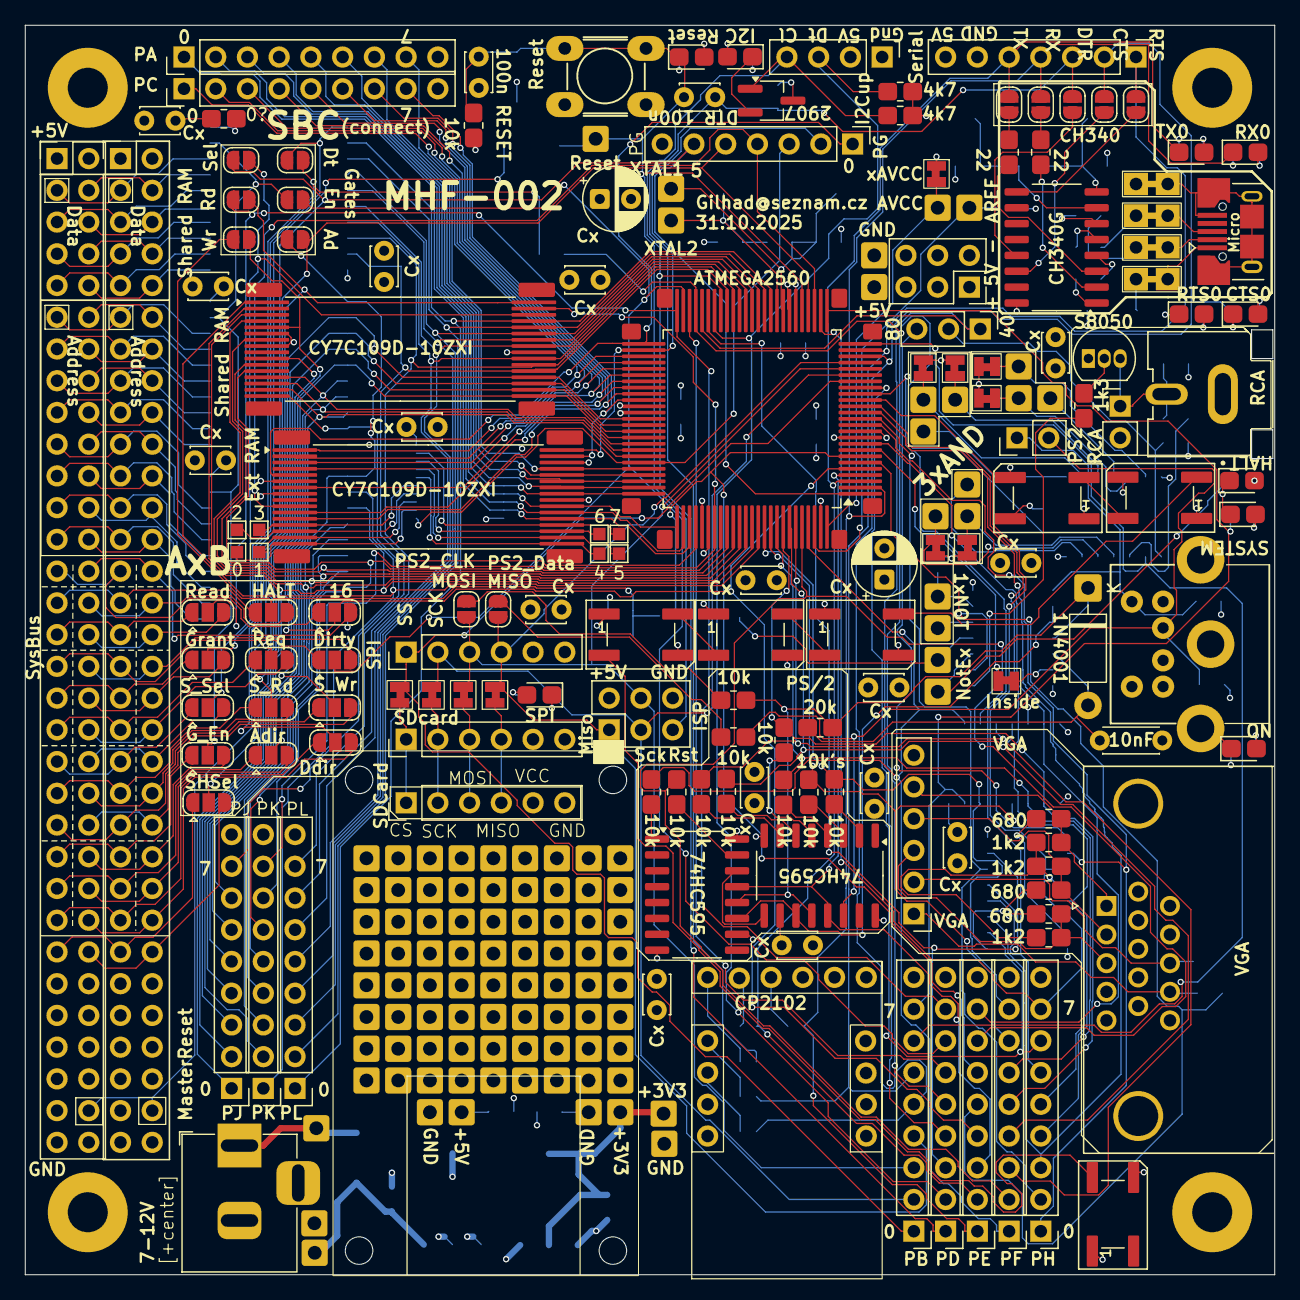
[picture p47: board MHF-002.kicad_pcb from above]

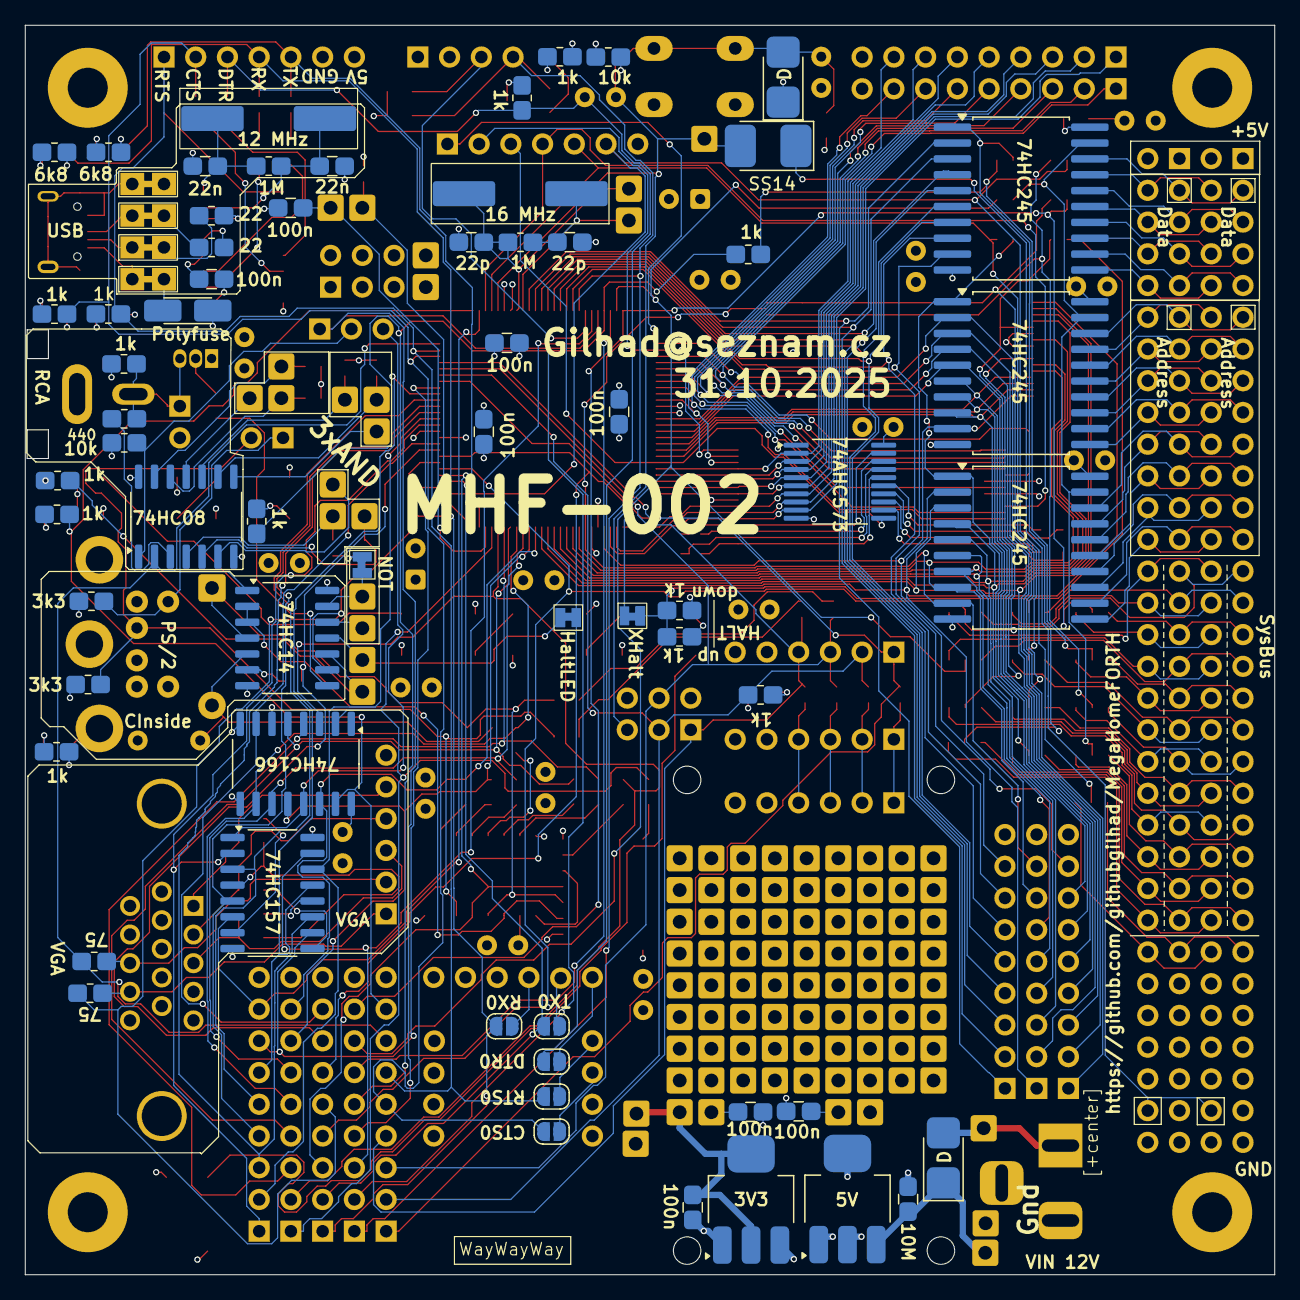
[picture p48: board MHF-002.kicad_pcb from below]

Board: 4 copper layers, 100.0 x 100.0 mm, 319 parts (67 on the bottom side), 255 nets.

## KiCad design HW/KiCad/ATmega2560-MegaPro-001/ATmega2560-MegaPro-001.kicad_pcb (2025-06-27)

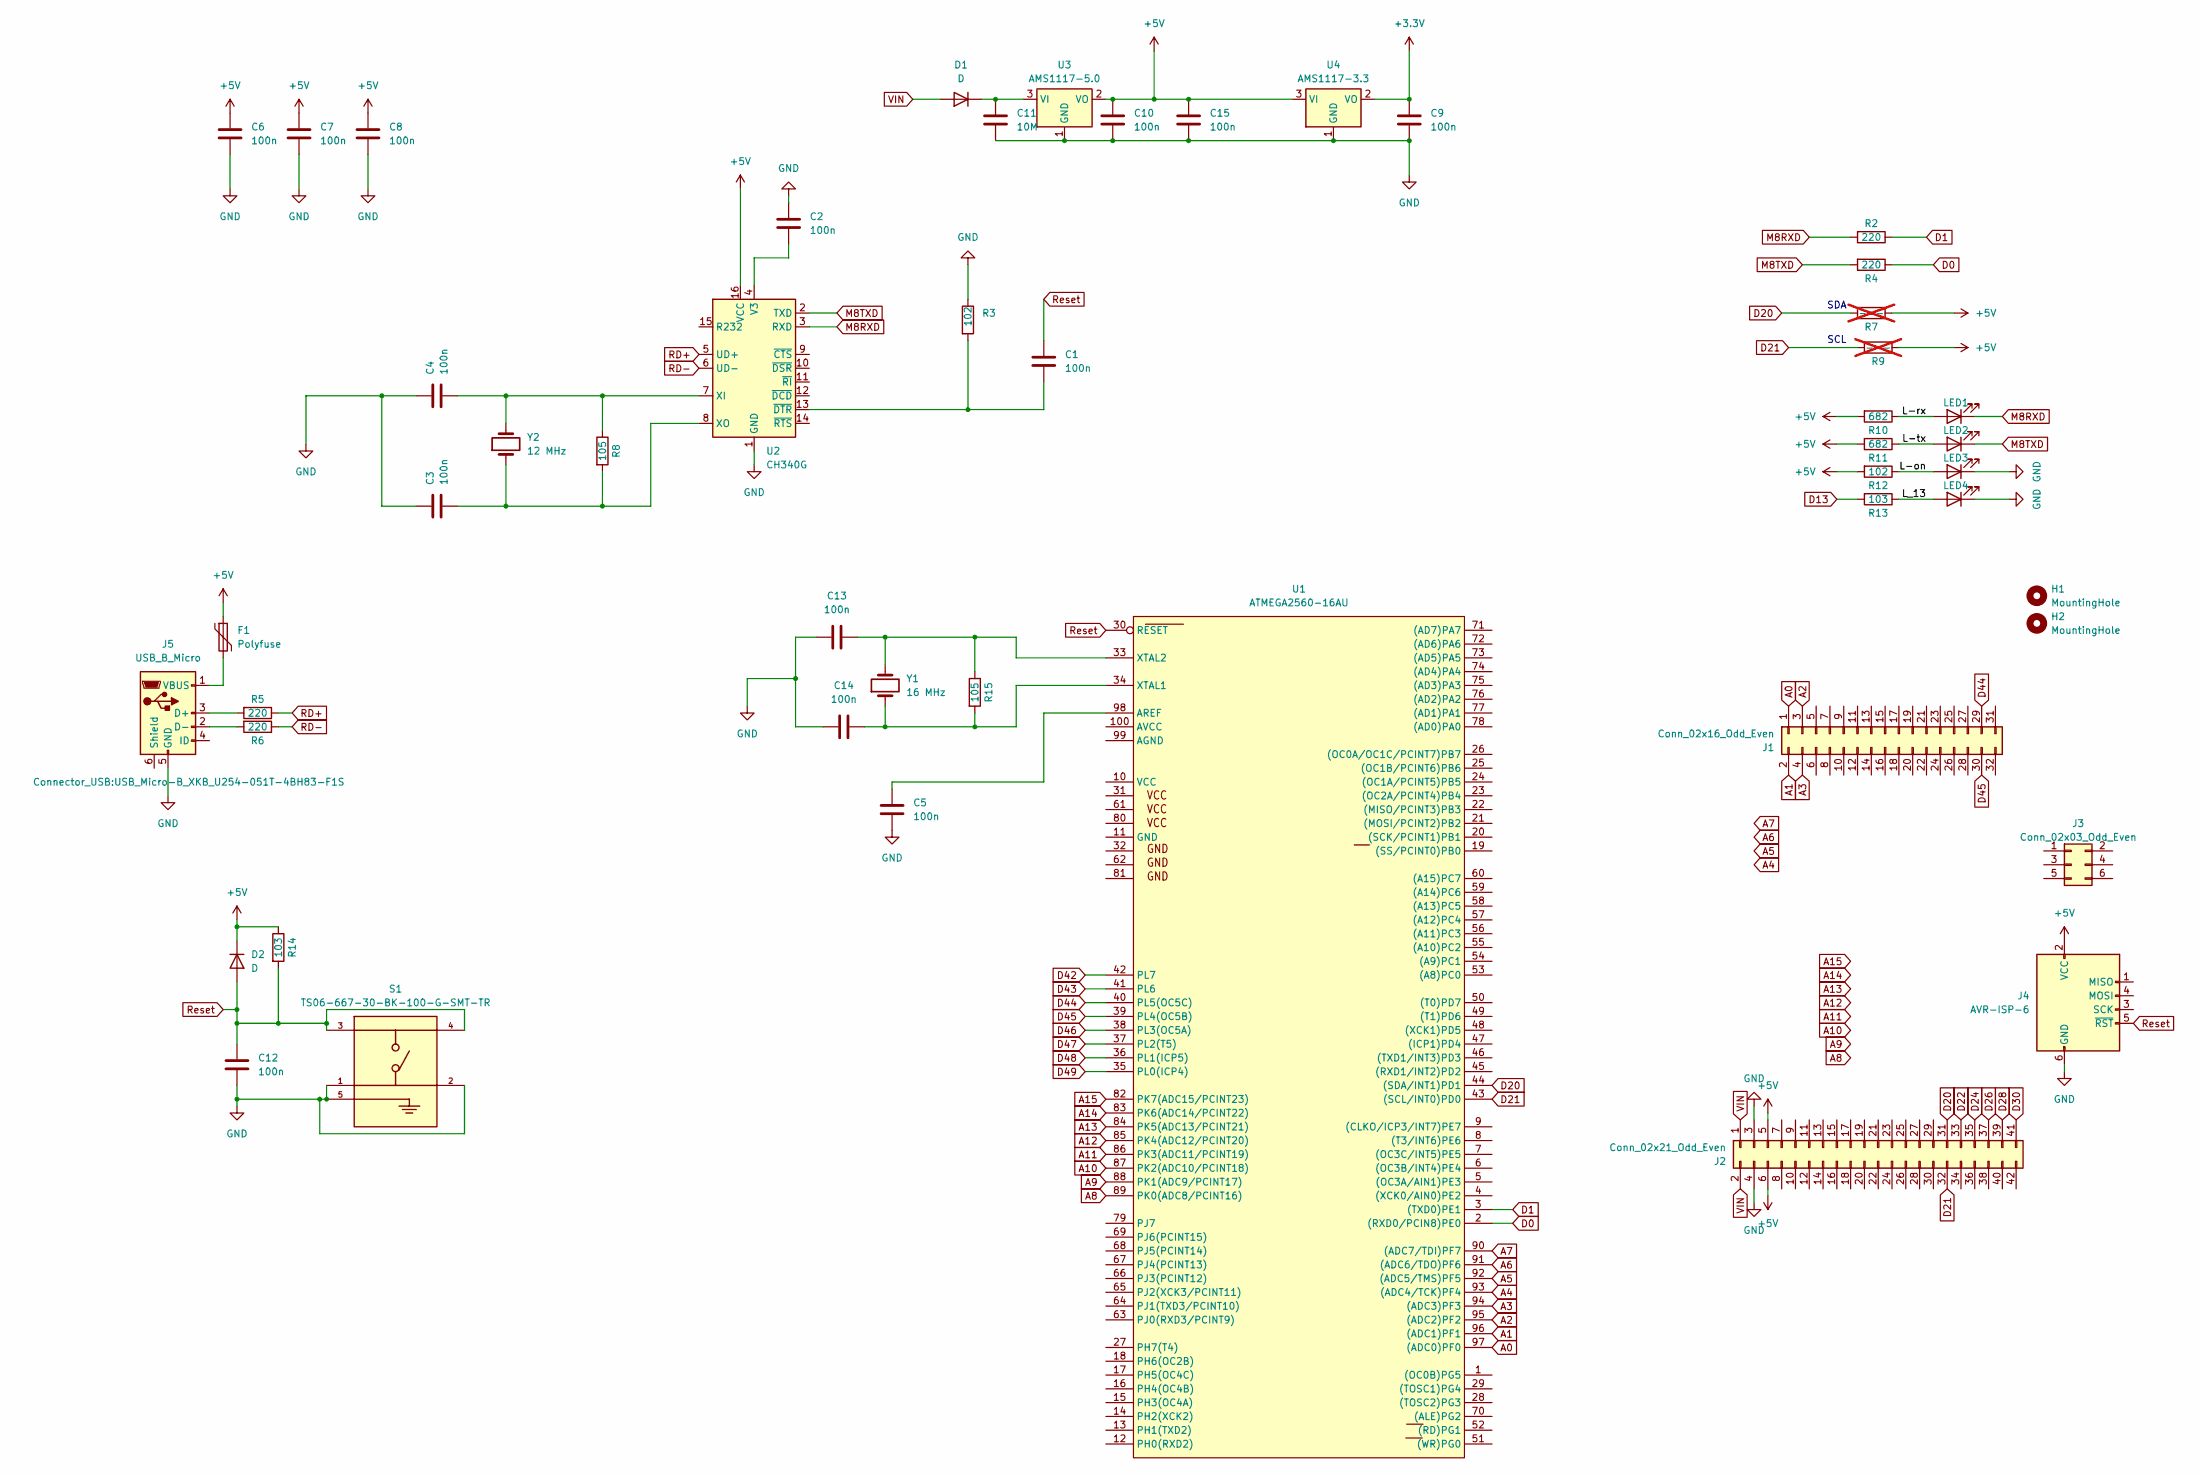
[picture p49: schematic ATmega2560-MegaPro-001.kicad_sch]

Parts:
C1, C2, C3, C4, C5, C6, C7, C8, C9, C10, C12, C13, C14, C15: 100n; C_0603_1608Metric
C11: 10M; C_1206_3216Metric
D1: D; D_1210_3225Metric
D2: D; D_1206_3216Metric
F1: Polyfuse; Fuse_1206_3216Metric_Pad1.42x1.75mm_HandSolder
H1, H2: MountingHole; MountingHole_3.2mm_M3
J1: Conn_02x16_Odd_Even; PinHeader_2x16_P2.54mm_Vertical
J2: Conn_02x21_Odd_Even; PinHeader_2x21_P2.54mm_Vertical
J3: Conn_02x03_Odd_Even; PinHeader_2x03_P2.54mm_Vertical
J4: AVR-ISP-6; PinHeader_2x03_P2.54mm_Vertical
J5: USB_B_Micro; USB_Micro-B_XKB_U254-051T-4BH83-F1S
LED1, LED2, LED3, LED4: LED; LED_0201_0603Metric
R2, R4, R5, R6: 220; R_0603_1608Metric
R3, R12: 102; R_0603_1608Metric
R7, R9: ---; R_0603_1608Metric; not fitted
R8, R15: 105; R_0603_1608Metric
R10, R11: 682; R_0603_1608Metric
R13, R14: 103; R_0603_1608Metric
S1: TS06-667-30-BK-100-G-SMT-TR; SW_TS06-667-30-BK-100-G-SMT-TR; PARTREV 1.0
U1: ATMEGA2560-16AU; TQFP-100_14x14mm_P0.5mm
U2: CH340G; SOIC-16_3.9x9.9mm_P1.27mm
U3: AMS1117-5.0; SOT-223-3_TabPin2
U4: AMS1117-3.3; SOT-223-3_TabPin2
Y1: 16 MHz; Crystal_SMD_HC49-SD
Y2: 12 MHz; Crystal_SMD_HC49-SD

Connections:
+3.3V: C9.1, U4.2 (VO)
+5V: C6.1, C7.1, C8.1, C10.1, C15.1, D2.1 (K), F1.1, J2.5, J2.6, J4.2 (VCC), R7.1, R9.1, R10.2, R11.2, R12.2, R14.1, U2.16 (VCC), U3.2 (VO), U4.3 (VI)
/L-on: LED3.2 (A), R12.1
/L-rx: LED1.2 (A), R10.1
/L-tx: LED2.2 (A), R11.1
/L_13: LED4.2 (A), R13.1
A0: J1.1, U1.97 ((ADC0)PF0)
A1: J1.2, U1.96 ((ADC1)PF1)
A2: J1.3, U1.95 ((ADC2)PF2)
A3: J1.4, U1.94 ((ADC3)PF3)
A4: U1.93 ((ADC4/TCK)PF4)
A5: U1.92 ((ADC5/TMS)PF5)
A6: U1.91 ((ADC6/TDO)PF6)
A7: U1.90 ((ADC7/TDI)PF7)
A8: U1.89 (PK0(ADC8/PCINT16))
A9: U1.88 (PK1(ADC9/PCINT17))
A10: U1.87 (PK2(ADC10/PCINT18))
A11: U1.86 (PK3(ADC11/PCINT19))
A12: U1.85 (PK4(ADC12/PCINT20))
A13: U1.84 (PK5(ADC13/PCINT21))
A14: U1.83 (PK6(ADC14/PCINT22))
A15: U1.82 (PK7(ADC15/PCINT23))
D0: R4.1, U1.2 ((RXD0/PCIN8)PE0)
D1: R2.1, U1.3 ((TXD0)PE1)
D13: R13.2
D20: J2.31, R7.2, U1.44 ((SDA/INT1)PD1)
D21: J2.32, R9.2, U1.43 ((SCL/INT0)PD0)
D22: J2.33
D24: J2.35
D26: J2.37
D28: J2.39
D30: J2.41
D42: U1.42 (PL7)
D43: U1.41 (PL6)
D44: J1.29, U1.40 (PL5(OC5C))
D45: J1.30, U1.39 (PL4(OC5B))
D46: U1.38 (PL3(OC5A))
D47: U1.37 (PL2(T5))
D48: U1.36 (PL1(ICP5))
D49: U1.35 (PL0(ICP4))
GND: C2.1, C3.1, C4.1, C5.2, C6.2, C7.2, C8.2, C9.2, C10.2, C11.2, C12.2, C13.1, C14.1, C15.2, J2.3, J2.4, J4.6 (GND), J5.5 (GND), LED3.1 (K), LED4.1 (K), R3.1, S1.1, S1.2, S1.5, U2.1 (GND), U3.1 (GND), U4.1 (GND)
M8RXD: LED1.1 (K), R2.2, U2.3 (RXD)
M8TXD: LED2.1 (K), R4.2, U2.2 (TXD)
unnamed: C11.1, D1.1 (K), U3.3 (VI)
unnamed: J5.3 (D+), R5.2
unnamed: J5.2 (D-), R6.2
unnamed: F1.2, J5.1 (VBUS)
unnamed: C5.1, U1.98 (AREF)
unnamed: C14.2, R15.2, U1.34 (XTAL1), Y1.1
unnamed: C13.2, R15.1, U1.33 (XTAL2), Y1.2
unnamed: C2.2, U2.4 (V3)
unnamed: C4.2, R8.1, U2.7 (XI), Y2.2
unnamed: C3.2, R8.2, U2.8 (XO), Y2.1
unnamed: C1.2, R3.2, U2.13 (~DTR)
RD+: R5.1, U2.5 (UD+)
RD-: R6.1, U2.6 (UD-)
Reset: C1.1, C12.1, D2.2 (A), J4.5 (~RST), R14.2, S1.3, S1.4, U1.30 (RESET)
VIN: D1.2 (A), J2.1, J2.2

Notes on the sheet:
SDA
SCL

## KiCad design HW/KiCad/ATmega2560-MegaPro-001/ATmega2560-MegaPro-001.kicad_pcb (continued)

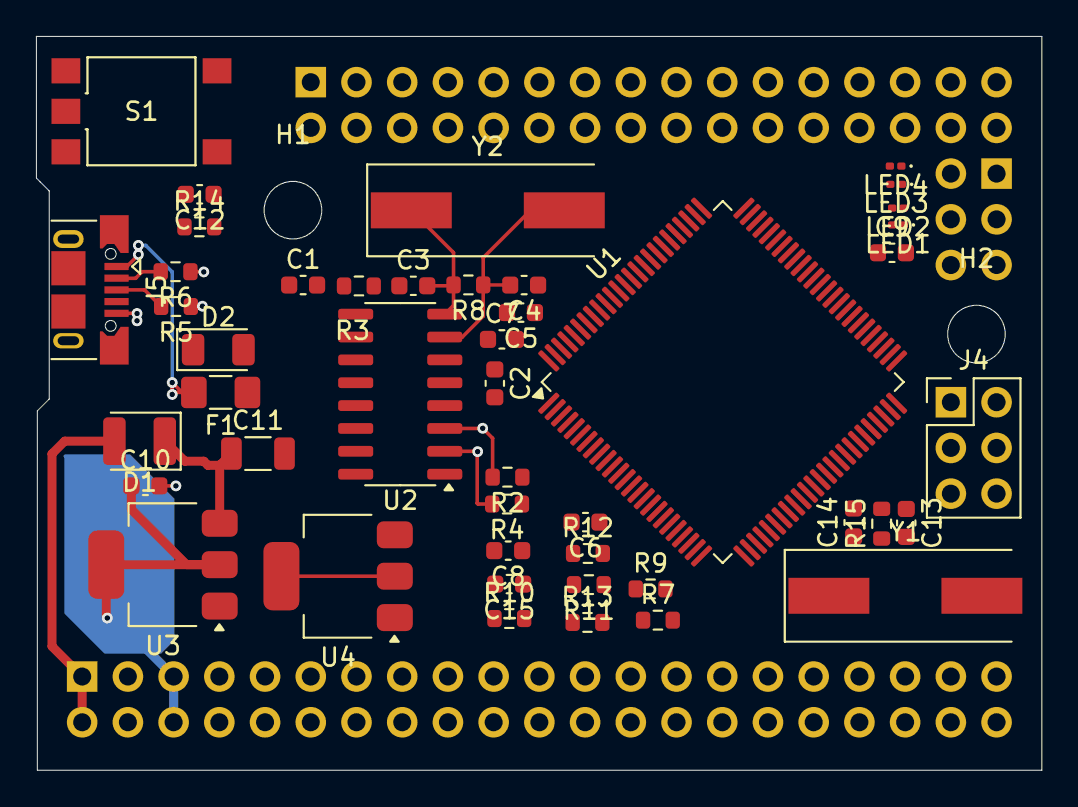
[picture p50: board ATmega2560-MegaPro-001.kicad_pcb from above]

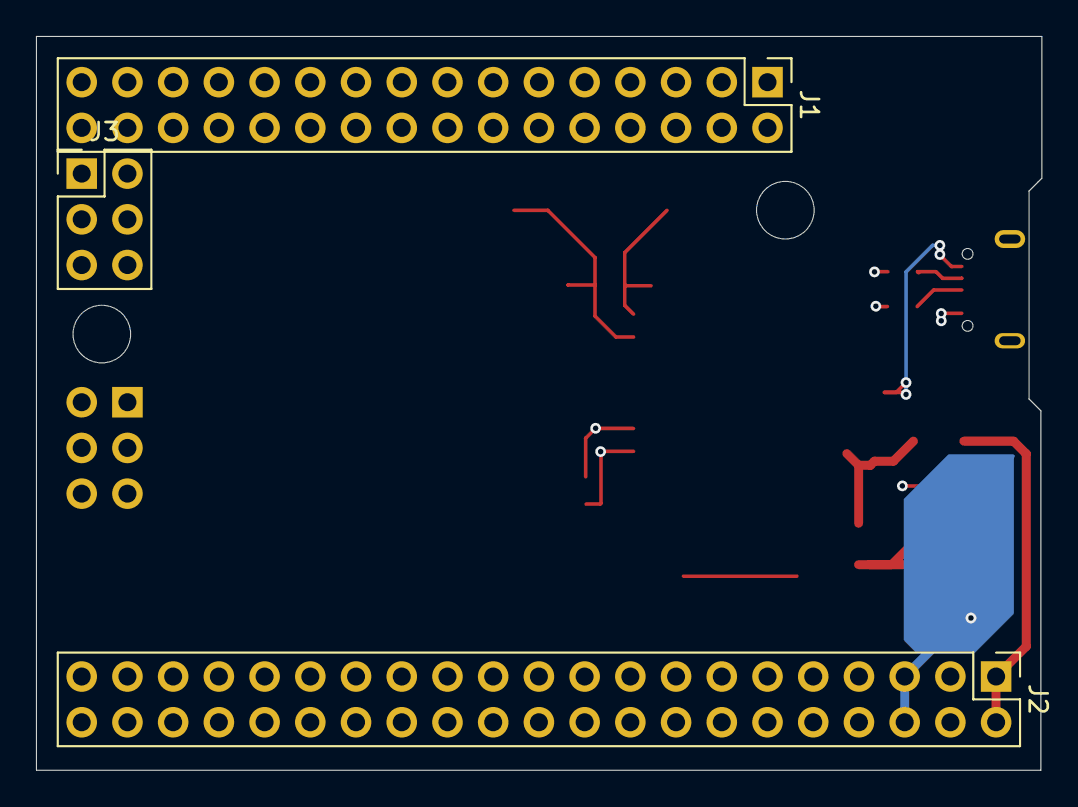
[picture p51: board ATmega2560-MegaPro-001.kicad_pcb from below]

Board: 2 copper layers, 55.9 x 40.8 mm, 50 parts (3 on the bottom side), 34 nets.

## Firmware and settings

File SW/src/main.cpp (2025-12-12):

/* vim: set noexpandtab fileencoding=utf-8 nomodified wrap textwidth=0 foldmethod=marker foldmarker={{{,}}} foldcolumn=4 ruler showcmd lcs=tab\:|- list: tabstop=8 linebreak showbreak=»\  ft=cpp */
// ,,g = gcc, exactly one space after "set"

#include <Arduino.h>
#include "version.h"
#include "bios.h"
#include "MemoryFree.h"
#include "defines.h"
/*
#include <SPI.h>
#include <SD.h>
extern File myFile;
void sd_test(){
*/



/*

  Serial.print("Initializing SD card...");

  if (!SD.begin(53)) {
    Serial.println("initialization failed!");
    while (1);
  }
  Serial.println("initialization done.");

  // open the file. note that only one file can be open at a time,
  // so you have to close this one before opening another.
  myFile = SD.open("boot.txt", FILE_WRITE);

  // if the file opened okay, write to it:
  if (myFile) {
    Serial.print("Writing to boot.txt...");
    myFile.println("testing 1, 2, 3.");
    // close the file:
    myFile.close();
    Serial.println("done.");
  } else {
    // if the file didn't open, print an error:
    Serial.println("error opening boot.txt");
  }

  // re-open the file for reading:
  myFile = SD.open("boot.txt");
  if (myFile) {
    Serial.println("boot.txt:");

    // read from the file until there's nothing else in it:
    while (myFile.available()) {
      Serial.write(myFile.read());
    }
    // close the file:
    myFile.close();
  } else {
    // if the file didn't open, print an error:
    Serial.println("error opening boot.txt");
  }
  */

/*
 }
 */
 
extern uint8_t  __data_load_end;
extern uint8_t  __DATA_REGION_LENGTH__;
//	 µFORTH
extern "C" {
	extern void my_setup();
	extern void my_loop();
extern int (*file_read)();
extern uint8_t vram[BIOS_ROWS][BIOS_COLS];
	char read_char() {
		int cc=-1;
		if (NULL != file_read) {
			cc=file_read();
			vram[0][BIOS_COLS-1]='!';
			vram[0][0]=cc;
		} else {
			vram[0][BIOS_COLS-1]='x';
		};
		if (cc >0 ) return cc;
		//
		uint16_t c=bios.get_key();
		if (c== xF12) { if(bios.current_output==BIOS_VGA) { bios.set_output(BIOS_RCA); } else { bios.set_output(BIOS_VGA);} ; return 0; };
		return c;
	}

	void write_char(char c) {
		bios << c;
	}
	void write_charA(char c) {
		bios << (c < ' ' ? '.' : c);
	}
}
void setup(){

DDRD |= _BV(0);
PORTD &= ~ _BV(0);  // I2C led on
  Serial.begin(115200);
  while (!Serial) {
    ; // wait for serial port to connect. Needed for native USB port only
  }
    Serial.println("sd_test");
    Serial.println("====== FORTH ======");
    Serial.flush();
//	sd_test();
//	bios.set_output(BIOS_RCA);              // Inicializace BIOS
	bios.set_output(BIOS_VGA);              // Inicializace BIOS
	bios.clear(' ',VGA_WHITE);
	bios.inverting=true;
	bios << YX(1,2) << COLOR(VGA_YELLOW) << F(" **** Mega Home FORTH **** ");
	bios << YX(2,2) << COLOR(VGA_GREEN) << F("Free: RAM: ") << freeMemory() << F(" B; FLASH: ") << uint32_t(HEX_MAXIMUM_SIZE - (uintptr_t)&__data_load_end) << F(" B");
	bios << YX(3,2) << COLOR(VGA_CYAN) << F("Used: FLASH ") <<  (uintptr_t)&__data_load_end << F(" / ") << uint32_t(HEX_MAXIMUM_SIZE) << F(" B");
	bios << YX(4,2) << F("Screen size: ") <<COLOR(VGA_GREEN) << ' ' << BIOS_COLS << 'x' << BIOS_ROWS;
	bios << YX(5,2) << COLOR(VGA_GRAY+VGA_B_WHITE) << F("Compiled: " _DATE_ " " __TIME__ " \r\n");
	bios << COLOR(VGA_BLACK+VGA_B_GRAY) <<(F(VERSION_STRING ));
	bios <<(F("  based on " VERSION_COMMIT " - " VERSION_MESSAGE  "\r\n"));
	bios << COLOR(VGA_B_GREEN + VGA_RED) << (F("---- ==== #### FORTH #### ==== ---- \r\n"));
	bios << COLOR(VGA_none) <<(F("Hint: 0 nodebug 0 noinfo 0 notrace LAST D@ 20 + dump  \r\n"));
#if defined(__AVR_ATmega2560__)
	bios <<(F("Hint: hex ff DDRF !C aa PORTF !C ff DDRK !C aa PORTK !C : x ff  PINF !C ff  PINK !C ; x  \r\n"));
	bios <<(F(": count- 0 BEGIN DUP c2C PORTF !C PORTK !C 1- DUP 0= UNTIL c2C PORTF !C PORTK !C ; \r\n"));
	bios <<(F(": count+ 0 BEGIN DUP c2C PORTF !C PORTK !C 1 + DUP 0= UNTIL c2C PORTF !C PORTK !C ; \r\n"));
#endif
	bios <<(F("Test: : xx 0BRANCH [ 0 0C , ] 0 ; : xxx IF 1111 ELSE 2222 FI 3333 + ; \r\n")); 
	bios << COLOR(VGA_GRAY)
	<< F(
	STR_2LESS "<" // '«'
	STR_2MORE ">" // '»'
	STR_UP "^" // '^'
	STR_DOWN "v" // 'v'
	STR_LEFT "<-" // '«-'
	STR_RIGHT "->" // '-»'
	"\r\n"
	) << COLOR(VGA_none)  ;
	while (!bios.get_key()){;};

	my_setup();
	bios <<(F("Setup done"));
}

void loop(){
	my_loop();
}

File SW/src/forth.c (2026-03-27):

/* vim: set ft=cpp showbreak=»\  noexpandtab fileencoding=utf-8 nomodified wrap textwidth=0 foldmethod=marker foldmarker={{{,}}} foldcolumn=4 ruler showcmd list: lcs=tab\:|- tabstop=8 linebreak  */
// ,,g = gcc, exactly one space after "set"
#include <stdint.h>
#include <stddef.h>
#include <string.h>
#include <stdbool.h>
#include <stdlib.h>
#include "flags.h"
#include "ptr24.h"
#include "io.h"
#include "debug.h"
#ifdef __PC__
	#include "memdump.h"
	#include <stdio.h>
	#define PEDANT
	#include <unistd.h>
#endif
extern void ff_SD();
extern void ff_SD_CAT(char * name);
extern void ff_SD_TYPE(char * name);
void wx(const char * p) { write_str((const __memx char *)p);}

extern uint8_t B1at(uint32_t p);			// asm.S	read 1 byte at address p (somewhere), return 1 byte
extern uint16_t B2at(uint32_t p);			// asm.S	read 2 bytes at address p (somewhere), return 2 bytes
extern uint32_t B3at(uint32_t p);			// asm.S	read 3 bytes at address p (somewhere), return 4 bytes (top cleared)
extern uint32_t B4at(uint32_t p);			// asm.S	read 4 bytes at address p (somewhere), return 4 bytes
extern const __memx void * B3PTR(uint32_t p);		// asm.S	typecast, get 3 bytes, return 4 bytes (top cleared)
extern uint32_t B3U32(const __memx void * p);		// asm.S	typecast, get 3 bytes, return 4 bytes (top cleared)
extern void jmp_indirect_24(uint32_t p);		// asm.S	call function, which byte_address is at address p (somewhere) (converts bytes to words)

/*
 * Decision:
 * 	cell = uint16_t
 * 	pointer = uint32_t, but only 3B used, 4.B always zero
 */

_Static_assert(sizeof(uint32_t) == 4, "uint32_t must be 32 bits");
#if defined(__AVR_ATmega328P__) || defined(__AVR_ATmega2560__)
_Static_assert(sizeof(const __memx void *) == 3, "const __memx void * must be 24 bits");
#elif defined(__PC__)
_Static_assert(sizeof(const __memx void *) == 4, "const __memx void * must be 32 bits");
void do_traceback();	// forward
extern char a_read_char();

char read_char() {
	char c=a_read_char();
	if (c==0x7E) do_traceback();
	return c;
}

#else
#error undefined
#endif

void write_num8(uint8_t n) {	// {{{
	if (n>99) {
		write_char('0'+ n/100);
		n=n % 100;
		};
	if (n>9) {
		write_char('0'+ n/10);
		n=n % 10;
		};
		write_char('0'+n);
}	// }}}
char buf[32];	// temporary buffer - stack eating structures cannot be in NEXT-chained functions, or stack will overflow !!!

/** {{{ Intro
 * Lets start programming FORTH
 * My idea is
 * 	* Indirect Threading
 * 	* long names for words
 * 		* well, possibly more than just 3 (of nano Forth)
 * 		* strictly less then 32 (so Pascal Length can be found backward)
 * 		* only ASCII chars allowed (from space=0x20 upt to tilda=0x7F)
 * 		*
 * 	* some FORTH words will be in FLASH
 * 		* so 3+ bytes pointers are needed
 * 		* 3 bytes pointers are problematic and __memx is tricky, so let use uint32_t instead and few asm utils
 * the header is divided into two parts, first is for dictionary, followed second, which is for runing words
 * C discourse
 * 	* first we need 3bytes pointer to something
 * 		* it will be memory, but maybe RAM, maybe FLASH
 * 		* it will be
 * 			* byte in memory - uint8_t (just the memory itself after all)
 * 			* 3bytes pointer in memory (usually pointer to some other word)
 * 			* const char (for easy string manipulation)
 * 			* 3B pointer to function in FLASH (well it could be 2B on 328, but not on 2560, and we will use it together with other 3B pointers, so make ++/-- easy)
 * 			* anything else, which can be (type casted) at will
 * */ // }}}
/*
typedef const __memx void(*CodeWord_t)();	// CodeWord_t is 2B pointer to function (in FLASH) (*CodeWord_t)() calls the function.
typedef const __memx CodeWord_t (*Data_t);	// Data_t is 3B pointer to CodeWord_t "somewhere"
typedef const __memx Data_t (* InstrPoint_t);	// InstrPoint_t is 3B pointer to Data_t "somewhere"
typedef void const __memx *PTR_t;	// universal 3B pointer to any data "somewhere"
typedef uint16_t CELL_t;	// cell on data stack 2B

typedef const __memx char *xpC;	// 3B pointer 1B target	pointer "somewhere" to char "somewhere"
typedef const __memx uint8_t *xpB;	// 3B pointer 1B target	pointer "somewhere" to byte "somewhere"
typedef const __memx uint32_t *xpD;


typedef struct head1_t {	// {{{
	const __memx struct head1_t *next;		// 3B: pointer to next header "somewhere"
	uint8_t fill; // to 4B pointer
	uint8_t flags;		// 1B:
	uint8_t len;		// 1B: up to 31 (=5bits)
	const char name[];	// len B:name of WORD
} head1_t;	// }}}
typedef const __memx head1_t	*xpHead1;	// 3B pointer to head1 "somewhere"
*/
/*
 * typedef struct head2 {	// {{{
 * 	CodeWord_t codepoint;	// 3B: pointer to function to interpret data
 * 	Data_t data[];	// 3B: pointer to 2B pointer "somewhere" to function to interpret data - pointer to head2 "somewhere"
 * 	} head2;	// }}}
 */

typedef const __memx void(*CodeWord_t)();	// CodeWord_t is 2B pointer to function (in FLASH) (*CodeWord_t)() calls the function.
typedef const __memx CodeWord_t (*Data_t);	// Data_t is 3B pointer to CodeWord_t "somewhere"
typedef const __memx char *xpC;	// 3B pointer 1B target	pointer "somewhere" to char "somewhere"
typedef struct head1_t {	// {{{
	const __memx struct head1_t *next;		// 3B: pointer to next header "somewhere"
#if defined(__AVR_ATmega328P__) || defined(__AVR_ATmega2560__)
	uint8_t fill; // to 4B pointer
#endif
	uint8_t flags;		// 1B:
	uint8_t len;		// 1B: up to 31 (=5bits)
	const char name[];	// len B:name of WORD
} head1_t;	// }}}
typedef const __memx head1_t	*xpHead1;	// 3B pointer to head1 "somewhere"


typedef uint32_t PTR_t; 	// universal "3B pointer" to any data "somewhere" - use B1at, B3at for dereferencing
typedef uint16_t CELL_t;	// cell on data stack 2B
typedef int16_t S_CELL_t;	// signed cell on data stack 2B
typedef uint32_t DOUBLE_t;	// 2 cell on data stack 4B
typedef int32_t S_DOUBLE_t;	// signed 2 cell on data stack 4B
typedef uint8_t  BYTE_t;	// something for pointers to points to

PTR_t		IP;	// pointer to element of data[], which should be next
PTR_t		DT;	// NEXT is **(IP++)() - so DT=*IP as internal step. DT is value of last data pointed by IP before NEXT (= address of codepoint to exec) (used by f_docol to know, from where it was called) -  f_docol= { Rpush(IP);IP=DT + x; NEXT} x=sizeof(codeword)
/*
 * STACKS:
 *   for now I will use array and index, as it is easy to check range and only pop/push should be affected
 *   also lets start with small value, so it can be tested for both under- and over- flow
 *   also let push grow up and pop go down and 0 is empty stack (so push(x){stck[stack++]=x;}
 */
CELL_t		stck[STACK_LEN];
uint16_t	stack=0;
PTR_t		Rstck[RSTACK_LEN];
uint16_t	Rstack=0;

/*
 * RAM:
 * now let it be just small array too
 * and test it until all works
 */
uint8_t RAM[RAM_LEN];
uint32_t HERE;
//const __memx uint8_t *HERE;

/*
 * LAST
 * pointer to begin of last header
 */
PTR_t LAST;
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

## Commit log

2025-06-17 check, what NanoHomeComputer SW uses, timers
2025-06-19 timers - pins table
2025-06-19 timers - pins table fixed
2025-06-19 Timers and pins table + some assignemnts
2025-06-21 _nano.4th for pin assignment tests
2025-06-25 Arduino Mega Pro - begin
    [MHF-001.kicad_pcb, MHF-001.kicad_sch]
2025-06-25 ATmega2560-MegaPro-001 schema
    [ATmega2560-MegaPro-001.kicad_sch]
2025-06-27 +3d models, +Pins.rst, some reorganisation
    [ATmega2560-MegaPro-001.kicad_pcb, ATmega2560-MegaPro-001.kicad_sch, CUI_DEVICES_TS06-667-30-BK-100-G-SMT-TR.step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]
2025-07-04 8bitComp schema updated
    [Schema-8bitComp.kicad_sch]
2025-07-04 +Comp24 footprint
    [MHF-001.kicad_pcb, MHF-001.kicad_sch]
2025-07-04 - mounting holes
    [MHF-001.kicad_pcb, MHF-001.kicad_sch]
2025-07-05 some labels
    [MHF-001.kicad_sch]
2025-07-06 schema MHF-001 maybe OK
    [MHF-001.kicad_pcb, MHF-001.kicad_sch]
2025-07-06 saved lot of pins by removing unnecessery/redundant signals
    [MHF-001.kicad_pcb, MHF-001.kicad_sch]
2025-07-12 added some connectors
    [MHF-001.kicad_pcb, MHF-001.kicad_sch]
2025-07-12 Final placement of parts (I hope)
    [MHF-001.kicad_pcb, MHF-001.kicad_sch]
2025-07-13 WayWayWay and other final touches
    [MHF-001.kicad_pcb, MHF-001.kicad_sch]
2025-07-13 XTALs, AVCC, AREF
    [MHF-001.kicad_pcb, MHF-001.kicad_sch]
2025-07-14 gerber files
2025-08-01 photos and tests
    [MHF-002.kicad_pcb]
2025-08-02 VGA screen stabilised
    [MHF-002.kicad_sch]
2025-08-14 external memory
    [MHF-002.kicad_pcb, MHF-002.kicad_sch]
2025-08-30 added SPI + SD libraries from Arduino for hacking
2025-08-30 FAKE millis - SD seems to work
2025-09-05 WORDSP ; fix 4+ -> 4D+
    [forth.c]
2025-09-06 .D - prints DOUBLE; strankovani slov
2025-09-09 emtestmanual OK, emtestauto fail and reset - IMHO faulty HW
    [forth.c]
2025-09-09 link to PCBway
2025-09-12 footprints for HandSoldering, some schema modifications
    [MHF-002.kicad_sch]
2025-09-22 +cp2102 +SDCard
    [MHF-002.kicad_pcb, MHF-002.kicad_sch, RCJ-047.step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]
2025-09-23 more small fixes
    [MHF-002.kicad_pcb, MHF-002.kicad_sch]
2025-09-24 fixing small problems
    [MHF-002.kicad_pcb, MHF-002.kicad_sch]
2025-10-01 footprints (maybe complete)
    [MHF-002.kicad_pcb, MHF-002.kicad_sch]
2025-10-02 RCA video somehow works, but eats PS/2, need more fixes
    (cherry picked from commit 65ca875b51632968f30175eec0eb6f11a6a396ee)
    [main.cpp]
2025-10-04 included all planned improvements
    [MHF-002.kicad_pcb, MHF-002.kicad_sch]
2025-10-08 MHF-002 routing full PCB, need add texts
    [MHF-002.kicad_pcb, MHF-002.kicad_sch]
2025-10-09 PDF for Cu+Silkscreen+Courtyards
2025-10-10 improved SystemBus and 3xAND, NOT
    [MHF-002.kicad_pcb, MHF-002.kicad_sch]
2025-10-11 3xAND routed
    [MHF-002.kicad_pcb]
2025-10-13 D-Latch testpoints
    [MHF-002.kicad_pcb, MHF-002.kicad_sch]
2025-10-15 reset + I2C LED
    [MHF-002.kicad_pcb, MHF-002.kicad_sch]
2025-10-17 Final version of HW MHF-002
    [MHF-002.kicad_pcb, MHF-002.kicad_sch]
2025-10-18 redesigned PS/2 and RCA to 40/80 char sources, need route
    [MHF-002.kicad_pcb, MHF-002.kicad_sch]
2025-10-18 renumbered RAMs
    [MHF-002.kicad_pcb, MHF-002.kicad_sch]
2025-10-18 more renumbering
    [MHF-002.kicad_pcb, MHF-002.kicad_sch]
2025-10-29 Silkscreen, views
    [MHF-002.kicad_pcb, MHF-002.kicad_sch, Schema-8bitComp.kicad_sch]
2025-10-31 Generated Gerber files (PCBway needs names In1 I2 instead of VCC and GND)
    [MHF-002-B_Cu.gbr, MHF-002-B_Mask.gbr, MHF-002-B_Paste.gbr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]
2025-12-12 +pictures, VGA pin change
